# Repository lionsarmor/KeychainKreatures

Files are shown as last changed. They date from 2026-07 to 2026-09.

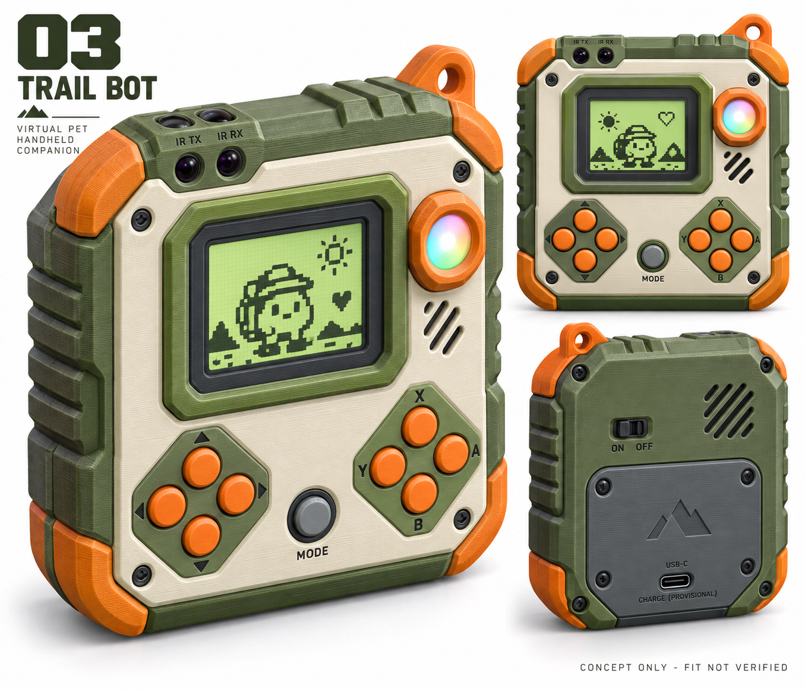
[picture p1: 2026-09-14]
docs/enclosure_concepts/03_trail_bot.png

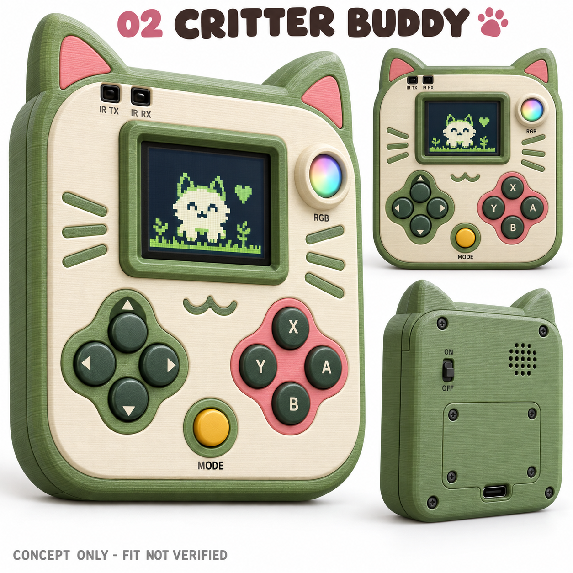
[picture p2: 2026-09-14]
docs/enclosure_concepts/02_critter_buddy.png

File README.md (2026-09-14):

# Keychain Kreatures

An ESP32-S3 virtual-pet and small handheld-game hardware project, designed around a repairable through-hole main-board kit and a separate factory-assembled power board.

**Current hardware: main C.6 + power P.4. Engineering prototypes—not a tested, certified or production-ready toy.** Main is 96 × 105 × 1.6 mm; power is now 50 × 50 × 1.6 mm. The power board needs independent removable case supports; mounting patterns do not match. Physical component fit, battery/case selection, factory DFM approval and powered qualification remain open.

## Current projects and downloads

| Board | Editable KiCad 10 project | Five-prototype review package | Gerbers and drills |
|---|---|---|---|
| Main C.6 · 2 copper layers | [Open main project](KK_main_module/KK_main_module.kicad_pro) | [Full main ZIP](KK_main_module/manufacturing/KK_MAIN_C6_P4_PAIRING_5_PROTOTYPE_REVIEW_2026-09-12.zip) | [Main fabrication ZIP](KK_main_module/manufacturing/KK_MAIN_C6_P4_PAIRING_GERBERS.zip) |
| Power P.4 · 4 copper layers | [Open power project](KK_power_module/KK_power_module.kicad_pro) | [Full power ZIP](KK_power_module/manufacturing/KK_POWER_P4_5_PROTOTYPE_REVIEW_2026-09-12.zip) | [Power fabrication ZIP](KK_power_module/manufacturing/KK_POWER_P4_GERBERS.zip) |

Download the repository or a **full review ZIP** to open a project with its local libraries, models and documentation. Install the KiCad 10 standard footprint and 3D libraries as well. For GitHub ZIP downloads, use the file page's download/raw action. The full review packages include fabrication files, BOMs, placement and test-point maps, schematic/assembly PDFs, source CAD, datasheets and verification evidence. The separate fabrication ZIPs do not replace the assembler's full review package.

[Start here](START_HERE.md) · [Documentation index](docs/README.md) · [Release notes](CHANGELOG.md) · [Release hashes](docs/CURRENT_RELEASE_INDEX.json)

Ordering the five engineering samples? Use the [PCBWay step-by-step submission folder](PCBWay/README.md): separate main/power Gerber uploads, power BOM/centroid, DFM questions, approval checklist and delivery/testing documents. This is a local preparation packet, not an order or manufacturing approval.

## Hardware in this revision

- Socketed **ESP32-S3 SuperMini**. Confirm the delivered seller revision, pinout and actual flash/PSRAM; do not infer N16R8 specifications from the SuperMini name.
- Existing ST7789V2 screen in landscape, **280 × 240 pixels**, and a separate socketed 3.3 V microSD reader. SD storage is not extra executable RAM.
- Nine soft controls: D-pad left, four action buttons right, one center function button, all below the screen. MCP23017 GPIO expansion.
- PWM audio with a TDA2822L amplifier, speaker connector and switched amplifier supply; vibration motor output with suppression.
- TSAL6200 infrared transmitter and TSOP38238 receiver, aimed toward the case opening. No sub-GHz radio.
- Separate socketed common-anode RGB LED and TLC5916 driver.
- Main board: **98 fitted through-hole positions**, all **43 resistors horizontal**, ten horizontal low-profile electrolytics, six flat-mounted TO-92 devices, removable IC/module sockets, JST connectors and **25 bare debug holes**.
- Power board: **108 fitted positions**, 28 rear test pads, USB-C charging input, battery protection, temperature interlock and three regulated output rails. This board is a **factory SMT subassembly**, not a student SMT soldering exercise.

All fitted electrical positions have resolving 3D model links. Some module and connector envelopes remain provisional; model coverage does not prove fit. Sockets, buttons and optical components necessarily retain height. The previous common-hole 20 mm spacer plan is superseded. Power placement, antenna clearance and independent support heights need a physical mock-up.

## Assembly and first power-up

New to electronics, or investigating a board that will not start? Use the [board-by-board troubleshooting guides and recording sheets](docs/troubleshooting/README.md). Begin with safety and unpowered checks; power-module live tests need a qualified instructor.

Read these before buying parts, soldering or powering a board:

1. [Main BOM and assembly/wiring guide](KK_main_module/assembly/ASSEMBLY_GUIDE.md), [reference BOM](KK_main_module/assembly/C6_BOM_BY_REFERENCE.csv), and [complete paired-kit extras](KK_main_module/assembly/C6_COMPLETE_KIT_EXTRAS.csv). Extras cover sockets, modules, mating plugs, wiring and provisional hardware; count them once per main+power pair.
2. [Print the stack review at actual size](docs/C6_P4_MECHANICAL_REVIEW.pdf), [front fit sheet](KK_main_module/assembly/C6_front_FIT_100_PERCENT.pdf) and [rear fit sheet](KK_main_module/assembly/C6_back_FIT_100_PERCENT.pdf). Measure the calibration line and dry-fit actual parts and plugged harnesses.
3. [Power fabrication/assembly requirements](KK_power_module/FABRICATION_REQUIREMENTS.md). Obtain manufacturer approval of the 0.4 mm WCSP, fine-pitch packages and **filled/capped/planarized via-in-pad** process. Ordinary via tenting is not equivalent.
4. [Power electrical review and current-limited first-power-up procedure](KK_power_module/assembly/P4_REVIEW_AND_TEST.md). Qualify power independently before attaching the populated main board. Real-cell testing requires a selected, documented cell and bonded thermistor.

Power **J3 → main J1**, keyed pin-for-pin:

| Pin | Rail |
|---|---|
| 1 | MCU_5V |
| 2 | GND |
| 3 | LOGIC_3V3 |
| 4 | ACT_3V2 |

**Never connect raw battery voltage to main J1. Power TP3/BAT_NEG is not TP4/GND; do not bypass battery protection with test-equipment grounds. Neither speaker output is ground.**

Charger USB carries **no data** to the ESP32. Do not combine ESP32 USB power and external main rails until exact-module reverse-feed behavior is qualified. Program the removable MCU separately for recovery. USB-A/default charging is deliberately slow and may not cover a running toy's load.

## Verification and remaining work

The issued C.6/P.4 sources passed fresh native ERC/DRC, connectivity and schematic-parity checks with **zero reported violations or opens**. [Static audit](docs/CURRENT_STATIC_AUDIT.json), [individual outline/hole audit](docs/CURRENT_STATIC_AUDIT.json) and package manifests identify exactly what was checked. Existing ignored-check settings are included in the native reports; clean reports are not a claim that every possible check was performed.

Run this lightweight saved-release consistency check from the repository root:

```sh
node tools/check_project.mjs
```

It verifies current source/package hashes, local assets, saved netlists and the inter-board interface. It does **not** rerun KiCad checks or simulate the circuit. See [tool instructions](tools/README.md) before running anything else. Do not rerun historical placement/route generators on finished CAD.

Remaining qualification includes physical socket/plug/case fit, battery/NTC selection, speaker power rating, simultaneous-load capacity, capacitor transient/ripple behavior, regulator/charger temperatures, USB behavior, rail sequencing, GPIO back-powering, RF performance and applicable product safety/EMC review. In particular, the older main 3.3 V reservation was 0.5 A while power screening used 0.4 A; reconcile measured peak demand and margin before approving the complete toy. Screening targets are not measured ratings.

## Firmware status

The planned virtual pet, games/apps, browser/Wi-Fi uploads, trading, save recovery and OTA workflow are **not implemented or validated by this hardware release**. Follow the current schematic and assembly guide for bring-up firmware. The historical ESP32-C3/MAX98357A/PCF8574 test sketch from earlier Git history is not compatible with this S3/MCP23017/TDA2822L board and must not be used as its factory test.

## History, contributions and licensing

The files directly inside **KK_main_module are now C.6**, and those directly inside **KK_power_module are P.4**. Older C.5/P.2 projects, intermediate routes, obsolete documents and one-off generators have been moved into [the cleanup archive](revisions/2026-09-12_current_only/). Use [revisions](revisions/README.md) for recovery; archived reports retain their original findings and are not current instructions. See [contribution guidance](CONTRIBUTING.md).

The project is intended for open development, but a project-wide license has **not yet been selected**. The OSHW silkscreen logo is not a certification or a substitute for license terms. Third-party KiCad assets and manufacturer documents retain their respective terms; do not assume this repository relicenses them. Thanks to the KiCad, Espressif and component-library communities.

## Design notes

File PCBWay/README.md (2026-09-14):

# PCBWay — C.6 main + P.4 power prototype submission

Start with [00_Order_Setup/START_HERE.md](00_Order_Setup/START_HERE.md). This folder prepares **two separate PCBWay jobs**: five bare main boards and five assembled power boards. It does not place an order or authorize fabrication.

| Step | Folder | What to do |
| --- | --- | --- |
| 0 | [Order setup](00_Order_Setup/START_HERE.md) | Read specifications and copy the quote-request message. |
| 1 | [Main Gerbers](01_Main_C6/01_Gerber_Upload/README.md) | Upload the main Gerber ZIP to its own PCB job. |
| 2 | [Power Gerbers](02_Power_P4/01_Gerber_Upload/README.md) | Upload the power Gerber ZIP to a separate four-layer PCB + assembly job. |
| 3 | [Power BOM](02_Power_P4/02_BOM_Upload/README.md) | Upload the fitted-parts BOM; ask for sourcing/attrition quote. |
| 4 | [Power placement](02_Power_P4/03_Pick_and_Place_Upload/README.md) | Upload SMT centroid and attach mixed-operations file. |
| 5 | [Assembly drawings](02_Power_P4/04_Assembly_Drawings/README.md) | Attach polarity, schematic and assembly references. |
| 6 | [Manufacturing review](03_Factory_DFM_and_Questions/README.md) | Resolve process, sourcing and inspection questions. |
| 7 | [Approval and payment](04_Approval_and_Payment/README.md) | Review final quote and CAM/BOM approvals before payment/release. |
| 8 | [Delivery and testing](05_Delivery_and_Testing/README.md) | Retain inspection results and test samples safely on arrival. |

Use the files listed in [UPLOAD_MAP.csv](00_Order_Setup/UPLOAD_MAP.csv). The complete package ZIPs under each board's `05_Full_Review_Package` folder are supplemental engineering references, **not** the Gerber-upload ZIPs. Folder numbering follows this project's workflow, not a promise of PCBWay's exact current screen order.

**Do not upload the entire project or this whole folder to a Gerber field.** Do not mix the two board designs in one upload or order five of each archive separately. Main assembly is not requested; its extra BOMs are reference only. No shell, battery, firmware programming or finished toy is ordered here.

Current source-of-truth remains the root KiCad projects and issued manufacturing packages. The PCBWay copies are a submission snapshot. `SOURCE_COPY_MANIFEST.json` records byte-identical source copies; `PACKAGE_MANIFEST.json` inventories the prepared files. Recheck these if the design changes. Keep supplier responses and receipts in the provided folders; never overwrite issued Gerbers with returned CAM changes without review.

Status: **ready for quote/DFM submission, not manufacturer-approved, not powered-tested**. Copies of saved verification reports are evidence of static checks, not functional certification.

Prepared against [PCBWay's assembly file requirements](https://www.pcbway.com/assembly-file-requirements.html) and [via-in-pad guidance](https://www.pcbway.com/helpcenter/ordering_parameter_instruction/Via_in_Pad.html). Technical approval is still required for this particular design.

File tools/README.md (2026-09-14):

# Current-project tools

- `package_pcbway.py`: prepares the root `PCBWay` submission folder from the unchanged issued release. Copies Gerber/review ZIPs and supporting files byte-for-byte; filters the native power positions into 104 SMT and four mixed/THT connector rows without coordinate changes. Refuses differing existing outputs. Run with `nice -n 15 taskset -c 0 python3 tools/package_pcbway.py`; use `--verify` for read-only copy/hash/link/centroid checks. Do not edit sealed upload files or regenerate over supplier records; a hardware revision requires a newly reviewed packet. No factory upload, purchase or approval is performed.

- `troubleshooting_guides.py`: generates the student/instructor HTML/PDF guides and blank CSV worksheets from their Markdown sources; checks pin/net references and released test-pad maps, and verifies CAD/issued ZIPs remain unchanged. Uses existing MarkdownIt and an isolated LibreOffice profile. Run sequentially with `nice -n 15 taskset -c 0`. It does not supply diagnostic firmware or perform physical tests.
- `print_guide_pdf.py`: private-profile LibreOffice PDF helper; adds page numbers and prevents table rows splitting across pages.
- `package_troubleshooting.py`: generates the printable factory fault form and a separate, hash-inventoried troubleshooting packet. Run after guide generation. It never replaces the issued fabrication packages.

Current native CAD is directly in KK_main_module and KK_power_module. These folders are C.6/P.4; all older designs and one-off generators are in [the cleanup archive](../revisions/2026-09-12_current_only/).

- `node tools/check_project.mjs`: read-only source/package hashes, saved netlist/interface checks, local assets, protected cleanup files and archive recovery integrity. Not a new powered or native CAD test.
- `node tools/github_preflight.mjs`: staged-publication checks for release/archive paths, documentation links, large files and common accidental credential/editor-state inclusions. Run after staging the intended changes, not during an unstaged move.
- `flat_stack_audit.py`: native static outline/mounting, flat-part/model, pad/net and independent track-width checks. Refreshes the current audit and power placement table, never routed CAD.
- `flat_stack_fit.py`: actual-size main front/back fitting PDFs generated from a temporary board copy.
- `flat_stack_report.py`: printable four-page review with separate actual-size mounting templates.
- `stack_release_native.py main|power`: native BOM/pad/net/model checks and assembly/connector/debug maps; it rewrites generated review tables/plots, not CAD.
- `current_only_cleanup.mjs`: completed one-time move script, retained as recovery evidence. It refuses to run again once its archive exists.

Run heavy tools sequentially with `nice -n 15 taskset -c 0`. Native Python tools use `flatpak run --command=python3 org.kicad.KiCad /absolute/path/to/tool.py`. Fit/report documents are generated artifacts; do not confuse updating a print sheet with issuing new manufacturing files.

The recovery manifest includes local-only editor history, KiCad preferences/locks and Python caches. These remain archived locally but are deliberately excluded from Git. The checker verifies them when present; `node tools/check_project.mjs --published` checks the publishable subset. All CAD, manufacturing packages and material recovery files are required in either mode.

Historical placement, route-import, power generation and release scripts have been packed away. They retain their original source assumptions and are not supported commands from their relocated paths. Restore a complete historical scratch workspace using the move map if needed; never run them over current CAD.

New C6/P4 review/Gerber ZIPs are hash-bound snapshots. Main C.6 CAD and fabrication geometry are unchanged; power P.4 is compact. docs/CURRENT_RELEASE_INDEX.json lists the new packages; old snapshots are archived intact. Any future circuit edit needs a new checked release, not merely updated hashes. No tool here orders boards.

- `promote_compact_power.py`: completed guarded one-time promotion; refuses to overwrite its archive.
- `compact_release_docs.py`: generates current guides from preserved pre-promotion text; run only before sealing a release.
- `current_release.py`: fresh sequential native checks and immutable C6/P4 packages; refuses existing outputs.
- `power_compact_candidate.py`: historical one-shot candidate builder, not a current routing command. Its source assumptions refer to the pre-promotion P.3 root.

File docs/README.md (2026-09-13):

# Documentation index — main C.6 / power P.4

Start with the [repository overview](../README.md) and [project/file map](../START_HERE.md). This index distinguishes current build instructions from preserved historical work.

## Current build and release documents

For first-time students and incoming factory failures, use the [separate main/power troubleshooting guides and worksheets](troubleshooting/README.md). They separate supervised student checks from technician-only tests and include all 53 test pads.

| Topic | Current document |
|---|---|
| Main assembly, orientation and wiring | [C.6 assembly guide](../KK_main_module/assembly/ASSEMBLY_GUIDE.md) |
| Main electrical parts | [C.6 BOM by reference](../KK_main_module/assembly/C6_BOM_BY_REFERENCE.csv) |
| Sockets, modules, mating plugs and hardware | [Complete main+power kit extras](../KK_main_module/assembly/C6_COMPLETE_KIT_EXTRAS.csv) |
| Power BOM, positions and maps | [P.4 release checks](../KK_power_module/release_checks/) |
| Power assembly and bench procedure | [P.4 review and first-power-up](../KK_power_module/assembly/P4_REVIEW_AND_TEST.md) |
| Factory process requirements | [Main C.6](../KK_main_module/FABRICATION_REQUIREMENTS.md) · [Power P.4](../KK_power_module/FABRICATION_REQUIREMENTS.md) |
| Printable mechanical review | [Stack review PDF](C6_P4_MECHANICAL_REVIEW.pdf) |
| Actual-size main fitting | [Front PDF](../KK_main_module/assembly/C6_front_FIT_100_PERCENT.pdf) · [Back PDF](../KK_main_module/assembly/C6_back_FIT_100_PERCENT.pdf) |
| Design changes and unresolved limits | [Flat-stack review](FLAT_STACK_REWORK.md) |
| Source and release integrity | [Release index/hashes](CURRENT_RELEASE_INDEX.json) · [Static audit](CURRENT_STATIC_AUDIT.json) |
| Current troubleshooting records | [C.6 checklist](../KK_main_module/assembly/TROUBLESHOOTING_C6_CHECKLIST.csv) · [P.4 checklist](../KK_power_module/assembly/TROUBLESHOOTING_P4_CHECKLIST.csv) · [Measurement sheets and factory report](troubleshooting/README.md) |
| Safe project tooling | [Tools](../tools/README.md) · [Contributing](../CONTRIBUTING.md) |

Current releases and ZIPs are immutable snapshots. Later documentation updates at the repository root do not change the hash-verified snapshot contents or imply another electrical review. After any CAD edit, repeat native checks and issue a new source-bound manufacturing revision.

## Historical documents

The P.2 reviews, earlier cleanup report and original source notes now live in [the cleanup archive's docs folder](../revisions/2026-09-12_current_only/docs/). They are historical evidence, not current P.4 instructions or overrides of later decisions. Older component investigations/BOMs, failed routes and generation scripts are archived with their original relative paths in the same cleanup archive.

Use [revisions/README.md](../revisions/README.md) and its move manifests for recovery. Do not rewrite an old signed report to make it appear to have checked a new design. Use only current C.6 main and P.4 power packages. P.4 is 50 × 50 mm, but old P.2 files of the same size are not the current release. Main remains 96 × 105 mm; use separate mounting supports.

Native CAD checks passed, but factory DFM/supply approval, physical fit, battery/case selection and powered testing remain open. These are engineering samples, not finished student toys.

The previous oversized P.3 board, C6/P3 packages and shared-hole reports are preserved in [the compact-revision archive](../revisions/2026-09-12_power_compact/P3_previous/). Main C.6 CAD and fabrication geometry are unchanged; its new review package replaces obsolete shared-stack documentation.

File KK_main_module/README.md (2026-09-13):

# Main board — C.6, all resistors flat

[Student troubleshooting PDF](assembly/TROUBLESHOOTING_MAIN_C6.pdf) · [Guide and worksheets](../docs/troubleshooting/README.md)

Open [KK_main_module.kicad_pro](KK_main_module.kicad_pro) or [KK_main_module.kicad_pcb](KK_main_module.kicad_pcb) directly from this folder. **This is now the current C.6 board, not the old C.5 root.**

96 × 105 × 1.6 mm, two copper layers, R4 rounded corners and its own mounting pattern. Compact power P.4 is 50 × 50 mm and needs separate supports. All 43 resistors are horizontal; ten electrolytics and six TO-92 bodies lie flat. There are 98 fitted through-hole electrical positions and 25 bare debug holes. Sockets, optical parts and buttons retain their functional height.

- [Assembly/wiring](assembly/ASSEMBLY_GUIDE.md) · [Reference BOM](assembly/C6_BOM_BY_REFERENCE.csv) · [Complete paired-kit extras](assembly/C6_COMPLETE_KIT_EXTRAS.csv)
- [Front actual-size fit](assembly/C6_front_FIT_100_PERCENT.pdf) · [Rear actual-size fit](assembly/C6_back_FIT_100_PERCENT.pdf)
- [Manufacturing packages](manufacturing/README.md) · [Verification and maps](release_checks/)
- [Both current projects](../START_HERE.md) · [Archived old designs](../revisions/2026-09-12_current_only/)

Local libraries, models and datasheets sit alongside the project. Install KiCad 10 standard libraries too. Use the current schematic and pin labels for orientation. The prior C5_relayout and old assembly/component-review files are archived, not mixed into this directory.

Prototype only: physical part/plug fit, battery/case selection, peak-load/thermal behavior, firmware and powered safety qualification remain pending. Do not connect raw battery to main J1 or combine ESP32 USB and external rails until backfeed is qualified.

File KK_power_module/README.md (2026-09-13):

# Power board — current P.4 compact module

[Troubleshooting PDF](assembly/TROUBLESHOOTING_POWER_P4.pdf) · [Guide and worksheets](../docs/troubleshooting/README.md). Live power tests require a qualified instructor/technician.

Open [KK_power_module.kicad_pro](KK_power_module.kicad_pro) or [KK_power_module.kicad_pcb](KK_power_module.kicad_pcb) directly from this folder. P2_compact and old work directories are archived.

50 × 50 × 1.6 mm, four copper layers, R3 corners, four 2.2 mm holes at (3,3), (47,3), (3,47), (47,47) mm. It needs independent case supports; main C.6 remains 96 × 105 mm. The routed electrical core is preserved. There are 108 fitted parts, 14 ICs and 28 rear bare test pads. Power remains a factory SMT subassembly, not a student SMT soldering kit.

- [Assembly/electrical review and first-power-up](assembly/P4_REVIEW_AND_TEST.md)
- [Factory fabrication requirements](FABRICATION_REQUIREMENTS.md)
- [BOM, coordinates, connector/test-pad maps and reports](release_checks/)
- [Manufacturing packages](manufacturing/README.md) · [Both projects](../START_HERE.md)

J3 → main J1: pin1 MCU_5V, pin2 GND, pin3 LOGIC_3V3, pin4 ACT_3V2. Battery return BAT_NEG is not GND. Charger USB carries no data. USB-A/default charging is deliberately slow; do not combine ESP32 USB power and external main rails until qualified.

Before ordering, obtain factory approval of the fine-pitch WCSP/QFN packages and filled/capped/planarized via-in-pad process. Actual plug/stack clearance, selected battery/NTC, load margin, charging/thermal behavior, rail sequencing and backfeed need physical and powered tests. Screening targets are not validated ratings.

The project uses KiCad 10 standard libraries plus the local libraries/models. All fitted model paths resolve, but models are not certified mating assemblies.

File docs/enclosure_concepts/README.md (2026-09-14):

# Keychain Kreatures enclosure concepts

Concept artwork, not dimensionally verified CAD, printable STLs, or a manufacturing release. No PCB, circuit, or Gerber changes were made for these concepts.

The user selected Pixel Pod. **Current direction:** [round 3: simplified front/back shell with rear battery hatch](pixel_pod_round3/README.md). [Round 2: separate skins and click-in carriers](pixel_pod_round2/README.md) is preserved as an earlier construction exploration, not the latest choice. The original artwork below remains the initial style reference.

## Three starting points

| Concept | Artwork | Direction and tradeoff |
| --- | --- | --- |
| 01 Pixel Pod | [Concept sheet](01_pixel_pod.png) | Clean retro capsule; the simplest starting point for a serviceable enclosure with few decorative pieces. |
| 02 Critter Buddy | [Concept sheet](02_critter_buddy.png) | Broad creature ears and shallow cheek details; strongest pet identity, with a larger silhouette. |
| 03 Trail Bot | [Concept sheet](03_trail_bot.png) | Faceted bumper and grip ribs; a playful field-companion appearance, with more accent parts. No impact rating is implied. |

Recommendation: start with Pixel Pod's basic construction, or use that construction beneath Critter Buddy's face and ear silhouette. Colors are suggestions for separately printed parts, not a requirement for a multicolor printer. Printed button caps do not by themselves make switches softer.

## Hardware the CAD must accommodate

- Main board C.6: 96 × 105 mm, 1.6 mm thick, rounded corners. The shell must be larger than this; these are chunky handheld concepts, not tiny keyfobs.
- Power board P.4: 50 × 50 mm, 1.6 mm thick, on its own supports behind the main board. Its mounting pattern is different from the main board's.
- Existing 280 × 240 landscape display at upper center; do not substitute a larger screen because of artistic proportions in the images.
- Nine controls below the screen: four direction switches left, four action switches right, one mode/function switch centered and slightly lower.
- One RGB LED near the upper right. The existing front RGB assembly envelope is about 22.1 mm from the PCB; verify the socket and physical part before sizing its protective pod.
- Rear ESP32/socket envelope is about 15.3 mm from the PCB. Final depth also needs solder-tail clearance, insulation, supports and wiring; a thin phone-like enclosure is not a valid assumption.
- One IR transmitter (D1, TSAL6200) and one receiver (U2, TSOP38238), looking out through top-edge openings. Preserve their actual locations and orientation, and do not assume ordinary printed filament transmits infrared adequately.
- Keep metal, battery and wiring out of the top-center ESP32 antenna clearance region. Do not place a decorative metal eyelet or screw there.
- One externally accessible charging USB-C port on the power module; it does not carry application data. Preserve internal service access to the ESP32 module.
- Keep JST connectors, SD-card access, speaker/motor wiring and debug pads serviceable. Confirm cable bends and connector unplugging space before closing the case design.
- Battery part, retention, exact position and enclosure depth are not finalized. The rear service-panel artwork is not a validated battery compartment.

## FDM construction brief

Use a flat-printable face assembly and a separate deep rear tray, with screw-removable access and captured button caps. Separate accent parts allow different filament colors without requiring automatic material changes. Prefer broad ears, ribs and attachment features over fragile protrusions.

Choose print orientation and part splits in CAD, not from the renders. Chamfer bed-facing transitions where a rounded underside would create difficult overhangs. Prototype button guides, fastener bosses and mating edges as small fit coupons before printing a complete enclosure. Printer calibration, material and orientation determine clearances; there is no universal press-fit allowance. These choices follow [Prusa's modeling-for-3D-printing guidance](https://help.prusa3d.com/article/modeling-with-3d-printing-in-mind_164135).

Support-free printing, screw strength, button travel, heat behavior and drop resistance have not been demonstrated. A printed shell is not battery safety certification. Keep students' access to replaceable parts in the final design rather than gluing the enclosure shut.

## Visual review and known artwork deviations

All three sheets communicate the nine-button arrangement, upper-right RGB feature, separate rear enclosure and distinct styling directions. They are intentionally not dimensioned drawings.

- The rendered screen/bezel proportions are approximate, and the pixel graphics do not imply changing the actual color display to monochrome.
- Some views place IR optics on the front face rather than the actual top-edge direction. Trail Bot's large perspective view also invents an extra pair of optics; ignore those duplicates. The hardware remains exactly one transmitter and one receiver.
- Rear USB, switch, speaker grille, service panel and screw locations are placeholders, not approved cutouts. The artwork does not establish acoustic alignment, SD access or mounting-hole alignment.
- Shown curved surfaces, labels and seams may require different part splits or embossed details in printable CAD.

## Next step after choosing a direction

1. Import both current board assemblies into mechanical CAD; measure actual sockets, display and LED against their models.
2. Select and measure the battery, speaker, wiring and fastening hardware; establish the power-board orientation and safe clearances.
3. Build an interference-checked internal layout, including antenna clearance, accessible connectors and button travel/stops.
4. Design the shell around those envelopes and test small mating/fastener/button coupons.
5. Print a fit prototype, assemble without forcing parts, and check service access before publishing STLs.

## Generation record

Generated using the built-in `image_gen` tool, one call per concept. The final prompt set is preserved in [prompts.json](prompts.json); each call used `common_prompt` followed by its variant's `prompt`, with [the current main-board front render](../../KK_main_module/reports/main_front.png) as a layout reference. The image-generation workflow kept aesthetic exploration separate from verified mechanical design.

All three delivered PNGs are saved alongside this README. Original generated files were preserved. These enclosure files are local concept assets; the troubleshooting documentation was pushed separately to GitHub's `development` branch at commit `d54a51a03c62d845d911ff6748cdaaaa08349c86`.

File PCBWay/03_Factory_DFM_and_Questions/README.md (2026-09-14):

# Manufacturing review — approval required

Give PCBWay the fabrication requirements and via-in-pad list here. Use DFM_RESPONSE_CHECKLIST.csv to track written answers; every item starts PENDING. Save their returned PDFs, CAM images and emails under Supplier_Responses.

Required subjects include layer count/stackup, copper and drills, filled/capped/planarized component-pad vias, U13 WCSP and fine-pitch packages, finish/stencil, actual BOM manufacturers and substitutions, centroid convention, connector operations, electrical test, hidden-joint inspection and cost.

Ordinary tenting is not equivalent to filled/capped via-in-pad processing. [PCBWay describes the resin-fill/electroplated-cap approach](https://www.pcbway.com/helpcenter/ordering_parameter_instruction/Via_in_Pad.html). Capability in general does not constitute approval of these boards.

Engineering acceptance of manufacturability does not certify circuit function, battery safety or the finished toy. Do not treat the saved zero-violation CAD reports as measured functional tests.

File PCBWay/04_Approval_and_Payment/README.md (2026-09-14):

# Before payment / production release

Nothing has been ordered or paid for. This folder records your eventual decisions, not a preapproved purchase.

- [ ] Confirm main is five bare C.6 PCBs and power is five assembled P.4 boards, with attrition separate.
- [ ] Read all DFM answers and approve the actual stackup, finish, via-in-pad process and assembly capability.
- [ ] Approve exact manufacturers/MPNs and every substitution individually.
- [ ] Confirm both upload previews match the current outlines, holes and layer counts.
- [ ] Confirm inspection and electrical-test scope; distinguish bare-board tests from any separately agreed functional tests.
- [ ] Review total price including parts, attrition, tooling/stencil, inspection, shipping and taxes.
- [ ] Confirm your shipping/contact details directly with PCBWay.
- [ ] Approve the final files and quote in writing only after unresolved questions are closed.

Save approved quote and receipt in Receipts_and_Approvals. Don't store passwords, card details or identity documents in this Git project. Supplier responses/receipts are excluded from Git by the local .gitignore rules; do not force-add sensitive documents.

Case fit and powered behavior remain prototype qualification work. If the power process is too expensive, stop and consider a separately reviewed revision; do not silently cheapen the via process or swap U13.

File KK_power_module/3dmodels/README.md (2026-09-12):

# P.3 populated models — matching-stack power board

All 108 fitted electrical positions now have resolving model links. Fourteen formerly missing attachments were repaired, including connectors, switch, inductors and IC packages.

[P3_MODEL_REPAIR_MANIFEST.json](P3_MODEL_REPAIR_MANIFEST.json) identifies manufacturer-maximum, nominal and conservative envelopes, references and hashes. MANIFEST.json records inherited stock-model provenance; its earlier missing-model list is historical, superseded by the P.3 repair manifest and current PCB attachments.

These simplified models are not vendor-certified mating assemblies. JST plug bodies, wire bends, battery and final enclosure are not modeled or qualified. USB/case opening and switch actuator travel require physical checks. Power component side faces the rear cover; power front-view X is mirrored relative to the main front in the actual stack. Keep the upper antenna region free of metal.

KiCad stock models require the KiCad 10 standard 3D libraries and retain their upstream license with library exception: https://www.kicad.org/libraries/license/ . Project-owned VRML models have STEP twins. A resolving model link and clean DRC are not physical or electrical qualification.

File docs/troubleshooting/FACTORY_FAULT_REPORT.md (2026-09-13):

# Keychain Kreatures — one-board fault report

Complete one copy per board. Photograph before repair. Do not attach a real battery just to fill in this form. Mark unavailable tests BLOCKED or NOT RUN.

## Identification

- Board: MAIN C.6 / POWER P.4 (circle one).
- Serial, supplier, order and batch/lot: ____________________
- Date received / tester / instructor: ____________________
- Bare PCB, partly assembled or fully assembled: ____________________
- Exact release ZIP name and SHA-256: ____________________
- Factory-approved BOM substitutions: ____________________
- Main: ESP32, display and SD-reader markings: ____________________
- Main: diagnostic firmware version/hash and known-good evidence: ____________________

## First failure

- What was expected; what actually happened? ____________________
- First failed guide step and preceding passing step: ____________________
- Repeatable or intermittent? ____________________
- Did another unit pass the identical setup? Its serial: ____________________
- Smoke, smell, abnormal heat or current-limit event? ____________________
- Was a real cell connected? Approved part and condition: ____________________
- Any rework, reflash/erasure, jumper, substitution or forced connector? ____________________

## Setup — attach a labeled photograph/diagram

- Source model, voltage, current limit and isolation: ____________________
- Attached cables, loads, modules and instruments: ____________________
- Where does every instrument ground/earth connect? ____________________
- Power: how is BAT_NEG kept free of an external bypass to GND? ____________________
- Ambient temperature and temperature-measurement method: ____________________
- Meter/scope model, ranges, probe attenuation and test state: ____________________

Write both probe points. A number without its operating state or reference is not enough.

| Test / signal | Red / reference points | Source, switch, load, firmware state | Expected context | Reading / units |
|---|---|---|---|---|
| | | | | |
| | | | | |
| | | | | |
| | | | | |
| | | | | |
| | | | | |

Attach the completed checklist and measurement CSV. Scope captures must show channel scales, timebase, trigger, probe setup and board identity. Do not include Wi-Fi passwords or unrelated personal data.

## Requested factory response

- Compare the first failing stage with the exact schematic, BOM and Gerbers.
- Supply bare-board electrical-test results, assembly/hidden-joint inspection images and all substitutions for the lot.
- Power: confirm the approved via-in-pad process and WCSP/QFN assembly details.
- Identify the cause before proposing a part swap or undocumented jumper.
- Advise whether to preserve the unit untouched for return; obtain approval before rework.
- Provide corrective action, affected lot scope and post-repair test results.

## Repair and retest

| Date / person | Confirmed cause | Approved repair / part and lot | Retested steps | Outcome |
|---|---|---|---|---|
| | | | | |
| | | | | |
| | | | | |

Final status: PASS AT RECORDED CONDITIONS / FAIL / BLOCKED / NOT RUN.

Instructor signature/date: ____________________

Passing is not production, battery-safety, USB, EMC or toy certification. Coordinate damaged-battery handling/return with the responsible lab and supplier; do not put it in an ordinary PCB return parcel.

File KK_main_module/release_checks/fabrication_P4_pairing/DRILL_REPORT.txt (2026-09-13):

Drill report for KK_main_module.kicad_pcb
Created on 2026-09-12T22:34:28

Copper Layer Stackup:
    =============================================================
    L1 :  F.Cu                      front
    L2 :  B.Cu                      back

Drill file 'KK_main_module-PTH.drl' contains
    plated through holes:
    =============================================================
    T1  0.300mm  0.0118"  (26 holes))
    T2  0.400mm  0.0157"  (8 holes))
    T3  0.500mm  0.0197"  (1 hole)
    T4  0.750mm  0.0295"  (4 holes))
    T5  0.800mm  0.0315"  (201 holes))
    T6  0.900mm  0.0354"  (36 holes))
    T7  0.950mm  0.0374"  (4 holes))
    T8  1.000mm  0.0394"  (54 holes))
    T9  1.050mm  0.0413"  (18 holes))
    T10  1.100mm  0.0433"  (5 holes))

    Total plated holes count 357

Drill file 'KK_main_module-NPTH.drl' contains
    unplated through holes:
    =============================================================
    T1  2.200mm  0.0866"  (4 holes))

    Total unplated holes count 4

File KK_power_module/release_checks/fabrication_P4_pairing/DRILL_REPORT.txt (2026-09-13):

Drill report for KK_power_module.kicad_pcb
Created on 2026-09-12T22:34:55

Copper Layer Stackup:
    =============================================================
    L1 :  F.Cu                      front
    L2 :  In1.Cu                    in1
    L3 :  In2.Cu                    in2
    L4 :  B.Cu                      back

Drill file 'KK_power_module-PTH.drl' contains
    plated through holes:
    =============================================================
    T1  0.200mm  0.0079"  (216 holes))
    T2  0.300mm  0.0118"  (44 holes))
    T3  0.600mm  0.0236"  (4 holes)  (with 4 slots)
    T4  0.750mm  0.0295"  (2 holes))
    T5  0.950mm  0.0374"  (4 holes))
    T6  1.700mm  0.0669"  (2 holes))

    Total plated holes count 272

Drill file 'KK_power_module-NPTH.drl' contains
    unplated through holes:
    =============================================================
    T1  0.650mm  0.0256"  (2 holes))
    T2  0.900mm  0.0354"  (2 holes))
    T3  2.200mm  0.0866"  (4 holes))

    Total unplated holes count 8

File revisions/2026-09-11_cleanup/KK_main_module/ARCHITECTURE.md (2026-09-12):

# Compact architecture — current candidate

2026-09-10. Current requirements are in [DESIGN_BRIEF.md](DESIGN_BRIEF.md); parts, GPIO numbers, schematic and mechanical outline are not released. Latest [component decisions](COMPONENT_DECISIONS.md) approve a THT-pin regulator module, relax the fixed screen and recommend 16 MB flash/8 MB PSRAM plus wired speaker/ERM candidates. These supersede earlier candidate assumptions below, not qualification gates.

## Hardware partition

RODDY power PCB → reviewed main-board 3.3 V regulation → compact ESP32-S3/PSRAM core. Separate TFT, battery, speaker and motor have defined connectors/retention rather than being assumed part of the MCU module. Charger/protection stays on RODDY. No separate sub-GHz radio or expansion connector is reserved.

Mandatory assembly strategy: **through-hole-only main PCB for student assembly**, including a preassembled ESP32-S3/PSRAM module attached by legs/pin headers or THT sockets. The former proposal to factory-place a fine-pitch MCU/regulator section directly on the main PCB is withdrawn. No required signals may rely on student soldering to hidden underside/SMD pads. Audio, GPIO, IR and haptics use THT circuitry, not assumed extra breakouts. Regulation remains a qualification gate; no bare SMT regulator on the main PCB and no unapproved power-board redesign. See [student-kit requirements](STUDENT_KIT_REQUIREMENTS.md). Start with two-layer routing and sensible ground continuity; layer count cannot excuse an assembly-method violation.

- Display: separate affordable SPI color module; diagonal and resolution are now open. SPI clock/data/CS/DC, reset and controlled backlight remain the interface starting point. Exact backlight circuit, supply requirements and connector remain open.
- Buttons: four directions, A/B/X/Y and Function. First compare direct GPIO for all nine against PCF8574N DIP-16 for eight plus direct Function/wake. Avoid adding the DIP expander if the selected core has sufficient GPIO and direct routing fits better.
- Candidate PCF8574 map: P0 UP, P1 DOWN, P2 LEFT, P3 RIGHT, P4 A, P5 B, P6 X, P7 Y. Write all ones before input use (quasi-bidirectional port), run at ≤100 kHz, apply external pulls as needed, poll every ~2 ms during play and debounce per measured switches. Do not spend any of these eight bits on IR or status. Verify all simultaneous-button combinations. Source: [TI PCF8574](https://www.ti.com/lit/ds/symlink/pcf8574.pdf). The DOCX's MCP23008-E/P PDIP-18 remains a separate candidate; its register/reset/interrupt behavior is different. Compare before selecting an expander; do not treat these devices as drop-in equivalents.
- Function connects directly to a verified wake-capable, non-strapping pin with a defined idle bias. Only Function wake is initially promised. Expander INT is optional notification, not timestamped capture. [S3 sleep/wake documentation](https://docs.espressif.com/projects/esp-idf/en/stable/esp32s3/api-reference/system/sleep_modes.html).
- For the MCP23008 alternative, define RESET/address pins and pull-ups explicitly. Its interrupt-capture register holds a port snapshot until cleared; it is not a timestamped pulse queue either. Verify any-button wake sequencing independently. [Microchip datasheet](https://ww1.microchip.com/downloads/aemDocuments/documents/APID/ProductDocuments/DataSheets/MCP23008-and-MCP23S08-Data-Sheet-DS20001919.pdf).
- IR receiver: direct MCU RMT capture, filtered supply, correct carrier/protocol. IR LED: RMT-controlled current-limited transistor driver. Both shut down safely at idle; emitter off through reset.
- Audio: qualify a DIP-8 low-voltage amp with filtered PWM input. NJM2073D is an obsolete-stock experiment; HT82V739 DIP is a sourcing/bench candidate, not an approved drop-in. Keep room for THT filter/bias/bulk components. Any alternate conversion/amplifier path must meet the THT requirement; do not adopt bare SMT I2S audio as a fallback.
- Haptics: driver chosen for actual ERM or LRA actuator. ERM needs flyback handling and stall-current limit; do not apply the same circuit blindly to an LRA.
- Battery/status: protected sensing and level conditioning; never direct J5-to-MCU wiring. RODDY hard switch remains distinct from Function sleep/wake. Details: [POWER_INTERFACE.md](POWER_INTERFACE.md).
- Programming: prefer the preassembled processor module's USB port or a THT service header with EN/BOOT/recovery access. Do not add an SMT USB receptacle to the main PCB. No second charger or uncontrolled USB power connection; review the module's regulator input/output and powered-off paths rather than blindly driving a rail backward.

The [functional I/O budget](io_requirements.csv) totals 20 direct functional signals with a single-PWM audio path and button expander, before optional expander INT. Native USB adds two fixed pins; UART recovery adds two if retained. Three-wire I2S adds two signals versus single PWM. Direct nine-button wiring adds six net signals compared with I2C + Function, while removing the expander. This count intentionally keeps status, shutdown and resets independent; some could be consolidated after a circuit-level review, not guessed away to fit a tiny development board.

Select final GPIOs only against the exact module's flash/PSRAM occupancy, boot straps, USB mapping and exposed pads. The archived WROOM map is not compatible evidence for a new core. Preserve antenna keepouts in all three dimensions including display metal, battery, adjacent board and keyring.

## Software and memory

Firmware owns the launcher, pet state, input, display, audio, time, power and trading. Original games use a small stable C host API. Do not make Game Boy ROM emulation part of the acceptance criteria.

Store app packages/assets in a filesystem separately from protected/versioned pet saves and settings. Install to staging, validate ID/API version/checksum/size, then atomically activate using a recoverable manifest. Apply quotas and preserve old package or recovery metadata through interrupted updates. Add authenticity/signature policy before accepting untrusted network packages.

Prototype separately installable C-compiled WebAssembly apps using a narrow host API; benchmark one scrolling game with sampled audio before choosing the runtime and flash capacity. [ESP-WASMachine](https://github.com/espressif/esp-wasmachine) is an experimental starting point, not proof of a finished safe app platform. Arbitrary native C binaries cannot simply be copied into a filesystem and executed. Restrict host imports, filesystem access, memory and execution time; pet ownership stays firmware-owned.

One RGB565 full framebuffer is 240 × 280 × 2 = 134400 bytes; two are 268800 bytes. At 30 full frames/s the raw pixel payload is 32.256 Mbit/s, excluding command/transfer overhead. Use partial updates, bounded frame rates and sprites to save power. Keep DMA buffers in memory supported by the chosen driver; PSRAM presence does not make every buffer DMA-compatible.

Aim for 8–16 MB flash and ≥2 MB PSRAM where compact implementation permits. The MINI-N4R2 actually has only 4 MB flash. Do not issue a partition table until firmware/runtime builds establish space for update/recovery, pet data and several realistic games. Extra SPI storage is not free in area, power or GPIO; microSD is not assumed.

## Trading and power behavior

Use paired encrypted ESP-NOW for nearby trading with on-screen consent and a compatible Wi-Fi channel. Built-in radio remains despite rejecting sub-GHz. The radio's send callback is not proof that the other application saved a transfer. Source: [Espressif ESP-NOW](https://docs.espressif.com/projects/esp-idf/en/stable/esp32s3/api-reference/network/esp_now.html).

Persist transaction/peer/pet IDs and state digests; lock offered pets before commit. Durably record received commits before application acknowledgement. Make retries idempotent and resume reconciliation after power loss. Do not unlock an in-doubt pet merely on timeout when the peer may have committed. Test interruption at every step. This addresses ordinary failures, not cheating by modified firmware or restored flash snapshots.

Keep simulation event-driven; checkpoint meaningful changes instead of every frame. Disable backlight, audio, haptics and IR at idle, bound wireless windows, and prevent back-powering switched-off peripherals through GPIO. Deep sleep while powered can preserve timekeeping; elapsed real time through a hard disconnect needs an independent RTC or later time sync. No always-on RTC is currently included.

## Implementation gate

Latest workflow: actual component envelopes and exact part/circuit qualification → trial board placement, control ergonomics and stack clearances → final board outline/placement and schematic review → routing → ERC/DRC and assembly review → mechanical handoff for the user's shell modeling → physical integration tests. See [board-first plan](BOARD_FIRST_PLAN.md). Full enclosure CAD is no longer a prerequisite for board work. Unresolved power-path capacity and battery-life targets remain gates. No step is represented as completed simply because a preceding document exists.

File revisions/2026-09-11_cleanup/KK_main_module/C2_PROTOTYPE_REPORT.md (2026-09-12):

# Main-board C.2 engineering pass

Completed 2026-09-10. **The main PCB is routed, electrically connected and exported for a small engineering-prototype batch. It is not a factory-ready or qualified student product.** No power-module changes, manufacturing order, physical assembly or powered test were performed.

## Deliverables

| Requested work | Result |
|---|---|
| Improve placement | Audio bypass, feedback and stability parts clustered around U3; motor suppression and reservoir moved near J4; receiver, screen, SD and input-rail bypass placement improved. UI positions and outline retained. |
| Review amplifier switching | Q5 changed to TN0702N3-G, Q6 to LP0701N3-G; R36/R38 changed to 1 kohm. Active-high enable and default-off behavior retained. |
| Set routing rules | Explicit 0.25–0.80 mm track classes, 0.20 mm clearance and minimum-width rules. Critical audio paths measured after routing. |
| FreeRouting export | Prepared DSN, routed locally with FreeRouting 2.3.0, imported SES, and exported the finished board back to DSN. No cloud upload. |
| Returned-board checks | Both pours refilled; all connections complete; redundant vias and isolated thermal contacts corrected; independent pad/net and schematic-parity checks passed. |
| BOM and assembly guide | 91 reference positions, 36 grouped PCB purchasing rows, plus 22 kit-material rows covering sockets, modules, mating plugs, wires, optional headers and supports. Frozen for this prototype population, with product-qualification holds identified. |
| Prototype manufacturing files | Seven Gerber layers, separate plated/non-plated drills and maps, drill report, manifest and ZIP generated after fresh clean checks. |

## Open / print / manufacture

- [Main KiCad project](KK_main_module.kicad_pro) · [routed PCB](KK_main_module.kicad_pcb) · [one-sheet schematic PDF](KK_main_module.pdf)
- [Printable complete BOM](assembly/C2_BOM_PRINT.html) · [by-reference BOM](assembly/C2_BOM_BY_REFERENCE.csv) · [additional kit parts](assembly/C2_KIT_EXTRAS.csv)
- [Assembly and bring-up guide](assembly/ASSEMBLY_GUIDE.md) · [datasheet index](assembly/C2_DATASHEETS.md) · [24-document packet plus SD photos](assembly/C2_DATASHEETS.zip)
- [Prototype fabrication ZIP](manufacturing/KK_MAIN_C2_PROTOTYPE_FAB.zip) · [fabrication instructions](manufacturing/README.md) · [source/file checksums](manufacturing/MANIFEST.json)
- [Front fit/assembly PDF](pcb/front-fit-check.pdf) · [mirrored back PDF](pcb/back-fit-check.pdf) · [FreeRouting handoff](routing/README.md)

If an editor tab was open before these external changes, reload the root-level project from disk before saving. The earlier design is preserved in [pre-C.2 backups](pcb/backups/pre_c2_pass/). Earlier shopping lists and the five-sheet project are historical, not current population instructions.

## Verified final state

| Check | Result |
|---|---:|
| Schematic ERC violations | 0 |
| PCB DRC errors/warnings under stored project rules | 0 |
| Unconnected items | 0 |
| Schematic-parity issues | 0 |
| Independent pad/net mismatches | 0 / 267 checked |
| Electrical footprints | 91, all main-board component pads through-hole |
| Routed track segments / vias | 840 / 24 |
| Ground zones | 2, filled; front and back |
| Antenna rule areas | 2, on both copper layers |
| Drill counts | 291 plated holes, including 24 vias; 4 non-plated mounting holes |

Evidence: [fresh ERC](manufacturing/ERC.json), [fresh DRC/parity](manufacturing/DRC.json), [independent checks](pcb/C2_FINAL_VERIFICATION.json), [route measurements](pcb/C2_ROUTE_AUDIT.json), [drill report](manufacturing/DRILL_REPORT.txt). The stored project's pre-existing ignored DRC categories are listed in the manifest; no new violation exclusions were added to hide routing defects. Coordinate roundtrip changes were at most one nanometre per axis, recorded in the independent check, not meaningful component relocation.

Geometry remains 80 x 100 x 1.6 mm, two layers and four 4 mm corner radii. The supplied SuperMini footprint is retained, including its named GPIO/power pads and original 0.04 mm GPIO13 offset. Physical part fit is provisionally accepted from the user's check, not independently certified here. Rear placement and final stack height still warrant a dry fit.

## Placement and actual routing

“Before” is straight pad-to-pad distance on the old board, not an old routed length. “Now” is the measured current copper path; vertical via barrel length and plane shortcuts are excluded. Thus these columns distinguish placement from actual routing rather than implying identical measurements.

| Connection | Before: direct distance | Now: routed length |
|---|---:|---:|
| C25 reservoir to U3 supply | 28.90 mm | 8.66 mm |
| C26 ceramic to U3 supply | 6.19 mm | 4.43 mm |
| C26 ground to U3 ground | 6.69 mm | 4.33 mm |
| C21 negative to U3 feedback pin 5 | 33.32 mm | 5.85 mm |
| C22 to U3 feedback pin 5 | 37.78 mm | 5.12 mm |
| C23 to U3 output 1 | 29.25 mm | 3.05 mm |
| C24 to U3 output 3 | 35.69 mm | 6.41 mm |
| R34 to C23 | 23.36 mm | 2.65 mm |
| R35 to C24 | 16.22 mm | 3.63 mm |
| Motor suppression C16 to J4 supply | 42.11 mm | 5.05 mm |
| Motor reservoir C17 to J4 supply | 45.11 mm | 15.29 mm |
| Receiver reservoir C15 to U2 supply | 57.75 mm | 6.63 mm |

The speaker pair is approximately 10.73/13.26 mm from U3 to J5. The motor return J4-to-Q4 path is 15.58 mm at 0.80 mm width. The amplifier's low-level input and feedback stay in its local cluster; these layout checks do not prove immunity to motor, SPI or PWM coupling. Test those combinations on hardware.

One shared-rail nuance: C9 remains extra bulk capacitance on the wider logic rail, with a long copper path around the DIP. It is **not** counted as U1's effective local reservoir. Instead, the nearby C11 10-uF reservoir is connected directly to U1's VDD by a measured 6.02 mm branch and also serves the adjacent SD connector. C8 provides U1's local ceramic bypass, with about 10.96 mm of supply trace. This is recorded explicitly rather than calling every capacitor local merely because it shares a net name.

The original antenna band at the board edge did not clear copper underneath the antenna end of the module. A second, conservative window at x=59.5–72.5 mm, y=7–15.5 mm now forbids tracks, vias and pours on both layers; affected signals were rerouted. Keep batteries, screens' metalwork and harnesses away from the antenna region when developing the shell. Exact module revision and RF range still need testing.

## Amplifier switch decision

| Reference | Previous | C.2 |
|---|---|---|
| Q5 | KSP2222ABU NPN | TN0702N3-G N-MOSFET |
| Q6 | BC32725BU PNP | LP0701N3-G P-MOSFET |
| R36 | 4.7 kohm | 1 kohm |
| R38 | 100 ohm | 1 kohm |

Q5/Q6 now have source/gate/drain at pins 1/2/3. In particular, Q6 pin 1 is ACT_3V2 and pin 3 is the switched amplifier supply; the schematic and PCB were changed together. Do not install the former BC327 in that position.

The former illustrative switch-drive current was about 23 mA plus 0.55 mA into Q5's base. The revised enabled-state control current is approximately `3.3/101k + 3.2/101k = 64.4 microamps`. This is a calculated control-current reduction, not measured whole-toy battery life; U3 still consumes its own enabled quiescent/output current.

R37 pulls Q5's gate low at reset and R39 holds Q6 off. With AMP_EN high, Q5 pulls Q6's gate down through R38. The [TN0702 data](https://www.microchip.com/content/dam/mchp/documents/APID/ProductDocuments/DataSheets/TN0702-N-Channel-Enhancement-Mode-Vertical-DMOS-FET-Data-Sheet-20005941A.pdf) include low-voltage gate-drive conditions; here Q5 only sinks approximately 32 microamps. Even a conservative 2.5 V logic-high estimate leaves about 2.48 V at Q5's gate through the resistor divider.

The [LP0701 data](https://ww1.microchip.com/downloads/en/DeviceDoc/LP0701-P-Channel-Enhancement-Mode-Lateral-MOSFET-Data-Sheet-20005447A.pdf) specify a 2-ohm maximum at VGS=-3 V, ID=-150 mA and 25°C. At that test point the drop/loss are 0.30 V / 45 mW. The nominal gate divider provides approximately -3.17 V; source tolerance and trace drop retain a little margin above 3 V in magnitude under the stated prototype load assumptions. These are conditional checks, not hot/cold or inrush guarantees. C25's charging transient, turn-on/off pops, U3 supply headroom and temperature require measurements. There is no dedicated inrush controller in this revision.

The [UTC TDA2822 bridge application](https://www.unisonic.com.tw/uploadfiles/836/part_no_pdf/TDA2822.pdf) remains the topology basis: U3 outputs 1 and 3 drive the speaker differentially; C21/C22 are feedback components and C23/R34 plus C24/R35 are output stability branches. Neither speaker terminal goes to ground. Start with reduced firmware amplitude and test carrier rejection, clipping, noise, differential DC and speaker heating before releasing a volume limit.

## Routing and power review

| Class | Track width | Purpose |
|---|---:|---|
| Default | 0.25 mm | Digital/control and SPI |
| Audio | 0.30 mm | Filter/input/feedback/stability branches |
| AuxLoad | 0.50 mm | IR LED and switched backlight paths |
| Speaker | 0.50 mm | Both bridged speaker outputs |
| Ground | 0.60 mm | Explicit ground tracks, supplemented by both pours |
| Power / Motor | 0.80 mm | Incoming rails, amplifier supply and motor return |

Minimum copper clearance is 0.20 mm. Net-specific minimum track widths are enforced by project custom rules and independently checked on the final copper. Actual drill sizes, including 0.30/0.40/0.50 mm vias, are listed in the drill report. Nominal copper is 35 micrometres on each side.

As a trace-only sanity check using copper resistivity about 1.72e-8 ohm-metres at room temperature: the 35.92 mm / 0.80 mm MCU supply path is about 0.022 ohm, or 13 mV at 0.6 A; the longest measured 132.46 mm logic supply path is about 0.081 ohm, or 41 mV if the entire reserved 0.5 A flowed through it. These estimates omit connector/contact, return-path and source drops and are not temperature-rise qualification. The motor's supply and switched return copper together contribute only a few millivolts at a 120 mA starting-current example; Q4 and the source dominate its voltage margin. Measure at the actual loads during simultaneous activity.

Most ground pads retain thermal connections for hand soldering. SW1 pad D and U3 pin 4 use their explicit ground tracks instead of useless isolated thermal contacts; their full electrical connectivity was checked after refill. No DRC severity was relaxed for this. Two unnecessary one-layer-only vias were removed, then connectivity and clearances rechecked. Copper/placement views were visually inspected after final routing; plated/non-plated drill counts and the rounded outline were checked against the fabrication outputs.

## Remaining qualification — before a student/product release

1. **Power source:** develop and qualify the separate module against J1's 5 V / GND / 3.3 V / 3.2 V interface, current capacity, coordinated sequencing, protection and USB backfeed behavior. The old power output and a raw battery are not compatible substitutes. Do not attach USB and SYS_IN together.
2. **Speaker and audio:** obtain the exact FS1511P08-H3.0 continuous-power rating or select a documented substitute. Verify MOSFET inrush, audio headroom, noise, pops, differential DC, clipping and hot/cold behavior with the actual speaker.
3. **Actual modules and firmware:** verify delivered SuperMini memory/pinout, display BLK circuitry, SD SPI operation and card write/power-loss recovery. The selected card is Transcend TS32GUSD300S, 32 GB; game loading, uploads and recovery firmware are not implemented by this PCB pass.
4. **Motor and IR:** test startup/current, suppression and interference during Wi-Fi/SD/audio activity; validate the IR carrier/protocol and range.
5. **Mechanical/product checks:** dry-fit the revised rear placement and stack; support the screen, retain the modules and actuators, label the interchangeable motor/speaker plugs, and validate shell/battery placement, RF performance, drop/handling and applicable product compliance.

The immediate next step is an adult-supervised engineering prototype and the documented bring-up checklist—not distribution of untested kits. The manufacturing ZIP is a bare-board prototype deliverable, not certification that the assembled toy will work when plugged into an arbitrary supply.

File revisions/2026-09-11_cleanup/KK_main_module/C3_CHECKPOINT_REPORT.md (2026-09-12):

> Historical checkpoint, superseded by the approved 80 × 115 mm [C.3 RGB prototype report](C3_PROTOTYPE_REPORT.md). The pending size decision below is resolved; do not use this report as current build status.

# C.3 — debug pads, assembly markings and connector access

Status: checked engineering-prototype checkpoint, **not a fabrication release**. RGB layout is awaiting the user's board-size choice. No power-board changes or fabrication orders were made.

## Applied to the root project

- 25 bare plated test points, 2.0 mm copper / 0.8 mm drill. Three are GND points. They cover power, controls, display/SD buses, audio filter/PWM, motor return and IR. See the [map and measurement precautions](assembly/C3_DEBUG_GUIDE.md).
- 25 short tap tracks, longest 3.44 mm; all 840 existing track segments and 24 vias retained. The board now has 865 segments, 24 vias, 316 plated holes including vias, and four mounting holes.
- Added silkscreen TP identifiers, pin-1 marks at ICs/connectors/transistors, cathode marks, IR TX/RX identification, USB-end identification and connector pinout legends. Existing capacitor +/hatched-negative marks, diode bands, transistor flats, IC notches and component reference labels remain. The supplied MCU footprint is unchanged.
- J1 is the four-pin regulated-power input: 1=5 V, 2=GND, 3=3.3 V, 4=3.2 V. It was already top-entry, not a side-entry battery connector.
- J4 is the motor and J5 the bridge speaker. Both now use **B2B-PH-K-S(LF)(SN)** top-entry through-hole connectors, replacing inward-facing S2B parts. Existing PHR-2 plugs and crimp terminals still apply. J5 moved 0.25 mm left to clear C24; all other original components retain their positions.

## Checks and remaining physical limits

Fresh KiCad ERC: 0 violations. DRC: 0 unresolved violations, 0 unconnected items. Schematic parity: 0 issues. Native verification confirms the original copper was retained and the added pads are on their specified nets. Reports are in `pcb/c3_final_*.json` and `pcb/C3_FINAL_VERIFICATION.json`.

The [updated rear 3D view](pcb/c3-back-3d.png) was inspected for the connector direction and visible assembly labels. It shows connector bodies, not the complete mating plugs, wire harness or final shell.

A scoped courtyard rule permits **unpopulated TP holes only** under an opposite-face component body. This does not disable electrical, hole, mask or board-edge checks. Do not fit test posts/wire loops through those holes. The map specifies the accessible probe face; modules may need to be removed for front-side access. Debug pads do not isolate a bad net automatically: trace cuts may still be required for a repair.

The top-entry PH connector's nominal mated height is about 8 mm above its mounting face, per the [JST drawing](https://www.jst-mfg.com/product/pdf/eng/ePH.pdf). Allow additional rear clearance for wires, gentle bends, fingers/tools and strain relief. J1 also needs rear insertion access. Board courtyards pass, but no final shell or mating harness has been physically tested. Do not claim a verified enclosure fit from the connector-only 3D model.

J4/J5 plugs are physically interchangeable: label their harnesses MOTOR and SPEAKER. Speaker minus is **not ground**. Existing power sequencing/backfeed, speaker rating, motor startup, display backlight, thermal, RF and firmware qualification requirements still apply.

## RGB proposal — approved feature, pending layout decision

D1 is the TSAL6200 940 nm infrared transmitter and remains unchanged. A separate diffused RGB lamp is proposed:

| Ref | Proposed part | Function |
|---|---|---|
| D3 | Kingbright WP154A4SEJ3VBDZGW/CA | 5 mm diffused RGB, common anode; 1=red cathode, 2=common anode, 3=blue cathode, 4=green cathode |
| U4 | TI TLC5916IN, PDIP-16 | Socketed constant-current driver; 3.3 V logic, LED anode on 5 V |
| R40 | MFR-25FBF52-1K8, 1.8 kΩ | About 10.4 mA/channel default current; low-current mode can reduce brightness |
| R41 | MFR-25FBF52-10K, 10 kΩ | Output-disable pull-up |
| C27 | C315C104K5R5TA, 100 nF | Local driver bypass |
| Additional | 16-pin narrow DIP socket, exact purchase selection pending | Student-friendly replacement/service |

The proposed schematic passes ERC. The new components are **not** installed in the root PCB or included in its checkpoint BOM. The attempted 80 × 100 mm RGB placement was rejected and remains explicitly unrouted/unqualified in `routing/`.

Pending question: permit a **15 mm bottom extension (80 × 115 mm)** for an uncluttered through-hole RGB assembly area, or retain 80 × 100 mm and defer RGB? The extension has not been applied. Exact placement/routing and the socket purchasing selection follow that decision.

The RGB driver uses spare MCP23017 GPA4=DATA, GPA5=CLK, GPA6=LATCH, GPA7=OE_N; it does not consume an ESP32 strapping pin. Firmware must blank outputs, initialize the shift register/latch and select brightness before enabling. Basic RGB combinations and global brightness control are supported; smooth independent-channel fades are not automatically provided by this hardware. The proposed RGB footprint requires supervised lead forming from the LED's 1.27 mm pitch to the 2.54 mm assembly jig pitch; sample fit remains to be tested.

Primary documentation: [RGB LED drawing](https://www.kingbrightusa.com/images/catalog/SPEC/WP154A4SEJ3VBDZGW-CA.pdf), [TI driver datasheet](https://www.ti.com/lit/ds/symlink/tlc5916.pdf). Both were downloaded to `component_review/datasheets/`.

## Handoff

Use the root project for the checked debug/connector board and the C.3 checkpoint BOM for its component selections. Manufacturing is held until the RGB size decision, final layout and repeat checks. The old C.2 fabrication package is archived, not current. Reload KiCad from disk before editing to avoid overwriting changes from a stale IDE tab.

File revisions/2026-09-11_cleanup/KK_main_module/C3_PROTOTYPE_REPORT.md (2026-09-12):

# C.3 RGB main-board completion report

Date: 2026-09-11. Status: **CAD-complete engineering prototype; not powered or factory-qualified.** No PCB order was placed. The separate power-module files were not changed by this main-board pass.

## Completed

- Approved outline applied: 80 × 115 × 1.6 mm, two layers, 4 mm corner radii. Bottom mounting holes moved 15 mm down; existing controls and electrical component locations retained.
- Separate front RGB LED D3 added. D1 remains the IR transmitter. TLC5916IN socketed through-hole driver uses four spare MCP23017 outputs; no additional ESP32 pin or strapping-pin use. Exact ED16DT socket and Kingbright WP154A4SEJ3VBDZGW/CA selected with datasheets. Four resistors and bypass capacitor complete the seven-component addition.
- RGB OE pull-up keeps outputs blanked at reset; SDI/CLK pull-downs define startup inputs. R_EXT=1.8 kΩ gives approximately 10.4 mA nominal default channel current. RGB lead order and required lead forming are marked/documented. Driver supply capacitor connection is approximately 4.15 mm.
- 25 bare plated debug holes, orientation/connector markings, top-entry J1/J4/J5, prior amplifier switching improvements and motor suppression placement retained. J4/J5 use B2B-PH-K-S(LF)(SN); mating PHR-2 housings unchanged.
- Original routed copper retained exactly; 15 local RGB branches added with 0.8 mm power and 0.25 mm control/LED traces. Both GND pours refilled, both antenna keepouts retained. Final board has 1,356 track segments and 40 vias, 362 plated drill hits including vias and 4 NPTH mounting holes.
- Single grouped schematic, actual-size front/back fit sheets, 3D previews, 98-reference BOM, sockets/harness extras, 26-document datasheet packet, debug instructions, RGB initialization and bench-test record updated.
- Fresh FreeRouting DSN and locally generated prototype Gerber/drill ZIP prepared. No external autorouting upload was used.

## Verification evidence

| Check | Result |
|---|---|
| Schematic ERC | 0 violations |
| PCB DRC | 0 violations |
| Unconnected items | 0 |
| Schematic/PCB parity | 0 issues |
| Independent population, values, MPNs, footprint IDs and pad/net comparison | Pass: all 98 electrical positions |
| Student-soldered PCB pads | All electrical component pads through-hole |
| Prior copper and electrical placement preservation | Pass; only bottom mounting holes moved |
| Ground pours / antenna rule areas | 2 filled pours / 2 retained keepouts |

The [independent verification JSON](pcb/C3_FINAL_VERIFICATION.json) and [manufacturing manifest](manufacturing/MANIFEST.json) identify the exact board hash. Export reruns ERC/DRC/parity and refuses mismatched audit hashes. A documented, scoped courtyard exception treats **bare TP holes** as having no fitted component body. It does not waive copper, drill or edge clearances; all other relevant placement checks remain active.

The zero-violation result is under the recorded project settings, not a claim that every optional KiCad check is enabled. Five inherited categories remain ignored: missing courtyard, track endpoint not centered on via, tuning-profile geometry, symbol footprint-filter mismatch and footprint-type mismatch. They are listed in the DRC JSON/manifest. This pass did not newly disable those categories; the independent audit separately verifies the electrical pad type and exact assigned footprint IDs. Physical fit is still a bench requirement.

## Physical and electrical limits — still pending

CAD courtyard checks and visual review do not establish real assembly fit. The actual SuperMini, display and SD modules, formed RGB leads, rear socket/electrolytic heights, JST plugs and wire bends need dry-fit. D3's native 1.27 mm leads must be formed to 2.54 mm without stressing its body. There is no qualified D3 formed-lead 3D model. The prior user fit check is provisional, not a new measured assembly test. Top-entry PH plugs need about 8 mm mated height plus wire bending/insertion room; 15 mm bench standoffs are not a final enclosure guarantee.

The board needs coordinated **5 V, 3.3 V and 3.2 V** regulated inputs at J1. It is not safe to connect raw battery or assume the existing power module matches. Do not apply module USB and SYS_IN simultaneously. Reserve additional RGB current in the future power-module budget and verify rail sequencing, transients, backfeed and fault protection. No upstream charger/regulator change was made.

Speaker FS1511P08-H3.0 continuous-power rating remains undocumented. Audio switch/inrush, speaker clipping/DC/pops, backlight current, motor startup, simultaneous Wi-Fi/SD/RGB loading, thermal behavior and RF performance must be measured. Clean DRC is not circuit simulation or proof of operation. Exact module revisions and delivered memory also require verification.

No full application, browser upload, trading, game loader or bench firmware was implemented by this hardware pass. RGB safe-state and control requirements are in the assembly guide. Firmware and physical prototype tests remain separate work; every entry in the [bench record](assembly/C3_BENCH_TEST_RECORD.csv) is honestly marked pending.

## Handoff

Use the root KiCad project, [C.3 BOM](assembly/C3_BOM_PRINT.html), [assembly guide](assembly/ASSEMBLY_GUIDE.md) and [C.3 fabrication ZIP](manufacturing/KK_MAIN_C3_PROTOTYPE_FAB.zip). Reload stale KiCad tabs before saving. Old checkpoint reports and routing candidates are history. Next: dry-fit the exact new parts, assemble a supervised engineering prototype, test with the specified bench supply interface, then develop/qualify the separate power module and firmware before any student-product release.

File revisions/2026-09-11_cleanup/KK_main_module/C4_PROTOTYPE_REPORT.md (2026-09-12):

# C.4 — relocated, socketed RGB and populated 3D viewer

**Historical revision, superseded by [C.5](C5_relayout/REPORT.md).** C.4 native sources are preserved under `pcb/backups/pre_c5_relayout/` and its fabrication outputs under `archive/C4_manufacturing_superseded/manufacturing/`. Root project and manufacturing paths now refer to C.5.

The RGB LED D3 is on the right, just below the ESP32, as approved. Center: **69, 37.75 mm** from the board's top-left coordinate origin; its four-pin row is vertical, pin 1 at the lower end. Board size remains 80 × 115 mm. The ESP32 antenna keep-outs, all other component locations, mounting holes and top-entry JST connectors are unchanged. D1 remains infrared.

## Changes

- D3 gets a PPTC041LFBN-RC removable four-pin socket, 1.05 mm PCB drills and clear pin-order markings. The 2.54 mm formed LED pitch remains. Actual LED-to-socket contact fit and retention must be tested; this is not a qualified production interface yet.
- All 98 electrical positions now have visible 3D models. New models include the RGB/socket, soft buttons, ceramic capacitors, IR receiver, plug-in modules and their socket/header stacks. DIP chips now appear seated in their sockets. Electrolytic models use the selected 11 mm body height.
- Four LED branches rerouted. Five interfering segments on the motor supply/return and backlight-control nets were replaced by three local detours. Unrelated routed copper is retained. Three incomplete ground thermals at SW7:C, SW9:D and C4:2 were replaced by explicit 0.6 mm ground connections; their direct pour connection is disabled locally, not their electrical ground connection.
- Two GND pours refilled. Circuit pin/net mapping is unchanged. Main-board assembly remains through-hole; replaceable MCU, display, SD reader, DIP chips and RGB are socketed. Passives/small transistors stay soldered; speaker/motor unplug at JST connectors.
- Schematic footprint assignment, C.4 BOM with the added socket, assembly guide, fit sheets, 3D previews and STEP assembly updated. Older C.3 fabrication ZIP is archived; use only the C.4 prototype package for this board.

## Checks and limits

Fresh ERC, DRC, unconnected-item and schematic-parity reports are in `pcb/c4_final_*.json` and the fabrication package. [Independent verification](pcb/C4_FINAL_VERIFICATION.json) checks unchanged pin/net mapping, retained unrelated routes/placements, footprint IDs, through-hole pads and visible/resolvable models for every electrical position. The [manufacturing manifest](manufacturing/MANIFEST.json) records the source snapshot and export hashes.

The existing bare-TP courtyard rule and five inherited ignored DRC categories are unchanged and disclosed in the manifest. D3 introduces no new clearance-rule waiver: its courtyard is the board-level socket housing; the elevated LED envelope is reviewed separately in 3D.

The 3D assemblies are dimensioned nominal models, not proof of physical fit. [Model provenance and limitations](3dmodels/README.md) distinguishes manufacturer package dimensions from provisional seller-module envelopes. RGB height is approximately 22.1 mm above the PCB in the proposed stack. Actual LED socket retention, all module/header heights, wire bends, lens orientation and mechanical support need a physical sample check before shell design or a kit-production batch. Speaker/motor/cable/battery locations are not invented in the model.

Power-module development, firmware, speaker rating and all powered/thermal/RF testing remain pending. No power-board file was changed and no order was placed. This remains an engineering prototype, not a factory-qualified student product. J1 still requires coordinated regulated 5 V, 3.3 V and 3.2 V rails; never connect raw battery or USB and SYS_IN together.

Open the root KiCad project after closing/reloading stale editor tabs. [Front 3D](pcb/c4-front-3d.png) · [Rear 3D](pcb/c4-back-3d.png) · [Angled view](pcb/c4-iso-3d.png) · [STEP assembly](pcb/KK_main_module_C4_assembly.step) · [Printable BOM](assembly/C4_BOM_PRINT.html).

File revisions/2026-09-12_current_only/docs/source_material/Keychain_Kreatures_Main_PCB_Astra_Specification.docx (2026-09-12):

KEYCHAIN KREATURES

Main PCB Engineering & Astra Reconstruction Specification

This document explains the purpose, components, interfaces, candidate wiring and engineering requirements for every major element of the Keychain Kreatures main PCB.

Astra must verify datasheets, calculate missing values, detect mistakes and improve preliminary choices before freezing the schematic or PCB.

# 1. System Architecture

The Keychain Kreatures main PCB is one of four separate physical assemblies. The ST7789 display, RODDY Power Module, and 1S LiPo battery remain separate. The main board must not duplicate USB-C charging, MCP73871 power-path management, DW01A/FS8205 protection, the battery connector, or the display panel itself.

# 2. Product Goal

Build a compact modern virtual-pet/keychain handheld with color graphics, six physical controls, IR communication, real speaker audio, vibration, BLE/Wi-Fi capability and approximately one week of realistic battery life. It should feel premium while remaining understandable, repairable and suitable for a bags-of-parts DIY kit.

# 3. Through-Hole Philosophy

Use THT wherever a technically sensible part exists: PDIP ICs, TO-92 transistors, axial resistors, radial capacitors, THT switches/LEDs/IR parts/headers, and wire-lead speaker/motor. Do not use breakout modules for audio, GPIO, IR or haptics. SMD is acceptable only where modern performance makes it unavoidable, principally ESP32-C3/RF and potentially the efficient regulator. Astra should consider factory-populating only unavoidable fine-pitch SMD parts.

# 4. Physical Interfaces

Assembly/interface | Required connection | Explanation
RODDY Power | SYS_OUT, GND | Managed but unregulated input power; main PCB creates regulated rails
RODDY status | PG, STAT1/LBO, STAT2, GND, VBAT | Optional charging/power/battery monitoring
ST7789 display | 3V3, GND, SCLK, MOSI, CS, DC, RESET, BACKLIGHT candidate | Separate 240×280 TFT; verify exact module pinout
Speaker | 2-wire connector/pads | Separate 8 Ω miniature dynamic speaker
Vibration motor | 2-wire connector/pads | Separate 3 V miniature motor

# 5. Functional Blocks

Block | Candidate hardware | Purpose
Controller | ESP32-C3, ≥4 MB flash | Firmware, wireless, timing, peripheral control
Power regulation | Low-IQ efficient regulator | RODDY SYS_OUT to stable 3.3 V
GPIO expansion | MCP23008-E/P PDIP-18 | Extra low-speed GPIO and interrupt wake
Controls | 6 × 6 mm THT tact switches ×6 | UP/DOWN/LEFT/RIGHT/A/B candidate
Display interface | Header + backlight driver | Connect/control separate ST7789
IR transmit | TSAL6200 + KSP2222ABU candidate | 38 kHz modulated IR
IR receive | TSOP38238 + filtering | 38 kHz demodulated IR
Audio | NJM2073D candidate + 8 Ω speaker | Real speaker audio
Haptics | 3 V motor + transistor + 1N5819 | Vibration
Service | 1×6 header + test points | Programming/recovery/repair

# 6. Power Regulation

SYS_OUT from RODDY is not fixed 3.3 V. Astra must derive its real range from the MCP73871 power-path design and choose the correct regulator topology, evaluating buck-boost operation.

- Very low quiescent current and strong light-load efficiency.
- Enough transient current for ESP32 RF bursts and active peripherals.
- Correct regulator capacitors/layout from its datasheet.
- Consider separate switched/raw rails for motor/audio if beneficial.
- Do not force a THT regulator if it compromises runtime or correctness.

RODDY SYS_OUT → efficient regulator → 3V3

# 7. Power Budget

A 1000 mAh battery over 168 hours permits only about 5.95 mA average. The architecture must be sleep-first.

1000 mAh / 168 h ≈ 5.95 mA average

- TFT and backlight fully off in sleep.
- Audio inactive or power-gated.
- Motor and IR TX off.
- IR RX disabled when unnecessary.
- ESP32 uses appropriate sleep.
- GPIO expander configured for low-power interrupt wake.

Astra must estimate active, idle and sleep currents and identify anything that prevents the one-week target.

# 8. ESP32-C3 Controller

Target ESP32-C3 family, minimum 4 MB flash. The earlier Super Mini was a prototype convenience; final design should preferably integrate the controller.

- Select exact variant and verify flash/clock requirements.
- Design EN/reset, boot straps, decoupling and programming/recovery.
- Implement antenna and RF keepout correctly.
- Respect boot-strapping/programming restrictions.
- Produce a complete GPIO assignment.
- If direct DIY assembly is unrealistic, factory-populate only the unavoidable SMD/RF section instead of using a whole dev module.

# 9. MCP23008 GPIO Expander

MCP23008-E/P, PDIP-18
VDD → 3V3
VSS → GND
SDA → ESP32 SDA
SCL → ESP32 SCL
SDA → ~4.7 kΩ → 3V3
SCL → ~4.7 kΩ → 3V3
100 nF local decoupling

Verify pull-ups, explicitly strap address pins, and preferably connect INT to a wake-capable ESP32 pin.

# 10. GPIO Allocation

Astra must document every ESP32-C3 and MCP23008 GPIO. Account for TFT SPI/CS/DC/reset/backlight, I²C, expander interrupt, six buttons, IR TX/RX, audio, vibration, RODDY status, battery ADC and programming/boot. Avoid boot-strap and wake conflicts.

# 11. Controls

Use six 6×6 mm momentary THT tact switches. Candidate layout: UP, DOWN, LEFT, RIGHT, A, B. Prefer MCP23008 for these low-speed inputs. Use suitable pull-ups; never leave inputs floating. Optimize for interrupt-driven wake and low sleep current.

# 12. ST7789 Display Interface

Separate ST7789 240×280 TFT
Candidate signals:
3V3, GND, SCLK, MOSI, CS, DC, RESET, BACKLIGHT

Verify the exact display assembly pinout. Provide local 100 nF and approximately 10 µF bulk decoupling if supported by its datasheet. Backlight must be transistor/MOSFET controlled, completely off during sleep, and optionally PWM dimmable.

# 13. IR Transmitter

TSAL6200 940 nm THT emitter
KSP2222ABU TO-92 candidate
MCU IR_TX → calculated base resistor → transistor → emitter/current-limit network

Do not drive the emitter directly from GPIO. Calculate resistor values from 3.3 V, LED forward voltage, desired pulse current, transistor saturation and duty cycle. Support a 38 kHz carrier. Old 47 Ω/100 Ω/1 kΩ/10 kΩ inventory values are candidates only.

# 14. IR Receiver

TSOP38238 THT
VCC → filtered supply
GND → GND
OUT → MCU/GPIO

Preliminary filter: 100 Ω series supply resistor plus 4.7 µF and 100 nF locally. Verify/correct from Vishay datasheet. Place at IR window and away from regulator, motor and audio noise.

# 15. Haptics

3 V vibration motor
KSP2222ABU candidate
1N5819 flyback diode
motor supply → motor → transistor collector
transistor emitter → GND
GPIO → ~1 kΩ candidate → base
optional ~10 kΩ base-emitter pull-down

Verify motor startup/stall current, transistor capability and regulator loading. Choose a better THT transistor/MOSFET if needed and add local bulk capacitance.

# 16. Audio

Goal: decent real speaker sound, not merely a piezo. Candidate amplifier is NJM2073D DIP-8 driving a separate 8 Ω miniature dynamic speaker.

Astra must design the amplifier from its exact datasheet at the final rail: input filtering/coupling, bias, gain, output coupling if needed, local decoupling and bulk capacitance. If NJM2073D is poor at the final voltage, select a better readily available THT low-voltage amplifier and explain why. Sleep current must be negligible through low idle current or power gating.

# 17. Battery Measurement and RODDY Status

VBAT is approximately 3.0–4.2 V. Design a safe high-value or switched divider for the ESP32 ADC; never feed raw 4.2 V directly. Minimize divider standby current and calculate measurement error.

PG, STAT1/LBO and STAT2 may support charging/plugged-in UI. Verify MCP73871 electrical characteristics and add suitable pull-ups/interface; do not assume push-pull 3.3 V logic.

# 18. Programming, Recovery and Test

Candidate 1×6 2.54 mm THT service header:
3V3
GND
TX
RX
EN
BOOT

Final pinout must match the chosen ESP32 implementation and be labeled on silkscreen. Provide test access for SYS_IN, 3V3 and GND, plus SDA/SCL/IR/AUDIO/VBAT_SENSE where space permits.

# 19. Decoupling

Every IC receives local 100 nF ceramic decoupling physically adjacent to its supply pins. Add bulk capacitance around regulator, ESP32, display, audio and motor based on transient needs. Available THT families include 100 nF radial ceramic and 4.7/10/100/220 µF radial electrolytics.

# 20. Candidate Component Baseline

Part | Package/form | Purpose
MCP23008-E/P | PDIP-18 THT | GPIO expansion
KSP2222ABU | TO-92 THT | IR/motor/backlight driver candidate
2N2907A | TO-92 THT | Available PNP candidate
TSAL6200 | 5 mm THT | IR emitter
TSOP38238 | 3-lead THT | IR receiver
NJM2073D | DIP-8 THT | Audio amp candidate
1N5819 | DO-41 THT | Flyback diode
6×6 mm tact switch | THT ×6 | Controls
8 Ω speaker | Wire leads | Audio
3 V vibration motor | Wire leads | Haptics
3 mm LED | THT | Optional status
Resistor inventory | 47 Ω, 100 Ω, 1 kΩ, 4.7 kΩ, 5.1 kΩ, 10 kΩ | Candidate inventory; add correct standard values as needed
Capacitor inventory | 100 nF, 4.7 µF, 10 µF, 100 µF, 220 µF | Candidate inventory; use where justified

# 21. PCB Layout Requirements

- Exact outline must follow final enclosure, display window, button geometry, speaker, IR window and cable/battery packaging.
- Keep buttons mechanically aligned.
- Place TSAL6200/TSOP38238 at IR window.
- Keep regulator switch node away from IR/audio/RF.
- Respect ESP32 antenna keepout.
- Use clear functional silkscreen, polarity and connector labels.
- Keep THT pads accessible for hand soldering and repair.
- Prefer a 2-layer design with a mostly solid ground plane if practical.
- Use wider power/motor/speaker traces than logic traces.
- Keep high-current loops short and decoupling at device pins.

# 22. Astra Engineering Authority

Astra is required to correct mistakes rather than blindly reproduce this brief.

- Verify every exact part against manufacturer datasheets.
- Calculate all missing resistor/capacitor values.
- Check transistor current and dissipation.
- Check ESP32 strap/wake/programming compatibility.
- Check regulator transient/thermal performance.
- Check audio operation at actual supply.
- Check IR current/filtering.
- Check ADC limits and divider current.
- Check sleep-current budget.
- Run ERC and DRC with no unexplained violations.
- Explain any tradeoff where requirements conflict.

# 23. Required Astra Deliverables

Deliverable | Required output
Architecture review | Confirm/correct functional architecture
Exact BOM | Manufacturer, MPN, value, package, quantity, sourcing notes
Schematic | Complete verified main-board schematic
GPIO table | Every ESP32/MCP23008 pin and function
Power budget | Active, idle, sleep and projected runtime
Interface tables | RODDY and ST7789 pinouts
PCB | Placed/routed board after mechanical constraints are known
ERC/DRC | No unexplained errors
Change log | Every preliminary choice Astra changed and why
Manufacturing notes | Identify factory-populated unavoidable SMD versus user-soldered THT

# 24. Final Instruction to Astra

Treat the product goal as authoritative and the preliminary circuitry as a starting point. Do not invent missing electrical details, do not silently preserve errors, and do not replace the DIY/THT philosophy with breakout modules. Before PCB layout, present the corrected schematic architecture, exact parts, calculated values, GPIO map, interfaces and power budget for review.

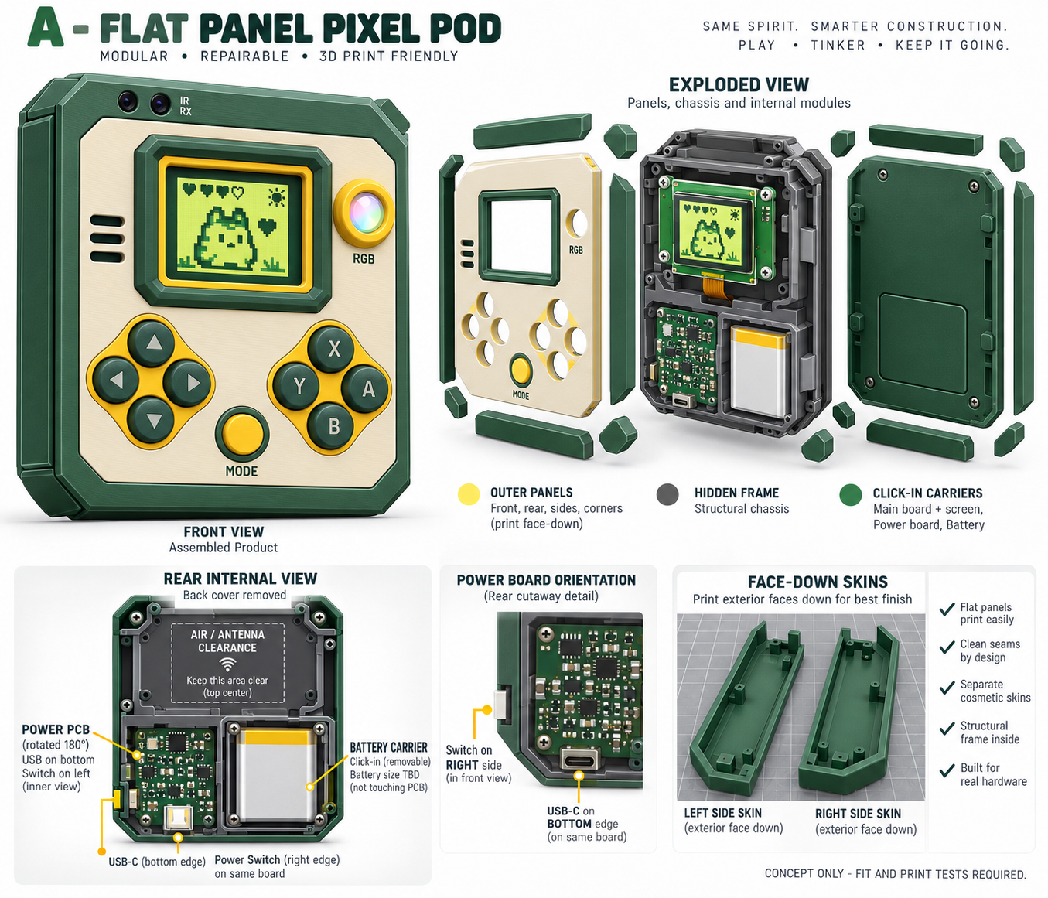
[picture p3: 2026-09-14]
docs/enclosure_concepts/pixel_pod_round2/04_pixel_pod_flat_panels.png

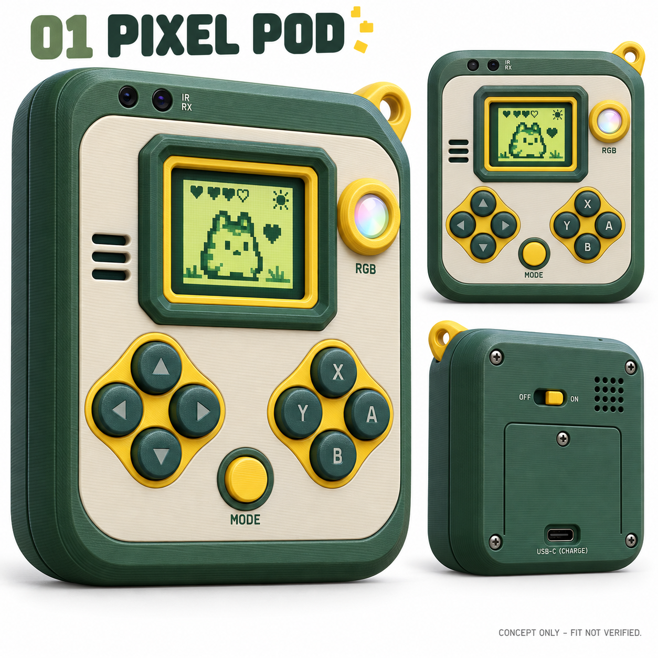
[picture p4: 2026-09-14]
docs/enclosure_concepts/01_pixel_pod.png

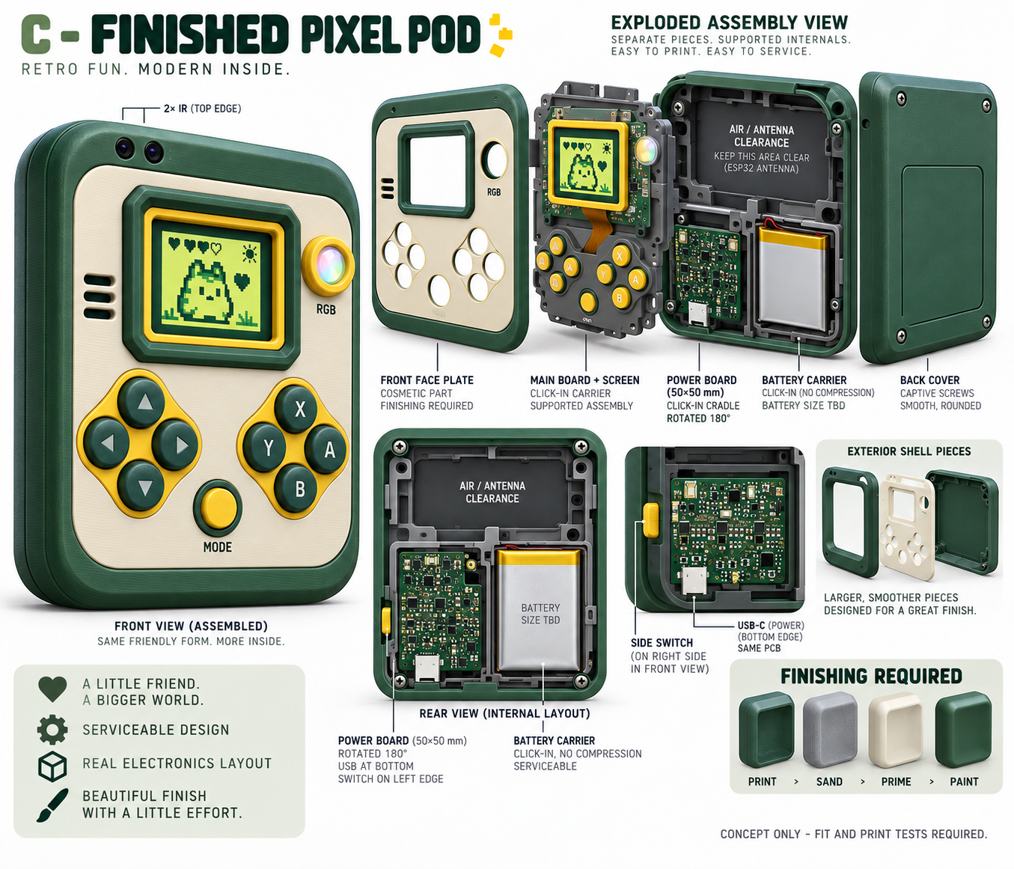
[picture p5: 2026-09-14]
docs/enclosure_concepts/pixel_pod_round2/06_pixel_pod_finished_shell.png

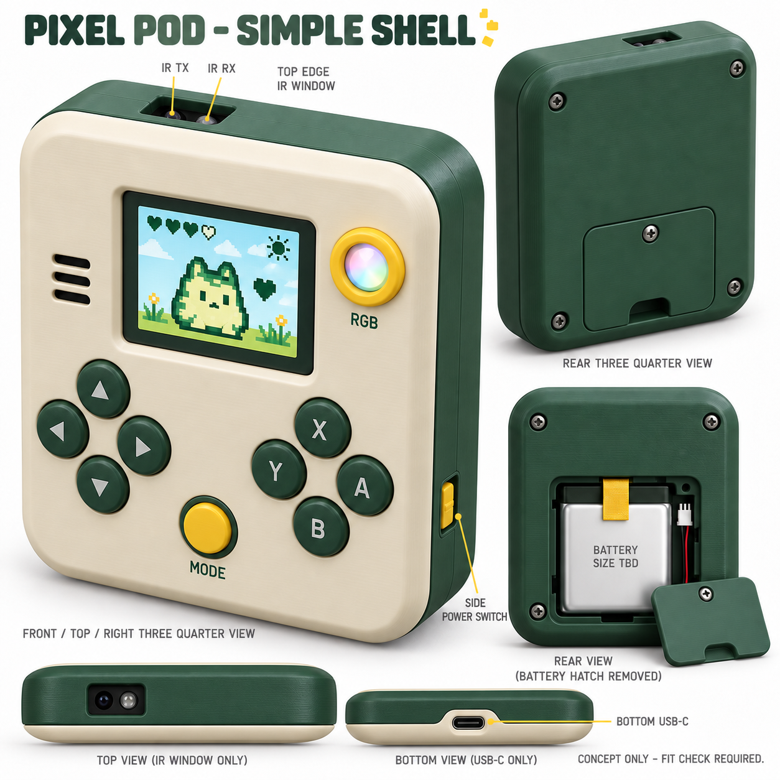
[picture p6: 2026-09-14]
docs/enclosure_concepts/pixel_pod_round3/07_pixel_pod_simple_exterior.png

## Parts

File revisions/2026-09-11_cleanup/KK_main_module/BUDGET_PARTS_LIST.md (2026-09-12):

# Budget parts list — 2026-09-10

Latest user direction: retain the Amazon screens, remove the Mouser-only sourcing preference, replace the expensive speaker with a smaller cheaper compromise, and prioritize premium assembled feel at low cost. This list supersedes earlier supplier/part preferences. It is a purchasing brief and engineering budget, not a released exact BOM.

## Assembly and sourcing

All student PCB soldering remains through-hole. ESP32 and regulator are preassembled pin-header modules; display, speaker and motor arrive ready to connect. Require factory-attached speaker/motor wires, not student soldering to miniature pads. Purchase semiconductors from traceable sources where possible; generic mechanical parts must come from a consistent sampled supplier. No purchases or supplier contacts made.

## Per-device component budget

USD targets for approximately 10–25 kits using multipacks/direct sourcing, **not verified quotes** unless explicitly identified. Shipping, tax, tariffs, minimum-order surplus, spares, assembly, packaging, tooling, battery, separate power module and shell are excluded. Lower bounds are procurement goals, not confirmed availability.

| Qty | Block / purchase specification | Budget per device |
|---|---|---:|
| 1 | Existing XIITIA Amazon B0DFWL25RB display, 1.69-inch ST7789V2 240 × 280, pin-header breakout | $7.50, user's two-for-$15 price |
| 1 | Compact ESP32-S3 module with THT pins; preferred 16 MB flash / 8 MB PSRAM, exact module still open | $7–10 |
| 1 | Fixed 3.3 V buck-boost regulator module with THT pins, suitable input range and low idle current | $5–10 |
| 1 | Wired 1511-format speaker, approximately 15 × 11 mm, 8 ohm, 0.5 W nominal | $0.50–1.00 |
| 1 set | UTC TDA2822L-D08-T DIP-8 audio candidate, socket, filtering/bias/coupling and switched-power support | $0.60–1.20 |
| 1 | Wired 3 V coin ERM motor, approximately 8–10 mm diameter; no breakout | $0.40–0.80 |
| 9 | Consistent low-force 6 × 6 mm THT tactile switches; D-pad + A/B/X/Y + Function | $0.90–1.80 total |
| 1 | PDIP GPIO expander and socket; MCP23008-E/P candidate, omit only if exact GPIO plan permits | $0.50–1.50 |
| 1 each | TSAL6200 IR emitter and TSOP38238 38 kHz receiver, genuine THT parts preferred | $0.80–1.60 total |
| 1 set | Remaining THT drivers, flyback/supply diodes, resistors, capacitors, battery/status conditioning and USB isolation allowance | $1–2 |
| 1 set | MCU sockets, keyed THT peripheral connectors, mating leads and service header | $1.20–2.50 |
| 1 | Small two-layer main PCB, allocated across batch; final board/vendor quote pending | $1–2 |
| 1 set | Speaker gasket, motor retention, spacers and screws; shell/caps excluded | $0.50–1.00 |
| | **Main assembly, screen and peripherals subtotal** | **$26.90–42.90** |
| | **Same subtotal excluding screen** | **$19.40–35.40** |

Rounded working budget: $27–43 before the exclusions above. Target the low end through consistent batch sourcing, not removal of necessary power/interface circuitry. Support-part allowances may rise after circuit design. No second radio, extra charging board, microSD hardware or decorative LED array is added. The retained Amazon display does not provide the DFRobot candidate's microSD slot.

## Smaller speaker recommendation

Sample a **wired 1511, 8-ohm, 0.5 W micro-speaker**. One supplier example is YUENENG YN-1511, listed as 15 × 11 × 3.2 mm with lead wires. Its [wholesale listing](https://germany.alibaba.com/product-detail/15MM-8-ohm-0-5w-95DB_1600587479460.html) showed EUR 0.2291 at 10–4,999 pieces; this is seller-advertised pricing, not a delivered USD quote or quality certification. Budget above allows more than that advertised unit price, but shipping and rejects remain separate. Require confirmation that the ordered variant actually includes wires and obtain its drawing/datasheet. "1511" is a size family, not an interchangeable qualified part number.

Use a clamped/gasketed mounting with the acoustic chamber/baffle appropriate to that speaker. Expect less bass/headroom than a larger speaker; assess creature sounds, melodies and speech-like samples at the intended volume. Check buzz/rattle, clipping and consistency across samples. Do not infer crispness from wattage or the listing's SPL number. Avoid spring-contact and unwired SMD variants for the student kit. The prior $2.81 Same Sky speaker is no longer the purchasing preference.

## Evidence and unresolved choices

- [Amazon screen](https://www.amazon.com/dp/B0DFWL25RB): retained by explicit user choice; price supplied by user. Verify delivered pinout and mechanical revision before layout.
- [UTC TDA2822L-D08-T at LCSC](https://www.lcsc.com/product-detail/C73295.html): DIP-8 amplifier candidate, listings approximately $0.14–0.23 per IC across quantities/retrievals. The row above includes support parts, not just the IC. [UTC datasheet](https://datasheet.lcsc.com/datasheet/pdf/8599ab4088134d37b4be13f0dc390034.pdf?productCode=C73295) specifies 1.8–12 V operation; qualify clean output at the actual supply and power-gate its idle current. No obsolete HT82V739 substitution or bare SMD amplifier on the main PCB.
- [Pololu S7V8F3](https://www.pololu.com/product/2122) is the documented regulator reference, not a proven final solution. Lower-cost module remains a sourcing target; reject buck-only/boost-only substitutes that cannot handle battery voltage crossing 3.3 V. Advertised module current is not established low-battery output capacity.
- [Waveshare S3 Zero family](https://www.waveshare.com/esp32-s3-zero.htm?sku=33879) provides a price/memory reference: an 8 MB-flash/8 MB-PSRAM version is advertised at $6.99 without headers. This is not the preferred 16 MB capacity, nor an approved kit core. Count only GPIO available through the actual THT headers; underside pads cannot be used to justify compatibility. Do not silently enlarge the toy or reduce storage to fit a cheap board.
- Existing power-module switch/current capacity, module USB backfeed, actual motor startup/stall, exact amplifier output and complete schematic/BOM remain qualification gates. No hardware or power-board files changed.

## What should feel premium

Spend effort on consistent switch force, a pivoted D-pad that avoids accidental opposite directions, closely guided caps without rattle, a flush supported screen window, a properly mounted speaker, short intentional vibration patterns, clean silkscreen and replaceable socketed modules. These are design objectives to validate in a physical kit; they are not achieved by a shopping list alone.

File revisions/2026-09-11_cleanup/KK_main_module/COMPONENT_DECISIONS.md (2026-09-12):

# Component decisions — 2026-09-10

**Latest decision — revision B:** return to ESP32-S3 SuperMini, nine-way sockets, separate revised power PCB, and SYS_IN on the THT main board. Routine software delivery by browser over Wi-Fi and wireless pet trading. See [current scope and limitations](component_review/REVISION_B.md); all contrary processor/power decisions below are history.

Planning record, not a released purchasing BOM or verified circuit. Later user messages override earlier specifications.

**Latest module permission:** the user now accepts a full-size development module and proposes Amazon B08D5ZD528. This supersedes the mini-only restriction. The linked ESP-WROOM-32 board is not an S3/PSRAM replacement; the listing photo shows micro-USB and no matching board-level power schematic has been qualified. Treat it as a user-proposed candidate, not a frozen BOM selection. See the [updated replacement review](component_review/MINI_MODULE_REPLACEMENT.md). No SMD rework is authorized.

**Latest sourcing review:** [single-board component register](component_review/README.md) and [datasheet archive](component_review/DATASHEETS.md). Battery brand/size is deferred by the user; define its electrical envelope now. The previous Teyleten selection is reopened because its header-only battery integration is not qualified. This review also corrects motor crimp selection and records a switch-height drawing conflict.

**Latest architecture amendment:** [integrated THT power](INTEGRATED_THT_POWER_REVISION.md) replaces the separate-power and regulator-breakout permissions below. Main-board charging/protection/regulation must use through-hole parts; screen, ESP32 module and battery remain separate. One external USB-C port must handle charging and data. Size is relaxed, not fixed. No exact integrated power circuit is selected yet.

Latest user amendment: **no XIAO; inexpensive off-brand parts preferred.** Exact processor listing supplied by user: Teyleten Robot ESP32S3SuperMini, Amazon B0D47HBFDY. The photographed ESP32-S3FH4R2 implies 4 MB flash / 2 MB PSRAM; incoming verification and memory-budget qualification remain required. See [entire-kit report](ENTIRE_KIT_PARTS.md), which supersedes the 16/8 recommendation and historical speaker/motor shortlists below. MCP23017-E/SP is the proposed THT expander; Adafruit 3101 is the soft-switch selection. Converter selection reopened with the processor change.

Latest purchasing direction: [budget parts list](BUDGET_PARTS_LIST.md). Retain the Amazon screen; suppliers are no longer restricted to Mouser. Replace the Same Sky speaker preference below with a sampled wired 1511 micro-speaker and seek a generic wired coin motor. Earlier supplier shortlists below are historical references, not active purchase selections.

## Confirmed by the user

- A preassembled regulator module with through-hole pins is permitted on the main board. Students must still assemble a through-hole kit; no main-board SMD soldering or hidden-pad connections. This exception does not authorize unrelated breakout substitutions.
- Charging/protection remains on the separate reusable power module. Its unregulated SYS_OUT feeds regulation on the main board; do not redesign the power module for convenience.
- The user chose to retain the Amazon XIITIA B0DFWL25RB 1.69-inch 240 × 280 display at their approximately $7.50-per-display benchmark. DFRobot and Adafruit alternatives are no longer preferred. Mouser-only sourcing is withdrawn; direct suppliers and wholesalers are permitted.
- No existing speaker or vibration assembly must be retained. Select affordable compact replacements and their necessary driver circuitry.

## Engineering recommendations, not user-approved exact parts

### Memory

Preferred target: **16 MB flash and 8 MB PSRAM on the preassembled compact ESP32-S3 module**. Flash holds firmware, update/recovery space, games/assets and saves; advertised capacity is not all downloadable storage. PSRAM is working memory, not persistent storage. Do not promise a game count before representative packages and firmware are built.

Use 8 MB flash as a cost/size fallback only after showing the tradeoff; do not silently substitute the earlier 4 MB-flash S3 MINI. A 2 MB-PSRAM implementation may be adequate for simple games, but must be benchmarked against the proposed app runtime. Prefer optional microSD expansion when the selected screen already provides a socket; the pet and bundled games should work without a card.

These capacities exist in small S3 boards, but do not establish a compatible kit module. For example, the [Seeed S3 Plus](https://wiki.seeedstudio.com/xiao_esp32s3_getting_started/) has 16 MB flash/8 MB PSRAM, but its additional GPIO access needs checking against the no-SMD/underside-pad requirement. Do not select it on dimensions and memory alone. Exact Mouser-sourced core, accessible GPIO count, supply isolation, sleep draw and footprint remain open.

### Speaker shortlist

**Same Sky CLS0201MA-L152**, Mouser **490-CLS0201MA-L152**: 8 ohm, 0.5 W nominal, 20 mm diameter × 3.8 mm deep, attached wires. [Manufacturer datasheet](https://www.sameskydevices.com/product/resource/cls0201ma-l152.pdf).

The [Mouser US page](https://www.mouser.com/ProductDetail/Same-Sky/CLS0201MA-L152?qs=WyjlAZoYn52yoRnHQzEFHQ%3D%3D) retrieved during this review lists $2.81 at quantity one, but cached prices vary; confirm at checkout. Shipping, tax and any listed surcharge are additional. No comparison with the unknown salvaged speaker has been measured.

Connect the wired speaker through a THT connector and provide mechanical retention/strain relief. Qualify the THT amplifier, filtering, clipping limit, quiet shutdown and enclosure baffle/gasket before claiming crisp audio. Speaker power rating is not a promise of amplifier output. Never drive it directly from GPIO. Earlier NJM2073D/HT82V739 proposals are not released parts; lifecycle and sourcing must be checked before adoption.

### Haptic shortlist

**SparkFun ROB-08449**, Mouser **474-ROB-08449**, wired coin ERM motor. [Mouser](https://www.mouser.com/en/ProductDetail/SparkFun/ROB-08449?qs=WyAARYrbSnZj6jJCAHtRrQ%3D%3D) lists $2.95 base price; shipping, tax and possible surcharge extra.

Its linked [manufacturer specification](https://cdn.sparkfun.com/datasheets/Robotics/B1034.FL45-00-015.pdf) identifies B1034.FL45-00-015, 10 mm diameter × 3.4 mm housing, 3.0 V nominal, 2.3–3.6 V operating range and 60 mA maximum rated running current. Running current is not startup/stall current; confirm delivered revision and actual peaks before driver release.

Prefer this simple motor plus THT transistor, flyback diode, bias/drive resistors, suppression and connector on the main board, rather than an extra haptic breakout. Use short rumble patterns; do not promise LRA-style sharp clicks. Feed from a reviewed regulated rail, not raw SYS_OUT or GPIO; default off during reset/sleep. Verify mounting, noise coupling, startup and total supply load.

## Remaining release gates

Exact core and regulator, amplifier, driver values, connector/cable parts, final display and total current budget remain unresolved. The existing power-path switch rating is still a gate: regulator-module permission does not increase upstream capacity. No schematic, PCB, power-board change, physical audio/haptic test or purchase was performed by this update.

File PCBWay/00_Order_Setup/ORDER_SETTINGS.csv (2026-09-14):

Field | Main C6 | Power P4 | Notes
Job scope | 5 bare PCBs | 5 assembled boards | Confirm fabrication attrition separately for power
Revision | C.6 | P.4 | Do not mix older revisions
Dimensions mm | 96 x 105 | 50 x 50 | Preserve actual Gerber outline; do not scale
Copper layers | 2 | 4 | Power F.Cu/In1.Cu/In2.Cu/B.Cu
Thickness mm | 1.6 nominal | 1.6 nominal | Confirm final stackup
Material | FR-4 | FR-4 | Confirm manufacturer grade and process
Copper | 35 um CAD nominal | 35 um CAD nominal layers | Confirm finished copper/plating; not a fabricated stackup approval
Mask/silkscreen | Green / white proposed | Green / white proposed | Cosmetic proposal; both supplied silk sides retained
Finish | Lead-free HASL proposed | ENIG proposed | Power flatness must suit 0.4 mm WCSP; assembler approval required
Via process | Review normal vias against files | Filled capped planarized component-pad vias REQUIRED | Tenting is not a substitute on power
Assembly | NO | YES: 108 positions per board | Power 104 SMT + 4 mixed/THT connectors
Stencil | Not requested | Assembler to quote/approve | Do not guess stencil thickness
Electrical test | Request bare-board net test | Request bare-board net test and assembly inspection | Functional testing is separate agreed scope
Battery / firmware / case | Not included | Not included | Do not attach an unspecified cell
Release status | Hold pending DFM/customer approval | Hold pending DFM/customer approval | No purchase or factory submission performed

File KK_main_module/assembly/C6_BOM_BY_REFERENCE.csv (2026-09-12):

Reference | Quantity | Value | MPN | Footprint | Side | Datasheet | Notes
C1 | 1 | 100u | ECEA1CKA101 | KK_Main:KA_100u_Flat | back | https://industrial.panasonic.com/cdbs/www-data/pdf/RDF0000/ABA0000C1050.pdf | 16V Panasonic KA-A, body horizontal on 0.5mm insulating support. Form leads with support at seal. Square pad 1 = positive. Maximum can envelope D6.8 x L8mm (100u) or D4.5 x L8mm (10u).
C2 | 1 | 100n | C315C104K5R5TA | KK_Main:KEMET_C315_P2p54 | back | https://yageogroup.com/download/specsheet/C315C104K5R5TA
C3 | 1 | 100u | ECEA1CKA101 | KK_Main:KA_100u_Flat | back | https://industrial.panasonic.com/cdbs/www-data/pdf/RDF0000/ABA0000C1050.pdf | 16V Panasonic KA-A, body horizontal on 0.5mm insulating support. Form leads with support at seal. Square pad 1 = positive. Maximum can envelope D6.8 x L8mm (100u) or D4.5 x L8mm (10u).
C4 | 1 | 100n | C315C104K5R5TA | KK_Main:KEMET_C315_P2p54 | back | https://yageogroup.com/download/specsheet/C315C104K5R5TA
C5 | 1 | 100u | ECEA1CKA101 | KK_Main:KA_100u_Flat | back | https://industrial.panasonic.com/cdbs/www-data/pdf/RDF0000/ABA0000C1050.pdf | 16V Panasonic KA-A, body horizontal on 0.5mm insulating support. Form leads with support at seal. Square pad 1 = positive. Maximum can envelope D6.8 x L8mm (100u) or D4.5 x L8mm (10u).
C6 | 1 | 100n | C315C104K5R5TA | KK_Main:KEMET_C315_P2p54 | back | https://yageogroup.com/download/specsheet/C315C104K5R5TA
C7 | 1 | 100n | C315C104K5R5TA | KK_Main:KEMET_C315_P2p54 | back | https://yageogroup.com/download/specsheet/C315C104K5R5TA
C8 | 1 | 100n | C315C104K5R5TA | KK_Main:KEMET_C315_P2p54 | back | https://yageogroup.com/download/specsheet/C315C104K5R5TA
C9 | 1 | 10u | ECEA1CKA100 | KK_Main:KA_10u_Flat | back | https://industrial.panasonic.com/cdbs/www-data/pdf/RDF0000/ABA0000C1050.pdf | 16V Panasonic KA-A, body horizontal on 0.5mm insulating support. Form leads with support at seal. Square pad 1 = positive. Maximum can envelope D6.8 x L8mm (100u) or D4.5 x L8mm (10u).
C10 | 1 | 100n | C315C104K5R5TA | KK_Main:KEMET_C315_P2p54 | back | https://yageogroup.com/download/specsheet/C315C104K5R5TA
C11 | 1 | 10u | ECEA1CKA100 | KK_Main:KA_10u_Flat | back | https://industrial.panasonic.com/cdbs/www-data/pdf/RDF0000/ABA0000C1050.pdf | 16V Panasonic KA-A, body horizontal on 0.5mm insulating support. Form leads with support at seal. Square pad 1 = positive. Maximum can envelope D6.8 x L8mm (100u) or D4.5 x L8mm (10u).
C12 | 1 | 100n | C315C104K5R5TA | KK_Main:KEMET_C315_P2p54 | back | https://yageogroup.com/download/specsheet/C315C104K5R5TA
C13 | 1 | 100u | ECEA1CKA101 | KK_Main:KA_100u_Flat | back | https://industrial.panasonic.com/cdbs/www-data/pdf/RDF0000/ABA0000C1050.pdf | 16V Panasonic KA-A, body horizontal on 0.5mm insulating support. Form leads with support at seal. Square pad 1 = positive. Maximum can envelope D6.8 x L8mm (100u) or D4.5 x L8mm (10u).
C14 | 1 | 100n | C315C104K5R5TA | KK_Main:KEMET_C315_P2p54 | back | https://yageogroup.com/download/specsheet/C315C104K5R5TA
C15 | 1 | 10u | ECEA1CKA100 | KK_Main:KA_10u_Flat | back | https://industrial.panasonic.com/cdbs/www-data/pdf/RDF0000/ABA0000C1050.pdf | 16V Panasonic KA-A, body horizontal on 0.5mm insulating support. Form leads with support at seal. Square pad 1 = positive. Maximum can envelope D6.8 x L8mm (100u) or D4.5 x L8mm (10u).
C16 | 1 | 100n | C315C104K5R5TA | KK_Main:KEMET_C315_P2p54 | back | https://yageogroup.com/download/specsheet/C315C104K5R5TA | Suppression physically close to motor leads
C17 | 1 | 100u | ECEA1CKA101 | KK_Main:KA_100u_Flat | back | https://industrial.panasonic.com/cdbs/www-data/pdf/RDF0000/ABA0000C1050.pdf | 16V Panasonic KA-A, body horizontal on 0.5mm insulating support. Form leads with support at seal. Square pad 1 = positive. Maximum can envelope D6.8 x L8mm (100u) or D4.5 x L8mm (10u).
C18 | 1 | 10n | C315C103J1G5TA | KK_Main:KEMET_C315_P2p54 | back | https://yageogroup.com/download/specsheet/C315C103J1G5TA
C19 | 1 | 10n | C315C103J1G5TA | KK_Main:KEMET_C315_P2p54 | back | https://yageogroup.com/download/specsheet/C315C103J1G5TA
C20 | 1 | 1u | C315C105K5R5TA | KK_Main:KEMET_C315_P2p54 | back | https://yageogroup.com/download/specsheet/C315C105K5R5TA
C21 | 1 | 10u | ECEA1CKA100 | KK_Main:KA_10u_Flat | back | https://industrial.panasonic.com/cdbs/www-data/pdf/RDF0000/ABA0000C1050.pdf | 16V Panasonic KA-A, body horizontal on 0.5mm insulating support. Form leads with support at seal. Square pad 1 = positive. Maximum can envelope D6.8 x L8mm (100u) or D4.5 x L8mm (10u).
C22 | 1 | 10n | C315C103J1G5TA | KK_Main:KEMET_C315_P2p54 | back | https://yageogroup.com/download/specsheet/C315C103J1G5TA
C23 | 1 | 100n | C315C104K5R5TA | KK_Main:KEMET_C315_P2p54 | back | https://yageogroup.com/download/specsheet/C315C104K5R5TA
C24 | 1 | 100n | C315C104K5R5TA | KK_Main:KEMET_C315_P2p54 | back | https://yageogroup.com/download/specsheet/C315C104K5R5TA
C25 | 1 | 100u | ECEA1CKA101 | KK_Main:KA_100u_Flat | back | https://industrial.panasonic.com/cdbs/www-data/pdf/RDF0000/ABA0000C1050.pdf | 16V Panasonic KA-A, body horizontal on 0.5mm insulating support. Form leads with support at seal. Square pad 1 = positive. Maximum can envelope D6.8 x L8mm (100u) or D4.5 x L8mm (10u).
C26 | 1 | 100n | C315C104K5R5TA | KK_Main:KEMET_C315_P2p54 | back | https://yageogroup.com/download/specsheet/C315C104K5R5TA
C27 | 1 | 100n | C315C104K5R5TA | KK_Main:KEMET_C315_P2p54 | back | https://yageogroup.com/download/specsheet/C315C104K5R5TA | C.5 local U4 bypass.
D1 | 1 | TSAL6200 | TSAL6200 | KK_Main:TSAL6200_C5_EdgeFormed | back | https://www.vishay.com/docs/81010/tsal6200.pdf | C.5 rear top-facing formed leads: nominal lens axis 5mm off rear PCB. Verify optical direction and lead form.
D2 | 1 | 1N5819 | 1N5819-E3/54 | KK_Main:1N5819_DO41 | back | https://www.vishay.com/docs/88525/1n5817.pdf
D3 | 1 | RGB mood / common anode | WP154A4SEJ3VBDZGW/CA | KK_Main:RGB_CA_5mm_Socketed | front | https://www.kingbrightusa.com/images/catalog/SPEC/WP154A4SEJ3VBDZGW-CA.pdf | C.6: Sullins PPTC041LFBN-RC socket, formed LED leads at 2.54mm. Actual lead retention qualification required. 1=R, 2=A+, 3=B, 4=G.
J1 | 1 | SYS_IN / JST-XH | B4B-XH-A(LF)(SN) | KK_Main:JST_XH_B4B_4 | back | https://www.jst-mfg.com/product/pdf/eng/eXH.pdf | 4-rail-interface pins include ground; future supply must sequence rails together
J2 | 1 | XIITIA TFT header | PPTC081LFBN-RC | KK_Main:Sullins_PPTC081_LFB | front | https://mm.digikey.com/Volume0/opasdata/d220001/medias/docus/937/Female_Headers.100_DS.pdf | Display module B0DFWL25RB is a separate assembly item
J3 | 1 | GODIYMODULES SD | PPTC061LFBN-RC | KK_Main:Sullins_PPTC061_LFB | back | https://mm.digikey.com/Volume0/opasdata/d220001/medias/docus/937/Female_Headers.100_DS.pdf | SD module B0F82XWT4F is a separate assembly item
J4 | 1 | LCM0827A3038F motor | B2B-PH-K-S(LF)(SN) | KK_Main:JST_PH_B2B_2 | back | https://www.jst-mfg.com/product/pdf/eng/ePH.pdf | C.5 top-entry connector: mating plug inserts perpendicular to rear PCB.
J5 | 1 | 8 ohm speaker | B2B-PH-K-S(LF)(SN) | KK_Main:JST_PH_B2B_2 | back | https://www.jst-mfg.com/product/pdf/eng/ePH.pdf | C.5 top-entry connector: mating plug inserts perpendicular to rear PCB.
MOD1 | 1 | ESP32-S3 SuperMini | Teyleten B0D47HBFDY | KK_Main:ESP32-S3-SuperMini | back | https://www.espressif.com/sites/default/files/documentation/esp32-s3_datasheet_en.pdf | Carrier pad numbering/voltage path requires delivered-module qualification
Q1 | 1 | KSP2222ABU | KSP2222ABU | KK_Main:TO92_Flat_P2p54 | back | https://www.onsemi.com/pdf/datasheet/ksp2222a-d.pdf | Horizontal TO-92, flat marked face up; formed 2.54mm lead spacing. Check actual device pinout; no pin swaps.
Q2 | 1 | KSP2222ABU | KSP2222ABU | KK_Main:TO92_Flat_P2p54 | back | https://www.onsemi.com/pdf/datasheet/ksp2222a-d.pdf | Horizontal TO-92, flat marked face up; formed 2.54mm lead spacing. Check actual device pinout; no pin swaps.
Q3 | 1 | BC32725BU | BC32725BU | KK_Main:TO92_Flat_P2p54 | back | https://www.onsemi.com/pub/Collateral/BC327-D.PDF | Horizontal TO-92, flat marked face up; formed 2.54mm lead spacing. Check actual device pinout; no pin swaps.
Q4 | 1 | TN0702N3-G | TN0702N3-G | KK_Main:TO92_Flat_P2p54 | back | https://ww1.microchip.com/downloads/en/DeviceDoc/TN0702-N-Channel-Enhancement-Mode-Vertical-DMOS-FET-Data-Sheet-20005941A.pdf | Horizontal TO-92, flat marked face up; formed 2.54mm lead spacing. Check actual device pinout; no pin swaps.
Q5 | 1 | TN0702N3-G | TN0702N3-G | KK_Main:TO92_Flat_P2p54 | back | https://ww1.microchip.com/downloads/en/DeviceDoc/TN0702-N-Channel-Enhancement-Mode-Vertical-DMOS-FET-Data-Sheet-20005941A.pdf | Horizontal TO-92, flat marked face up; formed 2.54mm lead spacing. Check actual device pinout; no pin swaps.
Q6 | 1 | LP0701N3-G | LP0701N3-G | KK_Main:TO92_Flat_P2p54 | back | https://ww1.microchip.com/downloads/en/DeviceDoc/LP0701-P-Channel-Enhancement-Mode-Lateral-MOSFET-Data-Sheet-20005447A.pdf | Horizontal TO-92, flat marked face up; formed 2.54mm lead spacing. Check actual device pinout; no pin swaps.
R1 | 1 | 4.7k | MFR-25FBF52-4K7 | KK_Main:MFR25_10p16 | back | https://yageogroup.com/content/Resource%20Library/Datasheet/YAGEO-MFR_DATASHEET.pdf | Horizontal axial body; 10.16mm pitch. No upright resistors.
R2 | 1 | 4.7k | MFR-25FBF52-4K7 | KK_Main:MFR25_10p16 | back | https://yageogroup.com/content/Resource%20Library/Datasheet/YAGEO-MFR_DATASHEET.pdf | Horizontal axial body; 10.16mm pitch. No upright resistors.
R3 | 1 | 10k | MFR-25FBF52-10K | KK_Main:MFR25_10p16 | back | https://yageogroup.com/content/Resource%20Library/Datasheet/YAGEO-MFR_DATASHEET.pdf | Horizontal axial body; 10.16mm pitch. No upright resistors.
R4 | 1 | 10k | MFR-25FBF52-10K | KK_Main:MFR25_10p16 | back | https://yageogroup.com/content/Resource%20Library/Datasheet/YAGEO-MFR_DATASHEET.pdf | Horizontal axial body; 10.16mm pitch. No upright resistors.
R5 | 1 | 10k | MFR-25FBF52-10K | KK_Main:MFR25_10p16 | back | https://yageogroup.com/content/Resource%20Library/Datasheet/YAGEO-MFR_DATASHEET.pdf | Horizontal axial body; 10.16mm pitch. No upright resistors.
R6 | 1 | 10k | MFR-25FBF52-10K | KK_Main:MFR25_10p16 | back | https://yageogroup.com/content/Resource%20Library/Datasheet/YAGEO-MFR_DATASHEET.pdf | Horizontal axial body; 10.16mm pitch. No upright resistors.
R7 | 1 | 10k | MFR-25FBF52-10K | KK_Main:MFR25_10p16 | back | https://yageogroup.com/content/Resource%20Library/Datasheet/YAGEO-MFR_DATASHEET.pdf | Horizontal axial body; 10.16mm pitch. No upright resistors.
R8 | 1 | 10k | MFR-25FBF52-10K | KK_Main:MFR25_10p16 | back | https://yageogroup.com/content/Resource%20Library/Datasheet/YAGEO-MFR_DATASHEET.pdf | Horizontal axial body; 10.16mm pitch. No upright resistors.
R9 | 1 | 10k | MFR-25FBF52-10K | KK_Main:MFR25_10p16 | back | https://yageogroup.com/content/Resource%20Library/Datasheet/YAGEO-MFR_DATASHEET.pdf | Horizontal axial body; 10.16mm pitch. No upright resistors.
R10 | 1 | 10k | MFR-25FBF52-10K | KK_Main:MFR25_10p16 | back | https://yageogroup.com/content/Resource%20Library/Datasheet/YAGEO-MFR_DATASHEET.pdf | Horizontal axial body; 10.16mm pitch. No upright resistors.
R11 | 1 | 10k | MFR-25FBF52-10K | KK_Main:MFR25_10p16 | back | https://yageogroup.com/content/Resource%20Library/Datasheet/YAGEO-MFR_DATASHEET.pdf | Horizontal axial body; 10.16mm pitch. No upright resistors.
R12 | 1 | 10k | MFR-25FBF52-10K | KK_Main:MFR25_10p16 | back | https://yageogroup.com/content/Resource%20Library/Datasheet/YAGEO-MFR_DATASHEET.pdf | Horizontal axial body; 10.16mm pitch. No upright resistors.
R13 | 1 | 10k | MFR-25FBF52-10K | KK_Main:MFR25_10p16 | back | https://yageogroup.com/content/Resource%20Library/Datasheet/YAGEO-MFR_DATASHEET.pdf | Horizontal axial body; 10.16mm pitch. No upright resistors.
R14 | 1 | 10k | MFR-25FBF52-10K | KK_Main:MFR25_10p16 | back | https://yageogroup.com/content/Resource%20Library/Datasheet/YAGEO-MFR_DATASHEET.pdf | Horizontal axial body; 10.16mm pitch. No upright resistors.
R15 | 1 | 10k | MFR-25FBF52-10K | KK_Main:MFR25_10p16 | back | https://yageogroup.com/content/Resource%20Library/Datasheet/YAGEO-MFR_DATASHEET.pdf | Horizontal axial body; 10.16mm pitch. No upright resistors.
R16 | 1 | 10k | MFR-25FBF52-10K | KK_Main:MFR25_10p16 | back | https://yageogroup.com/content/Resource%20Library/Datasheet/YAGEO-MFR_DATASHEET.pdf | Horizontal axial body; 10.16mm pitch. No upright resistors.
R17 | 1 | 10k | MFR-25FBF52-10K | KK_Main:MFR25_10p16 | back | https://yageogroup.com/content/Resource%20Library/Datasheet/YAGEO-MFR_DATASHEET.pdf | Horizontal axial body; 10.16mm pitch. No upright resistors.
R18 | 1 | 10k | MFR-25FBF52-10K | KK_Main:MFR25_10p16 | back | https://yageogroup.com/content/Resource%20Library/Datasheet/YAGEO-MFR_DATASHEET.pdf | Horizontal axial body; 10.16mm pitch. No upright resistors.
R19 | 1 | 4.7k | MFR-25FBF52-4K7 | KK_Main:MFR25_10p16 | back | https://yageogroup.com/content/Resource%20Library/Datasheet/YAGEO-MFR_DATASHEET.pdf | Horizontal axial body; 10.16mm pitch. No upright resistors.
R20 | 1 | 100k | MFR-25FBF52-100K | KK_Main:MFR25_10p16 | back | https://yageogroup.com/content/Resource%20Library/Datasheet/YAGEO-MFR_DATASHEET.pdf | Horizontal axial body; 10.16mm pitch. No upright resistors.
R21 | 1 | 220 | MFR-25FBF52-220R | KK_Main:MFR25_10p16 | back | https://yageogroup.com/content/Resource%20Library/Datasheet/YAGEO-MFR_DATASHEET.pdf | Horizontal axial body; 10.16mm pitch. No upright resistors.
R22 | 1 | 100k | MFR-25FBF52-100K | KK_Main:MFR25_10p16 | back | https://yageogroup.com/content/Resource%20Library/Datasheet/YAGEO-MFR_DATASHEET.pdf | Horizontal axial body; 10.16mm pitch. No upright resistors.
R23 | 1 | 100 | MFR-25FBF52-100R | KK_Main:MFR25_10p16 | back | https://yageogroup.com/content/Resource%20Library/Datasheet/YAGEO-MFR_DATASHEET.pdf | Horizontal axial body; 10.16mm pitch. No upright resistors.
R24 | 1 | 100 | MFR-25FBF52-100R | KK_Main:MFR25_10p16 | back | https://yageogroup.com/content/Resource%20Library/Datasheet/YAGEO-MFR_DATASHEET.pdf | Horizontal axial body; 10.16mm pitch. No upright resistors.
R25 | 1 | 1k | MFR-25FBF52-1K | KK_Main:MFR25_10p16 | back | https://yageogroup.com/content/Resource%20Library/Datasheet/YAGEO-MFR_DATASHEET.pdf | Horizontal axial body; 10.16mm pitch. No upright resistors.
R26 | 1 | 100k | MFR-25FBF52-100K | KK_Main:MFR25_10p16 | back | https://yageogroup.com/content/Resource%20Library/Datasheet/YAGEO-MFR_DATASHEET.pdf | Horizontal axial body; 10.16mm pitch. No upright resistors.
R27 | 1 | 100 | MFR-25FBF52-100R | KK_Main:MFR25_10p16 | back | https://yageogroup.com/content/Resource%20Library/Datasheet/YAGEO-MFR_DATASHEET.pdf | Horizontal axial body; 10.16mm pitch. No upright resistors.
R28 | 1 | 100 | MFR-25FBF52-100R | KK_Main:MFR25_10p16 | back | https://yageogroup.com/content/Resource%20Library/Datasheet/YAGEO-MFR_DATASHEET.pdf | Horizontal axial body; 10.16mm pitch. No upright resistors.
R29 | 1 | 100k | MFR-25FBF52-100K | KK_Main:MFR25_10p16 | back | https://yageogroup.com/content/Resource%20Library/Datasheet/YAGEO-MFR_DATASHEET.pdf | Horizontal axial body; 10.16mm pitch. No upright resistors.
R30 | 1 | 1k | MFR-25FBF52-1K | KK_Main:MFR25_10p16 | back | https://yageogroup.com/content/Resource%20Library/Datasheet/YAGEO-MFR_DATASHEET.pdf | Horizontal axial body; 10.16mm pitch. No upright resistors.
R31 | 1 | 1k | MFR-25FBF52-1K | KK_Main:MFR25_10p16 | back | https://yageogroup.com/content/Resource%20Library/Datasheet/YAGEO-MFR_DATASHEET.pdf | Horizontal axial body; 10.16mm pitch. No upright resistors.
R32 | 1 | 100k | MFR-25FBF52-100K | KK_Main:MFR25_10p16 | back | https://yageogroup.com/content/Resource%20Library/Datasheet/YAGEO-MFR_DATASHEET.pdf | Horizontal axial body; 10.16mm pitch. No upright resistors.
R33 | 1 | 1k | MFR-25FBF52-1K | KK_Main:MFR25_10p16 | back | https://yageogroup.com/content/Resource%20Library/Datasheet/YAGEO-MFR_DATASHEET.pdf | Horizontal axial body; 10.16mm pitch. No upright resistors.
R34 | 1 | 4.7 | MFR-25FBF52-4R7 | KK_Main:MFR25_10p16 | back | https://yageogroup.com/content/Resource%20Library/Datasheet/YAGEO-MFR_DATASHEET.pdf | Horizontal axial body; 10.16mm pitch. No upright resistors.
R35 | 1 | 4.7 | MFR-25FBF52-4R7 | KK_Main:MFR25_10p16 | back | https://yageogroup.com/content/Resource%20Library/Datasheet/YAGEO-MFR_DATASHEET.pdf | Horizontal axial body; 10.16mm pitch. No upright resistors.
R36 | 1 | 1k | MFR-25FBF52-1K | KK_Main:MFR25_10p16 | back | https://yageogroup.com/content/Resource%20Library/Datasheet/YAGEO-MFR_DATASHEET.pdf | Horizontal axial body; 10.16mm pitch. No upright resistors.
R37 | 1 | 100k | MFR-25FBF52-100K | KK_Main:MFR25_10p16 | back | https://yageogroup.com/content/Resource%20Library/Datasheet/YAGEO-MFR_DATASHEET.pdf | Horizontal axial body; 10.16mm pitch. No upright resistors.
R38 | 1 | 1k | MFR-25FBF52-1K | KK_Main:MFR25_10p16 | back | https://yageogroup.com/content/Resource%20Library/Datasheet/YAGEO-MFR_DATASHEET.pdf | Horizontal axial body; 10.16mm pitch. No upright resistors.
R39 | 1 | 100k | MFR-25FBF52-100K | KK_Main:MFR25_10p16 | back | https://yageogroup.com/content/Resource%20Library/Datasheet/YAGEO-MFR_DATASHEET.pdf | Horizontal axial body; 10.16mm pitch. No upright resistors.
R40 | 1 | 1.8k | MFR-25FBF52-1K8 | KK_Main:MFR25_10p16 | back | https://yageogroup.com/content/Resource%20Library/Datasheet/YAGEO-MFR_DATASHEET.pdf | Horizontal axial body; 10.16mm pitch. No upright resistors.
R41 | 1 | 10k | MFR-25FBF52-10K | KK_Main:MFR25_10p16 | back | https://yageogroup.com/content/Resource%20Library/Datasheet/YAGEO-MFR_DATASHEET.pdf | Horizontal axial body; 10.16mm pitch. No upright resistors.
R42 | 1 | 100k | MFR-25FBF52-100K | KK_Main:MFR25_10p16 | back | https://yageogroup.com/content/Resource%20Library/Datasheet/YAGEO-MFR_DATASHEET.pdf | Horizontal axial body; 10.16mm pitch. No upright resistors.
R43 | 1 | 100k | MFR-25FBF52-100K | KK_Main:MFR25_10p16 | back | https://yageogroup.com/content/Resource%20Library/Datasheet/YAGEO-MFR_DATASHEET.pdf | Horizontal axial body; 10.16mm pitch. No upright resistors.
SW1 | 1 | UP | Adafruit 3101 | KK_Main:Adafruit3101_ABCD | front | https://cdn-shop.adafruit.com/product-files/3101/C4817-001+datasheet.png | 200 ohm maximum closed contact resistance; custom footprint included; verify delivered switch fit and A/B versus C/D continuity
SW2 | 1 | DOWN | Adafruit 3101 | KK_Main:Adafruit3101_ABCD | front | https://cdn-shop.adafruit.com/product-files/3101/C4817-001+datasheet.png | 200 ohm maximum closed contact resistance; custom footprint included; verify delivered switch fit and A/B versus C/D continuity
SW3 | 1 | LEFT | Adafruit 3101 | KK_Main:Adafruit3101_ABCD | front | https://cdn-shop.adafruit.com/product-files/3101/C4817-001+datasheet.png | 200 ohm maximum closed contact resistance; custom footprint included; verify delivered switch fit and A/B versus C/D continuity
SW4 | 1 | RIGHT | Adafruit 3101 | KK_Main:Adafruit3101_ABCD | front | https://cdn-shop.adafruit.com/product-files/3101/C4817-001+datasheet.png | 200 ohm maximum closed contact resistance; custom footprint included; verify delivered switch fit and A/B versus C/D continuity
SW5 | 1 | A | Adafruit 3101 | KK_Main:Adafruit3101_ABCD | front | https://cdn-shop.adafruit.com/product-files/3101/C4817-001+datasheet.png | 200 ohm maximum closed contact resistance; custom footprint included; verify delivered switch fit and A/B versus C/D continuity
SW6 | 1 | B | Adafruit 3101 | KK_Main:Adafruit3101_ABCD | front | https://cdn-shop.adafruit.com/product-files/3101/C4817-001+datasheet.png | 200 ohm maximum closed contact resistance; custom footprint included; verify delivered switch fit and A/B versus C/D continuity
SW7 | 1 | X | Adafruit 3101 | KK_Main:Adafruit3101_ABCD | front | https://cdn-shop.adafruit.com/product-files/3101/C4817-001+datasheet.png | 200 ohm maximum closed contact resistance; custom footprint included; verify delivered switch fit and A/B versus C/D continuity
SW8 | 1 | Y | Adafruit 3101 | KK_Main:Adafruit3101_ABCD | front | https://cdn-shop.adafruit.com/product-files/3101/C4817-001+datasheet.png | 200 ohm maximum closed contact resistance; custom footprint included; verify delivered switch fit and A/B versus C/D continuity
SW9 | 1 | FN | Adafruit 3101 | KK_Main:Adafruit3101_ABCD | front | https://cdn-shop.adafruit.com/product-files/3101/C4817-001+datasheet.png | 200 ohm maximum closed contact resistance; custom footprint included; verify delivered switch fit and A/B versus C/D continuity
U1 | 1 | MCP23017-E/SP | MCP23017-E/SP | KK_Main:ED281DT_DIP28_Socket | back | https://ww1.microchip.com/downloads/aemDocuments/documents/APID/ProductDocuments/DataSheets/MCP23017-Data-Sheet-DS20001952.pdf
U2 | 1 | TSOP38238 | TSOP38238 | KK_Main:TSOP38238_Vertical | back | https://www.vishay.com/docs/82491/tsop382.pdf
U3 | 1 | TDA2822L-D08-T | TDA2822L-D08-T | KK_Main:ED08DT_DIP8_Socket | back | https://datasheet.lcsc.com/datasheet/pdf/8599ab4088134d37b4be13f0dc390034.pdf
U4 | 1 | TLC5916IN | TLC5916IN | KK_Main:ED16DT_DIP16_Socket | back | https://www.ti.com/lit/ds/symlink/tlc5916.pdf | C.6: 3.3 V logic, 5 V common-anode LED. OE high until zero data is latched.

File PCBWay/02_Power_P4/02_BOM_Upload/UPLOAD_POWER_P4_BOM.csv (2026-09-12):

References | Value | MPN | Footprint | Assembly | Datasheet | Quantity per board | Quantity for 5 (no attrition)
C1, C71, C72 | 1u | GRM188R71C105KA12D | KK_Power:C_0603_1608Metric | SMT |  | 3 | 15
C2, C25, C35, C45, C51, C6, C60, C70, C9 | 100n | GRM188R71C104KA01D | KK_Power:C_0603_1608Metric | SMT |  | 9 | 45
C20, C21, C30, C31, C4, C40, C41 | 10u | GRM21BR61C106KE15L | KK_Power:C_0805_2012Metric | SMT |  | 7 | 35
C22, C23, C24, C32, C33, C34, C42, C43, C44, C5, C8 | 22u | GRM21BR61C226ME44L | KK_Power:C_0805_2012Metric | SMT |  | 11 | 55
C28, C38, C48 | 10p | GRM1885C1H100JA01D | KK_Power:C_0603_1608Metric | SMT |  | 3 | 15
C3 | 4.7u | GRM21BR71C475KA73L | KK_Power:C_0805_2012Metric | SMT |  | 1 | 5
C52, C53, C54, C7 | 10n | GRM188R71H103KA01D | KK_Power:C_0603_1608Metric | SMT |  | 4 | 20
D1 | SMAJ5.0A | SMAJ5.0A | KK_Power:D_SMA | SMT |  | 1 | 5
F1 | 4A FAST | 0451004.MRL | KK_Power:Fuse_1206_3216Metric | SMT |  | 1 | 5
J1 | USB-C CHARGE ONLY | HC-TYPE-C-16P-01A | KK_Power:USB_C_HCTL | THT/mixed | https://datasheet.lcsc.com/lcsc/2211161000_HCTL-HC-TYPE-C-16P-01A_C2894897.pdf | 1 | 5
J2 | 1S CELL / VH | B2P-VH(LF)(SN) | KK_Power:JST_VH_B2P-VH_1x02_P3.96mm_Vertical | THT/mixed |  | 1 | 5
J3 | C.5 SYS_IN / XH | B4B-XH-A(LF)(SN) | KK_Power:JST_XH_B4B-XH-A_1x04_P2.50mm_Vertical | THT/mixed |  | 1 | 5
J4 | BATTERY NTC | B2B-PH-K-S(LF)(SN) | KK_Power:JST_PH_B2B-PH-K_1x02_P2.00mm_Vertical | THT/mixed |  | 1 | 5
L1, L2, L3 | 1uH | XFL4020-102MEC | KK_Power:L_Coilcraft_XxL4020 | SMT | https://www.coilcraft.com/getmedia/50632d43-da1b-4cdb-8ab4-3029cab51df3/xfl4020.pdf | 3 | 15
LED1 | POWER GOOD | APT3216LZGCK | KK_Power:LED_1206_3216Metric | SMT |  | 1 | 5
LED2 | CHARGING | APT3216SURCK | KK_Power:LED_1206_3216Metric | SMT |  | 1 | 5
Q1, Q2, Q3 | FS8205 | FS8205 | KK_Power:FS8205 | SMT | https://www.ic-fortune.com/upload/Download/FS8205-DS-19_EN.pdf | 3 | 15
Q4, Q5 | AO3400A | AO3400A | KK_Power:SOT-23 | SMT | https://www.aosmd.com/sites/default/files/res/datasheets/AO3400A.pdf | 2 | 10
R1 | 887k | RC0603FR07887KL | KK_Power:R_0603_1608Metric | SMT |  | 1 | 5
R10 | 182k | RT0603BRD07182KL | KK_Power:R_0603_1608Metric | SMT |  | 1 | 5
R11, R31, R41, R62, R64, R66 | 100k | RT0603BRD07100KL | KK_Power:R_0603_1608Metric | SMT |  | 6 | 30
R12 | 620 | RC0603FR07620RL | KK_Power:R_0603_1608Metric | SMT |  | 1 | 5
R13, R51, R72, R73 | 100k | RC0603FR07100KL | KK_Power:R_0603_1608Metric | SMT |  | 4 | 20
R14, R3, R60 | 10k | RC0603FR0710KL | KK_Power:R_0603_1608Metric | SMT |  | 3 | 15
R2, R6, R7 | 4.7k | RC0603FR074K7L | KK_Power:R_0603_1608Metric | SMT |  | 3 | 15
R20 | 909k | RT0603BRD07909KL | KK_Power:R_0603_1608Metric | SMT |  | 1 | 5
R21 | 101k | RT0603BRD07101KL | KK_Power:R_0603_1608Metric | SMT |  | 1 | 5
R30 | 560k | RT0603BRD07560KL | KK_Power:R_0603_1608Metric | SMT |  | 1 | 5
R4 | 2.94k | RT0603BRD072K94L | KK_Power:R_0603_1608Metric | SMT |  | 1 | 5
R40, R43 | 270k | RT0603BRD07270KL | KK_Power:R_0603_1608Metric | SMT |  | 2 | 10
R5 | 1.3k | RC0603FR071K3L | KK_Power:R_0603_1608Metric | SMT |  | 1 | 5
R50 | 470k | RC0603FR07470KL | KK_Power:R_0603_1608Metric | SMT |  | 1 | 5
R52, R53, R54 | 100 | RC0603FR07100RL | KK_Power:R_0603_1608Metric | SMT |  | 3 | 15
R61 | 1060k | RT0603BRD071M06L | KK_Power:R_0603_1608Metric | SMT |  | 1 | 5
R63 | 665k | RT0603BRD07665KL | KK_Power:R_0603_1608Metric | SMT |  | 1 | 5
R65 | 649k | RT0603BRD07649KL | KK_Power:R_0603_1608Metric | SMT |  | 1 | 5
R70 | 19.2k | RT0603BRD0719K2L | KK_Power:R_0603_1608Metric | SMT |  | 1 | 5
R71 | 634 | RT0603BRD07634RL | KK_Power:R_0603_1608Metric | SMT |  | 1 | 5
R74 | 31.6k | RT0603BRD0731K6L | KK_Power:R_0603_1608Metric | SMT |  | 1 | 5
R75 | 20k | RT0603BRD0720KL | KK_Power:R_0603_1608Metric | SMT |  | 1 | 5
R8 | 470 | RC0603FR07470RL | KK_Power:R_0603_1608Metric | SMT |  | 1 | 5
R9 | 1k | RC0603FR071KL | KK_Power:R_0603_1608Metric | SMT |  | 1 | 5
SW1 | OFF / ON | JS102011SAQN | KK_Power:SW_SPDT_CK_JS102011SAQN | SMT | https://www.ckswitches.com/media/1422/js.pdf | 1 | 5
U1 | BQ24075TRGTR | BQ24075TRGTR | KK_Power:VQFN-16-1EP_3x3mm_P0.5mm_EP1.6x1.6mm | SMT | https://www.ti.com/lit/ds/symlink/bq24075t.pdf | 1 | 5
U10, U8, U9 | TPS22918DBVR | TPS22918DBVR | KK_Power:SOT-23-6 | SMT | https://www.ti.com/lit/ds/symlink/tps22918.pdf | 3 | 15
U11 | SN74AUP1G17DBVR | SN74AUP1G17DBVR | KK_Power:SOT-23-5 | SMT | https://www.ti.com/lit/ds/symlink/sn74aup1g17.pdf | 1 | 5
U12 | TPS386000RGPR | TPS386000RGPR | KK_Power:Texas_RGP0020D_VQFN-20-1EP_4x4mm_P0.5mm_EP2.7x2.7mm | SMT | https://www.ti.com/lit/ds/symlink/tps386000.pdf | 1 | 5
U13 | TPS22950YBHR | TPS22950YBHR | KK_Power:TPS22950_YBH | SMT | https://www.ti.com/lit/ds/symlink/tps22950.pdf | 1 | 5
U14 | TLV75533PDBVR | TLV75533PDBVR | KK_Power:SOT-23-5 | SMT | https://www.ti.com/lit/ds/symlink/tlv755p.pdf | 1 | 5
U2 | DW01A / H&M | DW01A | KK_Power:SOT-23-6 | SMT | https://hmsemi.com/downfile/DW01A.PDF | 1 | 5
U3 | TUSB320LAIRWBR | TUSB320LAIRWBR | KK_Power:Texas_X2QFN-12_1.6x1.6mm_P0.4mm | SMT | https://www.ti.com/lit/ds/symlink/tusb320lai.pdf | 1 | 5
U4 | TPS259530DSGR | TPS259530DSGR | KK_Power:Texas_DSG0008A_WSON-8-1EP_2x2mm_P0.5mm_EP0.9x1.6mm | SMT | https://www.ti.com/lit/ds/symlink/tps2595.pdf | 1 | 5
U5, U6, U7 | TPS63060DSCR | TPS63060DSCR | KK_Power:Texas_S-PWSON-N10 | SMT | https://www.ti.com/lit/ds/symlink/tps63060.pdf | 3 | 15

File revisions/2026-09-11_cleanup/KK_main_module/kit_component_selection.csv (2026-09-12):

section | quantity_or_order_code | item_or_value | selection_or_role | qualification
1. Main electronics and external assemblies | 1 | Processor | Teyleten Robot ESP32S3SuperMini, Amazon B0D47HBFDY, three-pack | User-supplied exact listing; selected for prototype qualification. Listing close-up shows ESP32-S3FH4R2: 4 MB flash / 2 MB PSRAM, NOT the previous 16/8 target. Photos show two nine-pin THT rows and included male headers; onboard antenna. One three-pack supplies three kits. Confirm actual chip identity, PSRAM initialization, header measurements and power schematic on received boards.
1. Main electronics and external assemblies | Included | Wireless antenna | Processor board's onboard antenna | No separate Seeed antenna or antenna purchase. Keep clearance around the actual antenna location.
1. Main electronics and external assemblies | 1 | GPIO expander | Microchip MCP23017-E/SP | 28-pin narrow DIP, student THT. This replaces the smaller eight-bit expander shortlist.
1. Main electronics and external assemblies | 1 | Display | XIITIA Amazon B0DFWL25RB | Retain user's 1.69-inch 240 × 280 SPI screen. An ASIN is a seller identity, not a controlled manufacturer revision: inspect delivered pinout and backlight circuitry.
1. Main electronics and external assemblies | 9 | Soft switches | Adafruit 3101, pack of ten | Actual elastomer soft-action THT switches, approximately 7.8 × 7.8 × 4.9 mm. One pack gives nine controls plus one spare. Operating force is not specified; sample before freezing the footprint/cap travel.
1. Main electronics and external assemblies | 1 | Main-board converter | Selection reopened after processor change | The $9.95 Pololu S7V8F5 / 2123 is only a documented comparison, not an active kit purchase. Seek lower-cost fixed-output buck-boost module with THT pins, documented input range/current and suitable power-off behavior. Output voltage depends on the exact SuperMini supply circuit.
1. Main electronics and external assemblies | 1 | Audio amplifier | UTC TDA2822L-D08-T, LCSC C73295 | DIP-8 THT. Proposed mono bridge configuration with PWM filtering, attenuation and switched supply. Requires circuit/audio test, not a guaranteed 0.5 W clean output.
1. Main electronics and external assemblies | 1 | Small speaker | FUET / Taizhou Fusheng FS1511P08-H3.0, wired version | 15 × 11 mm micro-speaker, 8 ohm. Request drawing, thickness, nominal power and sample: listing mixes 0.5 W and 1 W. Advertised price is not a delivered quote.
1. Main electronics and external assemblies | 1 | Haptic motor | LEADER LCM0827A3038F, LCSC C2759981 | Sample candidate. Manufacturer specification gives 3 V nominal, 2.7–3.3 V operation, 80 mA maximum rated current and 120 mA starting current under its test conditions. Confirm lead-wire version and mechanical drawing; do not substitute contact-pad termination.
1. Main electronics and external assemblies | 1 | IR emitter | Vishay TSAL6200 | 940 nm, 5 mm leaded LED; transistor driver and current limiting required.
1. Main electronics and external assemblies | 1 | IR receiver | Vishay TSOP38238 | Leaded, demodulating 38 kHz receiver. Supports a defined remote-control/IR-trading protocol; not an arbitrary-frequency IR analyzer.
1. Main electronics and external assemblies | Schematic-set | NPN drivers/buffers | onsemi KSP2222ABU | TO-92. IR, motor, status conditioning and high-side-switch control. Exact count and drive resistors await schematic.
1. Main electronics and external assemblies | Schematic-set | PNP high-side switches | onsemi BC32725BU | TO-92. Proposed audio/peripheral/battery-sense switching. Check voltage drop, base drive, off-state leakage and different pin order from KSP2222A.
1. Main electronics and external assemblies | At least 1 | Motor flyback diode | Vishay 1N5819-E3/54 | Axial DO-41. Additional protection-diode count depends on the final supply circuit.
1. Main electronics and external assemblies | 1 | Main PCB | Custom KK_main_module, revision not assigned | Bare two-layer THT PCB. Trial 50 × 65 mm outline only; final outline, finish, holes and fabrication files do not exist yet.
2. Sockets, headers and harnesses | 2 | Nine-way THT female sockets, exact order code pending | Must match the sampled SuperMini, not the withdrawn seven-way XIAO sockets. Include full mated height in the stack. | See report; not production-released
2. Sockets, headers and harnesses | 2 | Nine-way male headers included with sample reference | Verify low-cost supplier includes them; otherwise add exact matching headers. No underside SMD wiring. | See report; not production-released
2. Sockets, headers and harnesses | 1 | On Shore ED281DT | 28-pin 7.62 mm row spacing DIP socket for MCP23017; not the wider ED28DT. | See report; not production-released
2. Sockets, headers and harnesses | 1 | On Shore ED08DT | Eight-pin DIP socket for amplifier. | See report; not production-released
2. Sockets, headers and harnesses | 1 | Sullins PPTC081LFBN-RC | Eight-way THT display socket, conditional on measured screen header orientation/stack. | See report; not production-released
2. Sockets, headers and harnesses | 1 | Sullins PPTC041LFBN-RC | Four-way THT regulator socket. The converter includes a male header; do not buy a second one unnecessarily. | See report; not production-released
2. Sockets, headers and harnesses | 3 | JST S2B-PH-K-S(LF)(SN) | Main-board SYS input, speaker and motor connectors. Clearly differentiate electrically incompatible two-pin ports with labeling and harness routing. | See report; not production-released
2. Sockets, headers and harnesses | 4 | JST PHR-2 | Two SYS-cable ends, one speaker plug and one motor plug. Battery plug is additional only if not already supplied on the pack. | See report; not production-released
2. Sockets, headers and harnesses | 8 | JST SPH-002T-P0.5S | Contacts for the four housings above. Factory-prepared cables preferred; verify the actual speaker/motor wire gauge fits this contact before crimping. | See report; not production-released
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

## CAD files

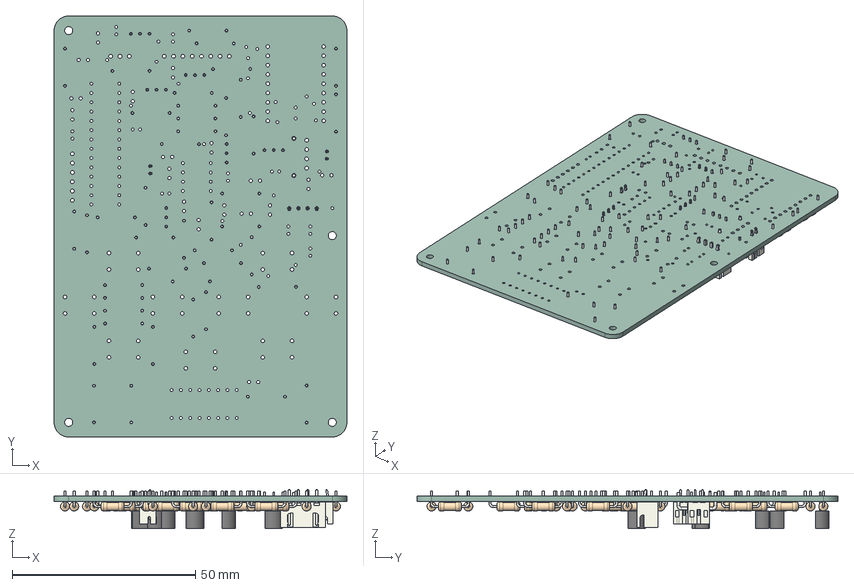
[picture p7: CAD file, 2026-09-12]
revisions/2026-09-11_cleanup/KK_main_module/pcb/KK_main_module_C4_assembly.step
80.0 x 115.0 x 10.7 mm
R_Axial_DIN0207_L63mm_D25mm_P1016mm_Horizontal x 43
TO-92_Inline_Wide x 6
JST_B2B_PH_K x 2
JST_B4B_XH_A
D_DO-41_SOD81_P10.16mm_Horizontal
KK_main_module_PCB

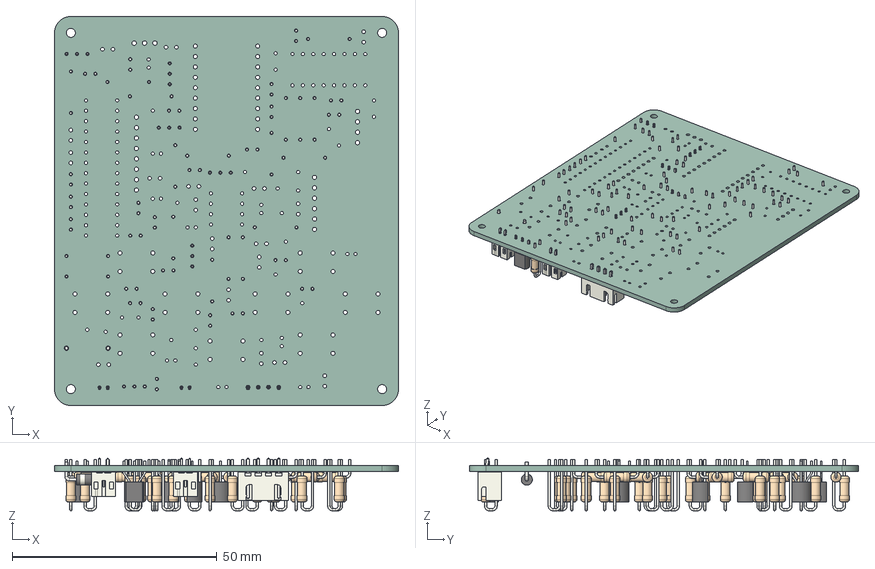
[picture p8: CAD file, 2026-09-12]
revisions/2026-09-12_current_only/KK_main_module/C5_relayout/KK_main_module_C5_assembly.step
84.0 x 95.0 x 12.9 mm
R_Axial_DIN0207_L63mm_D25mm_P254mm_Vertical x 25
R_Axial_DIN0207_L63mm_D25mm_P1016mm_Horizontal x 18
TO-92_Inline_Wide x 6
JST_B2B_PH_K x 2
JST_B4B_XH_A
D_DO-41_SOD81_P10.16mm_Horizontal
KK_main_module_PCB

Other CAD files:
KK_main_module/3dmodels/KA_100u_horizontal_max.step
KK_main_module/manufacturing/KK_MAIN_C6_P4_PAIRING_5_PROTOTYPE_REVIEW_2026-09-12/cad/3dmodels/Kingbright_RGB_socketed.step
KK_power_module/3dmodels/P3_JS102_envelope.step
KK_power_module/manufacturing/KK_POWER_P4_5_PROTOTYPE_REVIEW_2026-09-12/cad/3dmodels/P3_DSG8_max.step
revisions/2026-09-12_current_only/KK_main_module/3dmodels/Socketed_DIP16.step
revisions/2026-09-12_power_compact/P4_candidate/3dmodels/P3_USB_HCTL_envelope.step
revisions/2026-09-12_power_compact/unissued_export_1/KK_main_module/manufacturing/KK_MAIN_C6_P4_PAIRING_5_PROTOTYPE_REVIEW_2026-09-12/cad/3dmodels/KEMET_C315_max.step
KK_main_module/3dmodels/TO92_horizontal_envelope.step
KK_main_module/manufacturing/KK_MAIN_C6_P4_PAIRING_5_PROTOTYPE_REVIEW_2026-09-12/cad/3dmodels/TSAL6200_IR.step
KK_power_module/3dmodels/P3_RWB12_max.step
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

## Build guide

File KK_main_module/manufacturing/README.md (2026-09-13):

# Current C6 / C6-P4 pairing files

[Full five-sample review ZIP](KK_MAIN_C6_P4_PAIRING_5_PROTOTYPE_REVIEW_2026-09-12.zip) · [Gerbers and drills](KK_MAIN_C6_P4_PAIRING_GERBERS.zip)

Read fabrication requirements before ordering. Engineering review only; DFM, physical fit and powered qualification remain open. Old packages are archived under revisions/2026-09-12_power_compact/P3_previous at the repository root.

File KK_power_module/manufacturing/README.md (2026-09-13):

# Current P4 / C6-P4 pairing files

[Full five-sample review ZIP](KK_POWER_P4_5_PROTOTYPE_REVIEW_2026-09-12.zip) · [Gerbers and drills](KK_POWER_P4_GERBERS.zip)

Read fabrication requirements before ordering. Engineering review only; DFM, physical fit and powered qualification remain open. Old packages are archived under revisions/2026-09-12_power_compact/P3_previous at the repository root.

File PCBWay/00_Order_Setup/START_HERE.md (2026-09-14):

# Start here — two jobs, one prototype project

1. Create a **main C.6 bare-PCB** quote, quantity 5: 96 × 105 mm, two copper layers, 1.6 mm.
2. Create a **power P.4 PCB + assembly** quote for **five finished assemblies**: 50 × 50 mm, four copper layers, 1.6 mm. Ask PCBWay to quote any extra bare boards/parts needed for assembly attrition separately.
3. Upload each board's Gerber ZIP from its own `01_Gerber_Upload` folder. Upload power BOM and placement separately when prompted.
4. Attach fabrication requirements, assembly references and the complete review ZIP for the correct board to engineering correspondence.
5. Send [QUOTE_REQUEST.txt](QUOTE_REQUEST.txt). Review the factory's response before authorizing manufacturing.

Use [ORDER_SETTINGS.csv](ORDER_SETTINGS.csv) for the quote form. Fields marked **proposed** or **confirm** are not approved final process specifications. Prefer standard green mask/white silkscreen for this prototype; those colors are a proposed cosmetic selection only. Lead-free HASL is proposed for main THT; ENIG is proposed for the power board's fine-pitch lands. PCBWay must approve finish, copper, stackup and via process.

Do not select ordinary via tenting in place of filled/capped/planarized component-pad vias on power. Do not silently accept a two-layer power-board quote. No impedance-control certification is requested; no approved custom fabrication stackup is supplied.

The main board is a student soldering kit: no main-board assembly or main stencil is requested. The power board is factory assembled. Ask PCBWay to handle stencil, assembly panel tooling and any connector secondary operations in its quote, with no changes to finished outlines or hole locations without approval.

Open items that do not disappear when the factory accepts the files: actual module/connector fit, cell and NTC selection, regulated-rail load/thermal/startup testing, the 3.3 V reservation discrepancy (0.5 A main versus 0.4 A power screening), and firmware. These are engineering samples, not a classroom-ready toy.

No account, shipping address, payment information, factory approval or order number is prefilled. Complete those yourself in the later folders/site.

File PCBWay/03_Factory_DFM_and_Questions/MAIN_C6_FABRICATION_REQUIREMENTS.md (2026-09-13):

# C.6 main — five bare prototype PCBs

96 x 105 x 1.6 mm, two copper layers (F.Cu/B.Cu), R4 corners. Four 2.2 mm M2 NPTH holes at (4,4), (92,4), (4,101), (92,101) mm. Do not scale or panelize without preserving the supplied board outline and hole registration. Standard FR-4; CAD nominal 35um copper. Confirm finished copper/plating and lead-free surface finish with fabricator. No battery or charger circuit is on this PCB.

Use BOTH copper, BOTH mask, BOTH silkscreen, Edge.Cuts and BOTH PTH/NPTH drills. Empty paste files intentionally omitted: main-board kit assembly is through-hole, with preassembled socketed modules. 98 electrical positions, 25 bare debugging holes and four mounting holes. No fitted pins in the debug holes beneath other parts. IPC-D-356 provided for bare-board net testing.

All 43 resistors are horizontal, ten electrolytics and six TO-92 bodies lie flat per assembly drawings. Correct lead forms and polarity remain essential. Sockets, optics and buttons retain functional height. See the assembly kit extras separately; BOM chip/module positions do not replace the additional sockets and mating plugs.

Engineering prototype only. Confirm actual part fit, socket retention, inter-board plug/wire clearance and fabrication DFM before ordering. Main C.6 pairs with power P.4; do not mix older C.5/P.2 Gerbers.

C.6 copper, drill and native CAD are unchanged. This refreshed package updates documentation for the compact P.4 pairing; separate mounting supports are required.

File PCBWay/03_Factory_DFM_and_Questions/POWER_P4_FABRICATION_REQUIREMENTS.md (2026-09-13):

# Required DFM response — 5 × P.4 power modules

**Engineering review/quotation only. Do not fabricate or substitute parts until the customer approves your DFM response.**

| Item | Requested specification / required confirmation |
|---|---|
| Quantity | Five assembled engineering samples; quote assembly attrition separately |
| Board | 50 × 50 mm, 1.6 mm nominal, R3 corners, four 2.2 mm M2 clearance holes |
| Layer order | F.Cu / In1.Cu / In2.Cu / B.Cu; use all four supplied copper files |
| Copper / stackup | CAD nominal 35 µm copper layers; confirm actual finished stackup and plating before build |
| Routing / drills | CAD minimum track 0.15 mm; smallest via drill 0.20 mm, smallest via diameter 0.50 mm; check all fine-pitch land patterns |
| Via-in-pad | **Filled, capped, planarized** component-pad vias; coordinate exact process with assembler. Bare tenting is NOT sufficient |
| Via identification | `VIA_IN_PAD_REVIEW.csv` lists via centers inside front SMD lands; evaluate all land/via overlaps from CAD/Gerbers, including partial overlaps |
| Surface finish | Confirm a finish and flatness suitable for 0.4 mm-pitch WCSP; propose ENIG if supported |
| Soldermask / stencil | Confirm fine-pitch mask registration, paste apertures, thermal-pad windowing and stencil thickness |
| Critical package | U13 **TPS22950YBHR**, base variant, six-ball 0.4 mm-pitch WCSP. Do not substitute C/L variants or another package without circuit review |
| Other packages | QFN/WSON and 0.4/0.5 mm-pitch devices; confirm placement/reflow capability and inspection of hidden joints |
| Assembly | 108 fitted electrical parts per board; front-side assembly with THT/mixed connector/switch operations |
| Do not fit | 28 rear bare test pads, four mounting holes, and two silkscreen logo footprints |
| Placement | `POSITIONS_NATIVE.csv`: native KiCad mm/Y-up export. `BOM_AND_PLACEMENT.csv`: reference CAD mm/Y-down coordinates. Validate rotations, polarity and origin before machine programming |
| Net testing | Use supplied IPC-D-356 netlist and bare-board electrical test; retain test results |
| Substitutions | Written approval required, including capacitors' effective DC-bias capacitance, FET package/pinout, charger T variant, regulators, NTC and connector families |
| Testing scope | Do not attach an unspecified battery. Follow the included current-limited bench procedure after inspection |

The silkscreen OSHW mark is not a certification ID. This request does not claim USB, battery, toy-safety or EMC certification. Report any process or supply limitation before proceeding.

Mounting centers in native top-left-origin coordinates: (3,3), (47,3), (3,47), (47,47) mm. Do not enlarge the outline to match main C.6. P.4 needs separate case supports.

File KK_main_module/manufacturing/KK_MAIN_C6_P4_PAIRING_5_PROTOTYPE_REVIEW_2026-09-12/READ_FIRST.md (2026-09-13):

# C6 — five engineering samples; not production approval

Current editable project: KK_main_module at the repository root. This package is the C6/P4 pairing release. Open cad/KK_main_module.kicad_pro with KiCad 10 and its standard libraries. Custom assets and selected datasheets are included.

Main C.6: 96 x 105 x 1.6 mm, R4, TWO copper layers. Power P.4: 50 x 50 x 1.6 mm, R3, FOUR copper layers. Four 2.2 mm mounting holes on each board, DIFFERENT patterns: use independent case supports. Main CAD/fabrication geometry is unchanged; its documentation is refreshed. Do not use the old common-hole/20 mm shared-spacer instructions. Separate 1:1 templates are included; physical placement, antenna clearance, battery location and spacing are not approved.

fabrication/: Gerbers, separate PTH/NPTH drills, maps/report and IPC-D-356 netlist. Obtain factory DFM approval BEFORE ordering. Power requires filled/capped/planarized via-in-pad and 0.4 mm WCSP assembly approval; ordinary tenting is insufficient. No unreviewed substitutions.

assembly/: BOMs, placement, test-point and connector maps, schematic PDF, assembly/bench guides and paired-kit extras. Extras apply ONCE per pair. References to repository-relative datasheets in kit CSVs refer to the full repository; the selected board's datasheets are under cad/datasheets. Reference positions use CAD X-right/Y-down; POSITIONS_NATIVE.csv uses native KiCad Y-up. Assembler must validate rotations, origins, side, polarity and THT secondary operations before machine programming. Main is a student THT kit; power is factory SMT.

drawings/: assembly/body drawings and model previews; bottom views are mirrored. Model coverage is not delivered-part fit certification. verification/: fresh native checks, static audit and source hashes; ignored-check settings are recorded, not hidden.

Power J3 to main J1: 1 MCU_5V, 2 GND, 3 LOGIC_3V3, 4 ACT_3V2, keyed pin-for-pin. Never connect raw battery to main. Power TP3 BAT_NEG is NOT TP4 GND. Charger USB has no data. Do not combine ESP32 USB power and main external rails until exact-module backfeed is qualified. Firmware and Wi-Fi game uploads are not implemented by this hardware release.

Read P4_REVIEW_AND_TEST.md before powering. Use current-limited equipment; charging tests need a sink-capable battery emulator or a qualified cell/NTC. Actual simultaneous loads, thermal behavior, rail sequencing, USB behavior, protection, speaker rating and physical/RF fit remain untested. The 3.3 V screening target is 0.4 A versus the older main 0.5 A reservation; measure demand and margin. No real cell is selected. No toy-safety or EMC certification is claimed.

RELEASE_VERIFICATION.json binds source CAD, fresh reports and fabrication outputs. SHA256_MANIFEST.json inventories all package files except itself. This package is for review, not an order; no factory submission or purchase has been made.

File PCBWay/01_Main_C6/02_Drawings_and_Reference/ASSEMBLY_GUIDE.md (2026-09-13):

# Main C.6 — prototype assembly and wiring

Use ONLY C.6 CAD/BOM/Gerbers with P.4 power. Main is 96 x 105 x 1.6 mm/R4; power is 50 x 50 x 1.6 mm/R3. Both have four 2.2 mm holes, but their mounting patterns DO NOT match. Main is two-layer through-hole student assembly; power is a separately factory-assembled four-layer SMT board. These five samples are for adult-supervised engineering qualification, not finished toys.

## Flat parts and assembly order

1. Dry-fit the actual socketed ESP32, landscape screen, SD module, RGB, switches and plugged JSTs on the actual-size drawings. Print at 100% and measure the calibration line. Seller module revisions and socket retention remain unqualified.
2. Fit ALL R1-R43 horizontally, 10.16 mm pitch. No upright resistors. Fit flat axial D2, ceramic capacitors and empty DIP sockets; verify values before soldering.
3. Form Q1-Q6 to the flat-body outlines, marked flat face up, preserving numbered leads; support leads near the body. Do not swap Q6 LP0701N3-G for BC327.
4. Mount C1/C3/C5/C13/C17/C25 (ECEA1CKA101, 100uF/16V) and C9/C11/C15/C21 (ECEA1CKA100, 10uF/16V) horizontally on 0.5 mm insulating support. Maximum heights including support are 7.3 and 5.0 mm respectively. Full maximum can length is 8 mm. Pad1 positive, striped negative lead pad2. The 10uF part's native 1.5 mm leads must be formed to 2.54 mm; 100uF uses 2.5 mm. Support at the seal; do not cross, twist or pull leads or block the pressure vent.
5. Fit rear JSTs/module sockets, IR emitter D1 and receiver U2 facing the top case window, then front screen/RGB sockets and nine soft switches. Tack one pin and check alignment before completing. IR optics, buttons, connectors and sockets retain functional height; do not flatten them.
6. Trim solder tails to <=2.5 mm and inspect both sides before inserting modules/chips. Debug holes are bare probe points, not tall headers beneath opposite-side parts. Support the display's free edge mechanically.
7. Mount the smaller power board behind main on independent removable case supports, not shared four-hole standoffs. Keep the power PCB, cell, wires and hardware clear of the main antenna. Main display/buttons face the user; final power orientation and board spacing need a mock-up with plugged connectors and wire bends. Main ESP32 rear envelope is about 15.3 mm; front RGB remains about 22.1 mm. Battery, fastener lengths and case depth are not frozen.

Keep the marked antenna region free of metal, battery, hardware and loose wiring. Unscrew/unplug the power board for access to main-board solder joints and sockets. Use insulating barriers and strain relief; do not press a cell against solder tails.

## Parts whose orientation matters

| Part | Required orientation / pin function |
|---|---|
| Q1, Q2 — KSP2222ABU | Pins 1 E, 2 B, 3 C. Match the TO-92 flat face in the assembly drawing. |
| Q3 — BC32725BU | Pins 1 C, 2 B, 3 E. Not interchangeable with Q1/Q2. |
| Q4, Q5 — TN0702N3-G | Pins 1 S, 2 G, 3 D. ESD-sensitive. |
| Q6 — LP0701N3-G | Pins 1 S, 2 G, 3 D. **Pin 1 is ACT_3V2; pin 3 is switched amplifier supply. Do not fit the former BC327.** |
| U1 — MCP23017-E/SP | Pin 1/notch matches the narrow ED281DT socket drawing. |
| U3 — TDA2822L-D08-T | Pin 1/notch matches the ED08DT socket. Neither speaker output is ground. |
| U4 — TLC5916IN | Back-side ED16DT socket; match notch/pin-1 dot, not an unmirrored front view. Pin 1 GND; pin 16 3.3 V. |
| D3 — WP154A4SEJ3VBDZGW/CA | Front, in PPTC041LFBN-RC socket: 1 red cathode, 2 common anode (+5 V), 3 blue cathode, 4 green cathode. Form native 1.27 mm leads to the footprint's 2.54 mm pitch using a fixture; support leads near the body. Dry-fit a sample without forcing it. |
| Polarized capacitors | Pad 1 positive, pad 2 negative. C21 positive goes to U3 pin 8; its negative goes to pin 5, not ground. |
| D2 — 1N5819 | Banded cathode at pad 1 / ACT_3V2; anode at pad 2 / motor return. |
| D1 — TSAL6200 | Pad 1 cathode; pad 2 anode. Confirm lead/flat markings against the drawing. |
| U2 — TSOP38238 | Pins 1 OUT, 2 GND, 3 VS; lens faces the direction in the assembly drawing. |
| Buttons | A/B are one internally connected pair; C/D are the other. Confirm a sample with a continuity meter. |

## Connectors and harnesses

Read pin numbers on the PCB/assembly drawing, not left/right from a cable photograph. Verify each finished harness with a continuity meter; wire color is only a secondary aid.

| Connector | Pinout | Mating parts |
|---|---|---|
| J1 — SYS_IN | 1 MCU_5V; 2 GND; 3 LOGIC_3V3; 4 ACT_3V2 | XHP-4 housing + 4 SXH-001T-P0.6 contacts |
| J2 — screen | 1 GND; 2 3.3V; 3 SCK; 4 MOSI; 5 RESET; 6 DC; 7 CS; 8 BLK | Already-counted PPTC081LFBN-RC female socket; module's male strip |
| J3 — SD | 1 3.3V; 2 CS; 3 MOSI; 4 SCK; 5 MISO; 6 GND | Already-counted PPTC061LFBN-RC female socket; module's male strip |
| J4 — MOTOR | 1 ACT_3V2; 2 switched motor return | PHR-2 + 2 SPH-002T-P0.5S contacts on added 24-AWG pigtails |
| J5 — SPK | 1 amplifier OUT1; 2 amplifier OUT2 | PHR-2 + 2 SPH-002T-P0.5S contacts on added 24-AWG pigtails |

Use Alpha 3050 stranded 24-AWG cut stock for the added pigtails and J1 lead. Its nominal insulation OD is 1.42 mm, within the selected PH and XH contact ranges. Have a qualified assembler make the crimps and pull-test them. **The motor's fine AWG32 wires must not be crimped into those larger pigtail terminals.** The prototype harness instead uses short, individually insulated splices between the supplied actuator leads and the pigtails. Verify sleeve coverage over each joint and insulation at both ends; provide separate strain relief so no pull reaches motor/speaker terminals. Never tin wire before crimping or use solder as a substitute for a sound crimp.

Label both ends of J4's harness MOTOR and both ends of J5's SPK. Their keyed connectors are physically interchangeable, which is an assembly hazard. Neither the motor return nor either speaker terminal should be assumed to be ground. The 150 mm cut lengths are a bench allowance; both power J3 and main J1 now use XHP-4 housings. Use eight XH contacts for the complete pin-for-pin harness; final lengths depend on the shell.

## Unpowered inspection

- Confirm resistance checks show no persistent short between GND and any of the three supply rails; capacitor charging can cause a brief meter indication. Check no cross-rail short, especially the isolated MCU-module 3V3 output.
- Check J1 pin numbering against the actual plug. Check Q6 source and drain by continuity to ACT_3V2 and U3 pin 2 respectively.
- Verify all module header pins align, no row is offset by one position, and the MCU 3V3 pin is intentionally not tied to the external 3.3 V rail.
- Check J5 only connects to U3 outputs 1 and 3. Do not attach a grounded oscilloscope probe clip to either speaker pin; use differential measurement or two grounded channels with mathematical subtraction.

## First power and integrated testing

Read the accompanying P4_REVIEW_AND_TEST.md before connecting anything. First qualify the power board alone with current-limited equipment and dummy loads; battery selection remains open. Main J1 is NOT a raw battery input. Do not combine ESP32 USB power and external SYS_IN until exact-module backfeed behavior is proven. Program the removable MCU separately for recovery; Wi-Fi app/game loading requires firmware not provided here.

Power J3 -> main J1: 1 MCU_5V, 2 GND, 3 LOGIC_3V3, 4 ACT_3V2, pin-for-pin. The charger USB-C carries no data to main. Do not assume the two physically compatible speaker/motor plugs are interchangeable electrically.

P.4 screening load targets are 5 V/0.6 A, 3.3 V/0.4 A and 3.2 V/0.5 A; none is a measured rating. Older main-board reservations included 0.5 A on 3.3 V and additional RGB allowance. Those reservations were estimates, not measurements: the integrated peak budget remains an explicit bench qualification item. Do not silently treat a 0.4 A screening result as proof of a 0.5 A logic requirement. Test combined Wi-Fi, SD, RGB, IR, audio and motor peaks and adjust the design if capacity is insufficient.

Start with socketed loads and actuators disconnected. Check short circuits, pin polarity, rail nominal values, disabled amplifier/motor and unexpected current. Power OFF before changing connections. Scope rail rise/fall and GPIO back-powering before attaching all logic. Increase current limits only as justified by measured startup; stop for heat, oscillation or incorrect rails. R23 stays 100 ohm until the exact display backlight current is measured. Test motor short pulses without stalling, then audio at low volume; neither speaker output is ground. Record results for each sample.

## Firmware requirements and audio qualification

- MCP23017 address is 0x20. Set output latches to safe states **before** enabling their output directions: GPB4 AMP_EN low, GPB5 MOTOR_EN low, GPB6 display reset as required; GPA7 RGB_OE_N high. Do not configure GPA7/GPB7 as button inputs.
- Audio enable remains active-high. Q5/Q6 now use MOSFET gate drive, reducing calculated steady switch-control current to about 65 microamps. It does not eliminate amplifier quiescent current while enabled.
- Initialize PWM to its midscale silence duty, allow settling, then enable the amplifier and fade in. Fade out before disabling. Test startup/shutdown pops and residual differential DC with the actual speaker. Do not assume a pin at static zero gives pop-free playback through the AC-coupled filter.
- The passive-filter calculation used a 200 kHz PWM carrier, not an arbitrary lower carrier. Confirm achievable PWM resolution, carrier rejection and audible noise on hardware. Start at no more than 50% waveform amplitude; a firmware percentage is not a certified speaker power limit.
- Check U3 supply at audio peaks, Q6 voltage drop/temperature, and C25 charging inrush. LP0701's 2-ohm maximum cited at VGS=-3 V and 150 mA is a 25°C datasheet test point, not a guarantee at every temperature or arbitrary current. The present switch has no dedicated inrush controller.
- The exact FS1511P08-H3.0 continuous-power rating is not documented. Obtain the supplier rating or qualify a documented replacement before setting a production volume limit. Do not infer it from a similar model's datasheet.
- SD: format the selected 32 GB card FAT32; start with conservative SPI clocks and qualify higher speeds while the display is active. Commit saves safely, close files, and test interrupted writes/recovery. SD storage is not executable RAM and does not implement app loading by itself.
- Validate Wi-Fi uploads/trading and RF range with the final shell, display and battery placement. Keep a recovery programming path through the removable MCU.

## Prototype acceptance record

Record serial number, module markings, rail currents/voltages, button results, display/backlight current, SD write/read checksum, Wi-Fi transfer/range, IR transmit/receive, motor startup, audio noise/clipping/DC/pops, and temperatures. Test cold starts and repeated power cycles before unattended operation. Bench qualification, safe power-module integration, enclosure retention/drop testing and applicable toy/EMC compliance are prerequisites for any student/product release; a clean PCB DRC does not perform those tests.

## RGB wiring and safe firmware initialization

U1 GPA4 → U4 SDI (pin 2), GPA5 → CLK (3), GPA6 → LE (4), GPA7 → OE_N (13). U4 OUT0 (5) drives D3 red, OUT1 (6) green, OUT2 (7) blue; OUT3–7 and SDO are unused. The common anode is 5 V; logic is 3.3 V. Do not drive the LED directly from MCP23017 pins.

1. Preserve button states/directions and all unrelated expander bits. Write GPA7 high and GPA4–6 low to the output latch before making GPA4–7 outputs. R41 blanks OE_N at boot; R42/R43 define SDI/CLK, and LE has the driver's internal pull-down.
2. In normal mode, keep LE low, shift eight zero bits into SDI on CLK rising edges, then pulse LE high and return it low with CLK stationary. Keep OE_N high throughout initialization, then lower it to display the latched value. Do not unintentionally clock the special-mode OE/LE entry sequence.
3. For normal eight-bit writes, shift bit 7 first; bit 0 controls OUT0/red, bit 1 OUT1/green, bit 2 OUT2/blue. Latch after each complete byte. Always keep bits 3–7 zero. Verify red/green/blue individually at first startup before displaying mixed colors.
4. R40=1.8 kΩ sets nominal default channel current around 10.4 mA (about 31 mA total for white). Confirm actual current and LED/driver temperature. The TLC5916 supports global current-gain adjustment and a low-current range; this is not independent hardware PWM for each color. Basic seven-color states are available; smooth per-color fades need additional firmware timing design. Color balance is not calibrated.
5. Verify cold start, processor reset and expander reset produce no unintended light; verify commanded OFF and sleep current. Probe U4 pin 16 (3.3 V), D3 pin 2 (5 V), R40 and U4 control pins with insulated fine probes and power off before attaching clips. Never short adjacent DIP pins.

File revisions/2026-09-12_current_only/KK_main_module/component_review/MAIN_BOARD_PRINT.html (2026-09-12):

# Keychain Kreatures — main-board review checklist

2026-09-10 — main-board review checklist, not a final purchasing/bagging list. Charging, battery protection and ALL added voltage regulation, including the motor regulator, belong to the separate power board. MCU, display and SD reader are permitted preassembled modules with THT student connections. Local bypass capacitors and actuator drivers remain on the main PCB. No hardware has been ordered or fabricated.

Use your browser Print command (Ctrl+P); layout is set for landscape A4. This is a review list, not a fabrication release.

Per-toy quantities. Starter counts are subtotals; TBD counts and candidate values are not a final purchase list. Do not double-count bundled headers.

Item | Exact part / candidate | Quantity | Status
CORE | ESP32-S3 SuperMini / original Amazon B0D47HBFDY | 1 | User-selected module family; exact revision check
DISPLAY | B0DFWL25RB | 1 | User-selected; interface HOLD
GPIO | MCP23017-E/SP | 1 | Design baseline
CONTROLS | 3101 | 9 | Design baseline; mechanical check
AUDIO | TDA2822L-D08-T | 1 | Design baseline
SPEAKER | FS1511P08-H3.0 wired | 1 | HOLD drawing and power rating
HAPTIC | LCM0827A3038F | 1 | Design baseline; drive qualification
IR_TX | TSAL6200 | 1 | Design baseline
IR_RX | TSOP38238 | 1 | Design baseline
NPN_DRIVER | KSP2222ABU | TBD total; 1 in starter circuit | Design baseline; quantity/calculation pending
PNP_SWITCH | BC32725BU | TBD | Peripheral candidate only
FLYBACK | 1N5819-E3/54 | 1 minimum | Design baseline; total TBD
MCU_SOCKET | PPTC091LFBN-RC | 2 | Design baseline; SuperMini fit check
MCU_HEADER | 9-pin male strips supplied with selected module | 2 strips if not factory-fitted | Bundle contents / fit verification
GPIO_SOCKET | ED281DT | 1 | Design baseline
AUDIO_SOCKET | ED08DT | 1 | Design baseline
DISPLAY_SOCKET | PPTC081LFBN-RC | 1 | Design baseline; screen-dependent
ACTUATOR_CONNECTOR | S2B-PH-K-S(LF)(SN) | 2 | Design baseline
ACTUATOR_HOUSING | PHR-2 | 2 | Design baseline
MOTOR_CONTACT | SPH-004T-P0.5S | 2 | Candidate; insulation check
RESISTOR | MFR-25FBF52-4R7 | TBD | Value pool; not a bag count
RESISTOR | MFR-25FBF52-39R | TBD | Value pool; not a bag count
RESISTOR | MFR-25FBF52-100R | TBD total; 2 in starter circuit | Value pool; not a bag count
RESISTOR | MFR-25FBF52-220R | TBD total; 1 in starter circuit | Value pool; not a bag count
RESISTOR | MFR-25FBF52-680R | TBD | Value pool; not a bag count
RESISTOR | MFR-25FBF52-1K | TBD | Value pool; not a bag count
RESISTOR | MFR-25FBF52-4K7 | TBD total; 2 in starter circuit | Value pool; not a bag count
RESISTOR | MFR-25FBF52-10K | TBD total; 11 in starter circuit | Value pool; not a bag count
RESISTOR | MFR-25FBF52-100K | TBD total; 1 in starter circuit | Value pool; not a bag count
CAPACITOR | C315C104K5R5TA | TBD total; 3 in starter circuit | Value pool
CAPACITOR | C315C103J1G5TA | TBD | Value pool
CAPACITOR | C315C105K5R5TA | TBD | Value pool
CAPACITOR | UVR1C100MDD | TBD total; 2 in starter circuit | Value pool
CAPACITOR | UVR1C101MDD | TBD | Value pool
SD_MODULE | Amazon B0F82XWT4F | 1 | User-selected; 3V3 and signal labels confirmed in photo; sample test pending
SD_SOCKET | PPTC061LFBN-RC | 1 proposed | Series candidate; delivered pitch / stack-height check
SD_HEADER | Six-pin male strip pictured with B0F82XWT4F | 1 strip included if supplied | Bundle contents / fit verification
BACKLIGHT_DRIVER | Backlight control and default-off network | TBD | HOLD — display sample
AUDIO_NETWORK | PWM filter / attenuation / coupling / bridge stability | TBD | HOLD — calculations
AUDIO_GATE | Amplifier supply gating network | TBD | HOLD — calculations
MOTOR_NETWORK | Motor drive / suppression | TBD | HOLD — startup and stall
SPEAKER_CONTACT | Speaker harness crimp contacts | 2 | HOLD — wire gauge
MAIN_PCB | KK main-board custom PCB | 1 | Design pending
TEST_ACCESS | PCB test pads and optional service header | TBD pads | Design pending
SCREEN_RETENTION | Display retention hardware / spacers | 1 set | Mechanical design pending
PCB_HARDWARE | PCB spacers and fasteners | TBD | Mechanical design pending
ACTUATOR_MOUNT | Speaker gasket and motor retention | 1 set | Mechanical design pending
MICROSD | microSD card; exact brand/capacity pending | 1 | Storage now included; card selection pending
SYS_IN_CONNECTOR | Keyed THT regulated-power input connector | 1 | Interface selection pending
SYS_IN_HARNESS | Power-board to main-board harness and mating contacts | 1 set | Interface selection pending
MAIN_RAIL_INTERFACE | Main-board rail distribution / local bypass capacitors | TBD | Main-board engineering pending
SD_SUPPORT | SD supply bypass / bus pull-ups / optional series resistors | TBD | Circuit inspection pending
SD_RETENTION | Reader support and display clearance / insulation | 1 set if needed | Mechanical design pending

## Remaining work

Before final release: (1) verify SuperMini pinout and fit, display/backlight interface and SD socket stack; (2) select a documented speaker, exact microSD card and remaining harness/mating parts; (3) finish GPIO allocation and audio/motor/SD circuits, then count every resistor/capacitor/driver; (4) agree incoming regulated rails and connector pinout with the power board. Only its interface is needed now, not the completed charger design. Enclosure/battery/packaging are outside this main-board print view and remain in the master kit register. No ERC or prototype qualification has been completed.

Full notes and datasheets: MASTER_BOM.md.

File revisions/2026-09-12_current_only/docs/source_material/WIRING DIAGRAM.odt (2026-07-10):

# Keychain Kreatures — Updated Wiring Diagram

## 🖥️ 1.69" ST7789 Display

ST7789 Pin | ESP32-C3 Super Mini
GND | GND
VCC | 3V3
BLK | 3V3
SCL | GPIO4
SDA | GPIO6
RES | GPIO7
DC | GPIO2
CS | GPIO10

## 🔊 MAX98357A I²S Audio Amplifier

MAX98357A Pin | Connect To
VIN | 3.3V
GND | GND
DIN | GPIO20
BCLK | GPIO21
LRC / WS | GPIO0
SD | GPIO5
GAIN | Not connected

## 🎮 PCF8574 I/O Expander

PCF8574 Pin | ESP32-C3 Super Mini
VCC | 3.3V
GND | GND
SDA | GPIO8
SCL | GPIO9

## 🎮 Button Wiring

Each button should connect between its assigned PCF8574 pin and GND.

Button | PCF8574 Pin
UP | P0
DOWN | P1
LEFT | P2
RIGHT | P3
A | P4
B | P5
Spare / future button | P6
IR Receiver OUT | P7

## 📡 IR Transmitter

IR Transmitter Pin | Connect To
VCC | 3.3V
GND | GND
DATA | GPIO1

## 📡 IR Receiver

IR Receiver Pin | Connect To
VCC | 3.3V
GND | GND
OUT | PCF8574 P7

## 📳 Vibration Module

Vibration Module Pin | Connect To
GND | GND
VCC | 3V3
IN | GPIO3

## 🔋 Battery and Charger Wiring

### Battery to Charger

Battery Wire | Charger Pin
Battery + | B+
Battery - | B-

### Charger Output to Device

Charger Pin | Connect To
OUT+ | Device power input / regulator input
OUT- | GND

The charger output is usually the battery voltage, roughly 3.0V to 4.2V, unless your charger board includes a boost converter.

## 🔘 On/Off Switch

For a 3-pin switch:

Switch Pin | Connect To
Pin 1 | Charger OUT+
Pin 2 — Common | Device power input
Pin 3 | Leave unconnected

### Correct power path

Battery + → Charger B+

Battery - → Charger B-

Charger OUT+ → Switch Pin 1

Switch Pin 2 → Device power input

Charger OUT- → Device GND

Switch Pin 3 → Not connected

## 📋 Complete ESP32-C3 GPIO Map

GPIO | Function
GPIO0 | MAX98357A LRC / WS
GPIO1 | IR Transmitter DATA
GPIO2 | ST7789 DC
GPIO3 | Vibration Module IN
GPIO4 | ST7789 SCL
GPIO5 | MAX98357A SD
GPIO6 | ST7789 SDA
GPIO7 | ST7789 RESET
GPIO8 | PCF8574 SDA
GPIO9 | PCF8574 SCL
GPIO10 | ST7789 CS
GPIO20 | MAX98357A DIN
GPIO21 | MAX98357A BCLK

## 📋 Complete PCF8574 Map

PCF8574 Pin | Function
P0 | UP
P1 | DOWN
P2 | LEFT
P3 | RIGHT
P4 | A
P5 | B
P6 | Spare
P7 | IR Receiver OUT

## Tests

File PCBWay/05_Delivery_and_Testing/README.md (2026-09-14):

# Delivery, inspection and first tests

Before shipment, request the agreed bare-board electrical-test results and power assembly inspection/hidden-joint reports. Save them under Inspection_Reports. Shipping dates and tracking are not yet known.

On arrival: photograph and label all five samples of each board; inspect without power; compare outlines, mounting holes and connectors to the current drawings. Use the included main/power troubleshooting PDFs and blank records. PCBWay assembly does not mean the circuit has already passed our functional tests.

Test power independently before connecting the populated main board. Follow P4_REVIEW_AND_TEST.md and the instructor-level power guide. Do not connect an unspecified battery. BAT_NEG is not system GND; do not bypass protection with grounded equipment. Charging tests need suitable sink-capable equipment or a qualified cell/NTC, not an ordinary bench supply used as a battery.

No diagnostic/production firmware is supplied or claimed implemented. If PCBWay asks for firmware or a functional fixture, agree that separate scope first; do not upload historical incompatible code.

KIT_EXTRAS_FOR_LOCAL_BUILD.csv is reference for assembling complete pairs locally, NOT an additional power-board sourcing BOM. Count extras once per main+power pair; unresolved battery/mechanical selections remain open. Use FACTORY_FAULT_REPORT.pdf for issues.

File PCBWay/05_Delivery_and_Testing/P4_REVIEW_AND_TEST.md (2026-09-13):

# P.4 power — five-sample engineering review and first-power-up

Current board: **50 x 50 x 1.6 mm**, R3 corners, four layers. Four 2.2 mm M2 holes at (3,3), (47,3), (3,47), (47,47) mm. Main C.6 remains 96 x 105 mm: the holes DO NOT match. Use separate removable case supports. This package is for prototype DFM review; factory process/parts approval and physical/bench qualification remain required. Not a finished student product.

P.4 restores the original compact routed geometry from P.2 while retaining the repaired P.3 3D assets. Relative to P.3, every electrical pad/net/track/via is rigidly transformed by x=51-old_x, y=104-old_y (180 degrees, same layers). Outline and mounting holes are restored to 50 x 50 mm/R3; the oversized-board antenna keepout is removed. The complete compact board must instead be positioned clear of the main antenna. The wide 1.5 mm SYS_SW bridge on In1 and 0.6 mm C8 feed remain. In1 is NOT an uninterrupted ground plane. There are 3,515 track segments, 260 vias, 108 fitted parts and 28 rear bare test pads.

All current coordinates come from the P.4 native PCB. In its native front view USB is at the top edge, the switch at the right edge and the harness connectors toward the bottom. Final case placement and orientation behind the main board are not frozen. Use independent supports; the old shared 20 mm four-standoff stack is superseded. Keep the entire power PCB, battery, harness and hardware clear of the main antenna region. Verify actual plugged JSTs, cable overmolds, wire bends and access to test pads. Clip solder tails to <=2.5 mm, inspect the joints and use insulating barriers. Cell position and board spacing still require a physical mock-up.

TP4 is system GND. TP3 is BAT_NEG, NOT GND. Never bypass battery protection by shorting those returns with grounded test equipment. Use the current P.4 TEST_POINTS.csv rather than old revision coordinates.

The included electrical screening was inherited unchanged from P.2 because the circuit did not change. Its calculations are not new measurements or qualified output ratings. Main's older 3.3 V reservation was 0.5 A while this screening target is 0.4 A: reconcile the actual integrated load with bench measurements before approving product use.

## Electrical review and limits

| Function | Reviewed design | Qualification still needed |
|---|---|---|
| Battery charging | BQ24075**T**RGTR; about 0.303 A nominal charge current, screened 0.271–0.332 A | Selected cell's charge limit, thermal rise, charge termination, source/load interaction |
| Temperature interlock | Semitec 103AT-2, 10 kΩ, with R74/R75 bias network; nominal thresholds about 4.8°C and 40.0°C; open/short inhibits charging | Bonded thermistor thermal lag and actual pack limits; screened corners extend roughly 2.9–42.2°C |
| USB-C input | TUSB320LAI GPIO sink detects advertised current; dedicated 3.3 V CC supply; high-current mode only for adequate advertisement | Attach/unplug transients, weak chargers, cable behavior, total input current |
| USB-A/default input | TPS22950**YBHR**, base variant, nominal 50 mA limiter; datasheet range approximately 34–66 mA, plus upstream loads | Startup and host behavior. No USB enumeration, suspend detection or BC1.2; not a claim of universal USB compliance |
| USB-C charge-path limit | BQ24075T programmed around 1.23 A, screened maximum about 1.32 A | Full toy load plus charging may exceed input budget; the battery may supplement |
| Battery protection | DW01A, three parallel FS8205 dual-FET banks, 4 A fuse; separate protected return | Pack, fuse and protection-trip coordination; short-circuit recovery and FET heating |
| System cutoff | TPS259530, nominal approximately 3.27 A limit; SYS_RAW UVLO about 3.38 V rising / 3.10 V falling | Threshold tolerance, loaded battery sag, startup and hysteresis |
| Rails | TPS63060 converters: MCU_5V, LOGIC_3V3 and ACT_3V2; output gates and independent voltage supervision | Regulation, ripple, startup/stop sequencing, transients and thermal margin into the actual toy |

The calculation sheet is a screening exercise, not a simulation or measurement. Working load targets are 5 V at 0.6 A, 3.3 V at 0.4 A and 3.2 V at 0.5 A (5.92 W combined). These are **not validated output ratings**. At low battery voltage the combined load can require roughly 2.5 A; test the complete current path, not just each converter separately. Confirm effective ceramic capacitance under DC bias and the board house's actual copper stackup.

The independent voltage monitor is retained: a converter's power-good behavior is not a substitute for verifying all three output voltages. Equal output-gate timing capacitors do not prove safe sequencing between the ESP32 module's onboard regulator and the external logic rail. Scope startup/shutdown and measure GPIO back-powering before attaching a populated main board. Exact SuperMini module revisions may differ.

Manufacturer references: [BQ24075T](https://www.ti.com/lit/ds/symlink/bq24075t.pdf), [TUSB320LAI](https://www.ti.com/lit/ds/symlink/tusb320lai.pdf), [TPS22950](https://www.ti.com/lit/ds/symlink/tps22950.pdf), [TPS63060](https://www.ti.com/lit/ds/symlink/tps63060.pdf). Other selected manufacturer datasheets are retained with the CAD project and linked in the BOM. Availability, permitted substitutions and assembler inventory are not yet approved.

## Connector and assembly instructions

| Connector | Pin assignments | Important restriction |
|---|---|---|
| J1 USB-C | Charging input only; data/SBU pins deliberately NC | Does not communicate with the ESP32 |
| J2 battery, JST VH 2-pin | 1 CELL_PLUS; 2 BAT_NEG | **BAT_NEG is not system GND. Never bypass the low-side protection by bonding them externally.** |
| J3 to main-board J1, JST XH 4-pin | 1 MCU_5V; 2 GND; 3 LOGIC_3V3; 4 ACT_3V2 | Wire pin-for-pin. Use current CONNECTOR_PIN_MAP.csv and pad numbers; do not infer order from an old or mirrored drawing |
| J4 thermistor, JST PH 2-pin | 1 NTC; 2 GND | Bond and electrically insulate the thermistor against the cell; do not substitute a fixed resistor for normal use |

Use the native assembly drawings, reference designators and pad-1 marks. The placement CSV explicitly uses board coordinates with Y increasing downward; it is a reference table, **not an unreviewed machine-ready centroid conversion**. Have the assembler verify rotation and polarity for every IC, FET, diode, connector and switch against its actual reel/part drawing. Bare TP pads and mounting holes are not fitted parts. All fitted electrical components are on the front; test pads are on the rear. The power board is factory SMT assembled, not a student through-hole soldering exercise.

`BOM_AND_PLACEMENT.csv` uses the down-positive CAD coordinates described above. `POSITIONS_NATIVE.csv` is KiCad's native mm placement export (Y values are negative for this board origin); do not mix these coordinate conventions. Both include all 108 fitted parts. THT/mixed connector and switch operations need separate assembler handling. Drawings separate silkscreen labels from component-body/fab references to avoid double-printed text; bottom assembly views are mirrored for viewing from the back. Copper-layer drawings are viewed from the front.

Suggested mating hardware for each power-to-main harness: two JST XHP-4 housings and eight SXH-001T-P0.6 contacts with Alpha 3050 24 AWG stranded wire for this prototype harness (same as main kit list). Battery mating housing VHR-2N with two SVH-21T-P1.1 contacts and 20 AWG wire, subject to the selected battery's connector/polarity and insulation diameter. Thermistor mating housing PHR-2 with two SPH-002T-P0.5S contacts and suitable 28 AWG insulated leads. Check the current JST terminal drawing, crimp tooling, wire and insulation ranges before assembly. Matching pitch alone is not sufficient; do not mate unrelated connector families.

Battery selection is still open: conventional **1S, 4.2 V maximum** Li-ion/LiPo, provisionally at least 4 A continuous discharge capability and at least 0.34 A permitted charging, with documented temperature limits. Capacity, physical fit and protection coordination must be finalized before testing a real cell. The board does not establish safe reverse-battery behavior; verify the harness polarity before connecting it. Shell, mounting screw lengths and standoffs require physical fit checks. A 3D rendering is not dimensional certification; all 108 fitted model links resolve, but connector mating volumes and seller modules still need physical checks.

## Fabrication/assembly acceptance gate

Request **five engineering samples**, four copper layers, 50 × 50 mm, 1.6 mm nominal thickness, R3 corners and four 2.2 mm M2 clearance holes. Confirm layer order F.Cu / In1.Cu / In2.Cu / B.Cu, finished copper weights, drill plating and soldermask registration with the manufacturer. The CAD rules permit 0.15 mm traces and 0.20 mm drilled vias; some package clearances are fine-pitch exceptions to wider routing clearances.

The TPS22950 YBH footprint is a 0.4 mm-pitch six-ball WCSP with approximately 0.2 mm pads. Other small packages include 0.4/0.5 mm-pitch QFNs. **Do not substitute TPS22950C/L or another package without reviewing both behavior and footprint.** The selected base device supports the low USB-A current-limit setting.

The board has vias in surface-mount pads, including small parts and thermal pads. The accompanying CAD audit lists them. Ask for **filled, capped, planarized via-in-pad construction**, appropriate fine-pitch finish/stencil processing and assembler approval of the WCSP. Simple via tenting is not equivalent. Confirm whether X-ray inspection is available for hidden joints. If these processes exceed the five-board budget, stop before ordering: relocating vias or changing the current-limiter package is a layout/circuit revision, not a fabrication checkbox.

Ask the assembler to approve the BOM, substitutions, stencil apertures, centroid conversion, polarity and THT secondary operations. Do not send an old FACTORY.zip or a two-layer stackup. The current package is a DFM/engineering review package, not authorization for unreviewed substitutions or mass production.

## Current-limited first-power-up

1. Inspect under magnification before power. Verify IC orientation, hidden-joint inspection results, polarity, solder bridges and connector pin numbering. Check rail-to-ground resistance and confirm BAT_NEG is not accidentally hard-bonded to GND. Investigate unexpected readings rather than assuming a universal resistance threshold.
2. Keep the real cell and main board disconnected. Use a current-limited battery simulator at J2, positive to pin 1 and negative to pin 2. Begin at 3.7 V with the toy switched off and a low current limit (about 50 mA); verify expected idle behavior before increasing the limit. Protection may need its documented recovery sequence; do not bypass it.
3. Switch on with an appropriate bounded current limit. Measure all three J3 outputs before attaching loads. Target nominal 5.0/3.3/3.2 V; investigate deviations beyond ±5%, and reject actuator transients above the attached components' maximum (3.3 V target ceiling for this design). Measure ripple and overshoot with short probe grounds. A current limit that is too low can itself cause startup cycling.
4. Increase dummy loads gradually, first separately and then together toward the screening targets. Record input current, rail voltage, ripple and converter/charger/FET/fuse temperatures at high and low battery voltage. Test UVLO and recovery using the simulator; never deliberately overdischarge a real cell.
5. For charging tests with USB attached, use a **sink-capable/bidirectional battery emulator** or a qualified cell with its bonded NTC. An ordinary bench supply usually cannot absorb charging current and must not be used as a battery substitute while the charger is active.
6. Check USB-A/default input limit, USB-C default/1.5 A/3 A advertisements, attach/unplug, weak-source behavior and absence of damaging reverse feed. Confirm the default path does not request high current. Measure upstream CC/LED current as well as the limiter current. This does not establish USB certification.
7. Verify charging current, termination, NTC open/short inhibition and measured temperature thresholds using controlled test equipment. Check low-battery cutoff, current-limit behavior and recovery with a current-limited simulator, not uncontrolled shorting of a cell.
8. Scope rail rise/fall ordering and GPIO leakage/back-power behavior using the actual ESP32 module and main-board load model before full connection. Then test Wi-Fi bursts, SD writes, motor starts, IR, RGB and audio together. Stop for overheating, oscillation, unexpected current or out-of-range voltages.
9. Do **not** connect the ESP32's USB power and external SYS_IN simultaneously until reverse-feed paths are qualified. Charging USB on the power board is separate and has no data path. Update firmware over Wi-Fi, or program the removable ESP32 with the main-board supply disconnected.

Record results for all five serial-numbered boards. Retain one as the comparison unit. Successful ERC/DRC and routing do not replace these measurements or toy/product safety and EMC review. Do not distribute the samples as finished student products.

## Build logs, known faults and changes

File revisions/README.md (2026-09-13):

# Historical revisions — do not manufacture from here

The [2026-09-11 cleanup archive](2026-09-11_cleanup/) preserves the original relative project paths. No archived design is the current project.

- `KK_power_module/`: legacy two-wire power board, P.1, previous backups, old fabrication outputs and original engineering scripts.
- `KK_power_module/P2_compact/`: abandoned P.2 routing candidates and intermediate board snapshots. These routes were not imported or qualified.
- `KK_main_module/`: superseded reports, BOMs, routing candidates, older schematic capture, backups and former archives.

The current projects remain outside this directory; open them through [START_HERE.md](../START_HERE.md).

## Current-only folder cleanup

[2026-09-12_current_only](2026-09-12_current_only/) holds the former C.5 main root, C5_relayout, P2_compact, old main assembly/component investigations, intermediate C.6 routes, historical documents and one-off generators. [MOVE_MANIFEST.json](2026-09-12_current_only/MOVE_MANIFEST.json) records each move and protected current CAD/ZIP hashes. Active C.6/P.3 now sit directly in their module folders.

Archived relative compatibility symlinks preserve their original text and may not resolve from their new archive location. Recover a historical project into a separate scratch tree using the manifest; do not copy it over current CAD. No material content was deleted.

## C.6 / P.3 release archive

[2026-09-12_C6_P3_release](2026-09-12_C6_P3_release/) preserves the superseded C.5/P.2 manufacturing directories, ZIPs and reports, plus the previous Desktop print sheet and the C.6/P.3 preflight ZIPs before final documentation cleanup. None of those ZIPs is the current release. [MOVE_MANIFEST.json](2026-09-12_C6_P3_release/MOVE_MANIFEST.json) distinguishes moves from preserved copies and records exact hashes. No baseline CAD was deleted or overwritten.

## Recovery

[MOVE_MANIFEST.json](2026-09-11_cleanup/MOVE_MANIFEST.json) records each original path, new path and per-file SHA-256 hash. Every move was verified. Active CAD/library/model hashes were checked separately to establish that cleanup did not modify them. Nothing was deleted.

For recovery, copy the desired archived files to a **separate scratch project**, preserving their recorded original relative paths. Include corresponding libraries/models and any generator inputs. Do not overwrite the current projects. Archived generation scripts retain original paths and are historical source, not working commands in their relocated tree. Never run them over current CAD.

The former compatibility symlinks at `KK_main_module/archive`, `KK_main_module/pcb/backups` and `KK_main_module/schematic` are now archived too. Historical reports may contain obsolete links; the move manifests, not the old links, are the recovery map.

The archive may contain packages named `FACTORY` or `release`. Those names are historical and do not approve them for the present main board, battery or product.

## Compact power P.4

See [2026-09-12_power_compact](2026-09-12_power_compact/) for the preserved P.3 projects, prior packages, source snapshots and promotion hash map. Current power is 50 × 50 mm with separate mounts; main C.6 remains unchanged.

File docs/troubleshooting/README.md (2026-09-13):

# Troubleshooting — start with the correct board

These guides are for first-time students and supervising instructors. Read from the beginning on the first attempt; use the symptom tables afterward. The power board is factory SMT; its live tests require a qualified instructor/technician.

| Board | Printable guide | Editable source | Recording sheets |
|---|---|---|---|
| Main C.6 | [Main PDF](../../KK_main_module/assembly/TROUBLESHOOTING_MAIN_C6.pdf) | [Markdown](../../KK_main_module/assembly/TROUBLESHOOTING_MAIN_C6.md) · [HTML](../../KK_main_module/assembly/TROUBLESHOOTING_MAIN_C6.html) | [Checklist](../../KK_main_module/assembly/TROUBLESHOOTING_C6_CHECKLIST.csv) · [Measurements](../../KK_main_module/assembly/TROUBLESHOOTING_C6_MEASUREMENTS.csv) |
| Power P.4 | [Power PDF](../../KK_power_module/assembly/TROUBLESHOOTING_POWER_P4.pdf) | [Markdown](../../KK_power_module/assembly/TROUBLESHOOTING_POWER_P4.md) · [HTML](../../KK_power_module/assembly/TROUBLESHOOTING_POWER_P4.html) | [Checklist](../../KK_power_module/assembly/TROUBLESHOOTING_P4_CHECKLIST.csv) · [Measurements](../../KK_power_module/assembly/TROUBLESHOOTING_P4_MEASUREMENTS.csv) |

[Factory fault-report PDF](FACTORY_FAULT_REPORT.pdf) · [Editable form](FACTORY_FAULT_REPORT.md) · [Guide/source verification](GUIDE_VERIFICATION.json)

[Download the complete troubleshooting packet](KK_C6_P4_TROUBLESHOOTING_PACKET.zip). It contains both guides, editable versions, worksheets and the factory form; unzip it and open the PDFs. The supporting schematic/datasheet links in PDFs point to the published hardware revision, so those links need internet access. The packet is not a replacement manufacturing package.

Print the PDFs double-sided if convenient. Keep one checklist and measurement sheet per serial-numbered board. Open CSVs in LibreOffice Calc or another spreadsheet editor; widen and wrap columns before printing. Retain blank templates. Record **PASS, FAIL, BLOCKED or NOT RUN**, along with the setup and evidence—not just a tick mark.

The main guide covers meter use, incoming/assembly state, harness/power, ESP32 isolation, buttons/I²C, display/backlight, SD, RGB, IR, motor, audio and integration. The power guide traces each stage and covers source/ground isolation, USB modes, charging/NTC, supervision/gating, loads, sequencing and factory escalation. Both include every released test pad and explicit stop conditions.

**A compatible diagnostic program is required for main functional tests and is not supplied by this hardware release.** Missing software is BLOCKED, not proof of a factory defect. Power itself needs no ESP32 firmware. No physical/powered tests were performed to create these guides.

Power TP3 is BAT_NEG; main TP3 is ACT_3V2. Never transfer a remembered pad number between boards. Do not bypass protection or connect ESP32 USB alongside external main power.

These are documentation supplements: CAD and issued manufacturing ZIPs remain unchanged. Printable source links refer to the published hardware commit used for verification. The older C.6 bench record in issued snapshots may mention P.3/shared mounting; use these C6/P4 troubleshooting worksheets for current tests. See [current release files](../CURRENT_RELEASE_INDEX.json).

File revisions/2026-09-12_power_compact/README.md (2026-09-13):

# Compact power revision — recovery map

Current projects are at the repository's KK_main_module and KK_power_module roots, not here.

- P4_candidate: preserved compact candidate and its original audit context, before promotion/export.
- P3_previous/KK_power_module: oversized P.3 source, supporting files and issued packages, unchanged.
- P3_previous/KK_main_module/manufacturing: previous issued C.6 packages, unchanged.
- P3_previous/instructions and P3_previous/docs: superseded instructions and shared-hole reports.
- PROMOTION.json: SHA-256 recovery map from original paths to preserved copies. Candidate audit status records its pre-promotion stage; current source-bound checks are in the active release package.

Old files are historical evidence, not current assembly instructions. Restore to a scratch directory, never over the active boards. The former matching-outline and 20 mm shared-standoff instructions no longer apply.

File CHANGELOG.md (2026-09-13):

# Release notes

## 2026-09-12 — compact P.4 power / unchanged C.6 main

- Restored power to 50 × 50 × 1.6 mm, R3 corners and its original four mounting holes. Main stays 96 × 105 mm/R4; separate case supports replace the shared-hole stack plan.
- Preserved the routed electrical core and repaired P.3 models. All electrical pad/net/track/via geometry matches the original compact core after rigid transformation; no circuit redesign or global autoroute.
- Archived the oversized P.3 source and previous issued packages intact. Current native projects are directly at the two module roots.
- Refreshed both manufacturing review packages, BOM/placement/maps, native checks, mechanical print sheet and assembly documentation. Main CAD and manufacturing geometry remain unchanged.
- Hardware is still an engineering prototype: factory DFM/process approval, physical fit, battery selection and bench qualification remain open. No order or production approval is implied.

Previous release notes are preserved in [the pre-promotion instructions](revisions/2026-09-12_power_compact/P3_previous/instructions/CHANGELOG.md).

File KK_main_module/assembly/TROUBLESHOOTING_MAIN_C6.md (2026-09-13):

# Main C.6 — student troubleshooting guide

For the 96 × 105 mm, two-layer Keychain Kreatures main board, paired with compact P.4 power. Guide version 1, 2026-09-12. Read in order on the first attempt; use the symptom table later.

**A board that does not work is a clue, not a student's failure.** Change one thing, measure again, and write down what changed. This guide describes tests to perform; it does not claim these prototypes have passed physical or powered testing.

## 1. Start here: what did the factory actually supply?

| What arrived | What it can do before assembly/programming |
|---|---|
| Bare main PCB | Nothing by itself. It needs its parts, socketed modules, power and software. |
| Populated main without ESP32/display/SD | Some power and wiring tests only; no game screen is expected. |
| Complete main with an unprogrammed or wrong-version ESP32 | It may look completely dead even with correct hardware. |
| Complete main with a verified C.6 diagnostic program | The functional tests below can begin, after the electrical checks. |

The hardware release does **not** include a validated C.6 diagnostic program or completed game/upload firmware. The instructor must supply and identify the correct test program. Record its version/hash. If none exists, mark software-dependent steps **BLOCKED — test firmware unavailable**, not FAIL. Do not install an old C3/MAX98357A/PCF8574 sketch on this S3/MCP23017/TDA2822L design.

A known-good comparison board means one that has actually passed these tests, not merely another untested factory sample.

## 2. Safety and who does what

**Students, with supervision:** identify parts, inspect unpowered boards, check a disconnected cable, record measurements, and operate an instructor-approved test setup. **Instructor only:** prepare power, attach live-test clips, change meter current ranges, use an oscilloscope, repair solder joints, program/recover modules, and approve replacement parts.

Stop immediately for smoke, unusual smell, a reversed connector, a swelling/leaking battery, sudden temperature rise or a supply repeatedly entering current limit. Switch off the bench supply and disconnect external power if safe. Do not touch a hot component or handle a damaged battery; alert the instructor and follow the lab's emergency procedure. Do not keep cycling power to see whether it improves.

- Never connect a battery directly to main J1. It needs **three regulated rails**, not a single battery voltage.
- Never attach ESP32 USB while external power is connected to main. For USB programming, remove the ESP32 from the unpowered board and use it alone.
- Power off and disconnect all sources before inserting/removing a module, SD card, chip, plug or meter clip. Verify the rails have fallen near 0 V; never discharge a capacitor with a screwdriver.
- Speaker J5 has **two driven outputs**. Neither is ground. Motor J4 pin 2 is also not a ground terminal.
- Do not bridge a pad with wire, replace a resistor with a short, bypass R23/R24, or increase a current limit to conceal a fault.
- Use a nonconductive bench mat and board holder. No metal rulers, loose screws or battery pouches beneath solder tails. Do not probe a handheld board.
- Protect your eyes during supervised soldering/lead clipping; use ventilation and wash hands afterward. Repairs must be inspected before power returns.

## 3. Your tools and a few useful words

Bring the board, this guide, the matching assembly drawing, a magnifier, a multimeter, insulated fine probes, and the instructor's verified power fixture. Functional testing also needs the identified test firmware, a spare test-only SD card, a known-compatible 38 kHz IR remote and a verified data USB cable. Scope/logic-analyzer work is instructor-only and uses voltage-compatible inputs.

| Word on the sheet | Meaning |
|---|---|
| J / U / R / C / Q / D / TP | Connector / integrated circuit / resistor / capacitor / transistor / diode or LED / test point. |
| Rail | A distributed power supply, such as LOGIC_3V3. |
| GND | The system's voltage reference. It is not automatically every metal part. |
| Open | A connection that should conduct but does not. |
| Short | An unintended low-resistance connection. |
| High / low | A digital signal near its logic supply / near ground. Not every signal uses 5 V. |
| `_N` | Usually active-low: the function is asserted when the signal is low. |
| PWM | Fast on/off pulses. A voltmeter shows an average, not the waveform. |

### How to use the meter without creating a fault

1. Black lead in **COM**; red lead in **V/Ω**, never the A/mA jack for these student checks.
2. For continuity or resistance: all power and USB disconnected; instructor confirms discharged rails. Touch probes together first and note the lead resistance/beep. Separate them and observe the open indication, often `OL`.
3. A brief beep across a supply capacitor may stop as it charges from the meter. Semiconductor paths can also conduct. Record settled readings and probe direction; a beep alone does not prove a short. Do not invent a universal resistance threshold.
4. For voltage: select DC volts and a suitable range above 5 V. The instructor attaches the black clip to **main TP4, TP6, TP8 or J1 pin 2** while power is off. Turn on, touch only the intended point with red, record the value, then switch off before moving clips.
5. Never place a meter in current mode across a power rail. Current measurement needs a correctly fused series connection prepared by the instructor; prefer the supply's current display initially.

## 4. M1 — photograph and inspect before power

Record main serial number, revision, supplier/lot, assembly date and the exact ESP32, screen and SD-reader markings. Photograph both sides before rework. Check that the PCB says C.6 and matches the current files. Save the supplier's assembly/BOM/substitution report.

Use the [assembly guide](ASSEMBLY_GUIDE.md) and [reference BOM](C6_BOM_BY_REFERENCE.csv). Inspect one component group at a time:

- All 43 resistors lie flat; verify their values from the BOM, not appearance alone. In-circuit resistance can be lower because other paths are connected; an instructor may isolate a lead if needed.
- Capacitor pad 1 is positive, pad 2 negative. The sleeve stripe marks negative. C21 is special: positive to U3 pin 8, negative to U3 pin 5, **not ground**. Look for crossed formed leads or stressed seals.
- Q1/Q2 KSP2222A are E-B-C; Q3 BC327 is C-B-E. Q4/Q5 TN0702 and Q6 LP0701 are S-G-D in numbered-pin order. These are not interchangeable simply because the plastic bodies fit.
- DIP chips face their socket notch/pin-1 mark. No folded-under pins, half-inserted chips or one-hole-offset modules. Inspect the back-side U4 orientation from the correct-side drawing.
- D2's banded pad 1 goes to ACT_3V2. D1 is the IR transmitter, **not** the mood LED. D3 is the four-lead RGB LED.
- Check cold-looking/incomplete joints, actual cracks, solder bridges, lifted pads and clipped wire fragments. A dull lead-free joint is not automatically bad; inspect wetting and continuity.
- Look below socketed modules for contact with opposite-side solder tails. Display support must not rely only on the header. Debug holes remain bare, not tall posts under another part.

**Pass:** correct parts and orientation, no visible damage or suspected bridge. **If uncertain:** stop and ask the instructor; do not apply power to settle the question.

## 5. M2 — prove the plugs and unpowered wiring

Disconnect the four-wire harness from both boards. Use pin numbers from the drawings, never left/right in a rear-view photo. Power J3 pin 1 must reach main J1 pin 1, and similarly 2→2, 3→3, 4→4. Check each wire end-to-end and check that it does **not** connect to any of the other three wires. Gently flex the disconnected harness while measuring. An intermittent connection is a failure even if the plug clicks.

| Main connector | Numbered pins |
|---|---|
| J1 SYS_IN | 1 MCU_5V; 2 GND; 3 LOGIC_3V3; 4 ACT_3V2. |
| J2 display | 1 GND; 2 LOGIC_3V3; 3 SCK; 4 MOSI; 5 RESET; 6 DC; 7 CS; 8 BLK. |
| J3 SD reader | 1 LOGIC_3V3; 2 CS; 3 MOSI; 4 SCK; 5 MISO; 6 GND. |
| J4 motor | 1 ACT_3V2; 2 switched motor return. |
| J5 speaker | 1 amplifier OUT1; 2 amplifier OUT2. Neither is GND. |

The two-pin motor and speaker plugs physically fit each other's sockets. Label them **MOTOR** and **SPEAKER** and check the wiring; matching plastic does not prove compatibility.

With the main still unpowered, the instructor checks all three rails to GND and rail-to-rail for suspected shorts. Compare to a verified board in the same module-population state when readings are ambiguous. The ESP32 module's `3V3` output is intentionally **not connected** to the board's LOGIC_3V3 rail. Do not “repair” that intentional separation with a jumper.

**Pass:** harness maps exactly, no intermittent connection, no unresolved rail-short suspicion. **Fail:** photograph and locate the fault before replacing any electronics.

## 6. M3 — verify main-board power first

Instructor: qualify the P.4 power module independently using its own guide before connecting main, or use a reviewed, coordinated three-rail fixture with correct sequencing. A random single-output supply is not a substitute. Begin with socketed loads and motor/speaker unplugged; test each populated stage with approved current limits. There is no validated universal main-board startup-current limit yet. Record the chosen limits and actual current; do not guess them from a USB charger's label.

Use a common system-GND reference. These are **investigation windows**, not a production specification or absolute maximum ratings:

| Main measurement | Nominal | Stop and investigate outside |
|---|---|---|
| TP1 or J1 pin 1, MCU_5V | 5.0 V | 4.75–5.25 V. |
| TP2 or J1 pin 3, LOGIC_3V3 | 3.3 V | 3.135–3.465 V. |
| TP3 or J1 pin 4, ACT_3V2 | 3.2 V | 3.04–3.30 V; upper bound deliberately tighter than +5%. |

Measure first at power J3, then at main J1 and the main TP. Correct source voltage but wrong main voltage points to the harness, connector or PCB path. Wrong voltage already at power J3 means troubleshoot power, not the screen. A steady voltmeter reading does not rule out fast brownout/overshoot; the instructor scopes startup and load changes.

After each approved stage: switch off, verify discharge, fit the next load, recheck polarity, power on and record the current change. If a rail collapses after adding a part, remove that part **with power off** and repeat the earlier stage. Do not put a suspect part into the known-good board until shorts/pinout have been checked.

## 7. M4 — isolate the ESP32 and firmware

If the processor will not communicate, the instructor removes it from the unpowered main board. Test the module **alone** with its own USB connector and a verified data cable. This separates a module/software issue from a main-board issue.

Check the selected port, OS permissions, cable and other programs holding the port. Record chip identification and actual flash/PSRAM; do not assume all “SuperMini” listings are N16R8. If needed, use the module's documented BOOT/reset procedure: on boards with the corresponding buttons, hold BOOT during reset to enter download mode, then release. Do not short unidentified header pins. Back up recoverable firmware/data before erasing or reflashing. See [Espressif boot-mode guidance](https://docs.espressif.com/projects/esptool/en/latest/esp32s3/advanced-topics/boot-mode-selection.html) and [connection troubleshooting](https://docs.espressif.com/projects/esptool/en/latest/esp32s3/troubleshooting.html).

**Module works alone, fails in main:** inspect socket alignment, 5 V at the module, its local regulator/reset behavior and GPIO back-powering during rail transitions. **Module also fails alone:** resolve cable/host/firmware/module first; main-board rework is not justified yet.

The power module's USB-C connector is charging-only and will never appear as the ESP32's data port. GPIO43/TX and GPIO44/RX are used for display DC/CS on this design; do not attach a UART adapter to them in the assembled toy. Use instructor-approved logging without a second power path.

## 8. M5 — buttons and the MCP23017 expander

The instructor's test firmware must identify U1 at I²C address **0x20**, set safe output latches before output directions, and report raw button state. AMP_EN and MOTOR_EN start low; RGB_OE_N starts high (blanked). A bus scan alone is not a complete functional test.

Instructor measurement: U1 pin 9 is 3.3 V, pin 10 GND; TP33/U1 pin 18 should leave reset and be high. SDA TP9 and SCL TP10 normally idle near 3.3 V. Persistent low can mean a bridge, reset/unpowered device, wrong initialization or a device holding the bus. Power off before isolation; do not force a bus high with a wire. U1 address pins 15–17 are grounded.

| Button | Expander / processor input | Expected when pressed |
|---|---|---|
| SW1 Up; SW2 Down | U1 GPA0 pin 21; GPA1 pin 22 | Low; released high. |
| SW3 Left; SW4 Right | U1 GPA2 pin 23; GPA3 pin 24 | Low; released high. |
| SW5 A; SW6 B | U1 GPB0 pin 1; GPB1 pin 2 | Low; released high. |
| SW7 X; SW8 Y | U1 GPB2 pin 3; GPB3 pin 4 | Low; released high. |
| SW9 Function | ESP32 GPIO2; TP12 | Low; released high. |

Press each ten times, hold for two seconds, release, then try intended two-button combinations. Raw changes should follow the correct switch; user-visible events should be one per deliberate press after debouncing. Contact bounce in raw readings is normal; stuck states are not. If the raw bit changes but the game ignores it, investigate firmware mapping/debounce rather than replacing the button.

Unpowered switch check: A/B are internally common and C/D internally common. Check **across the two groups**, not A-to-B; pressing joins the groups. In-circuit readings can include the pull-up network.

TP11/BUTTON_INT_N only behaves as a button interrupt **after firmware configures interrupts**. A constant high before setup is not evidence of a broken trace. GPA4–7 control RGB; GPB4/5 control audio/motor; GPB6 resets the screen. Do not configure those as more button inputs. GPB7 is unused.

## 9. M6 — display and backlight are separate tests

First check that J2 pin 2 receives 3.3 V and pin 1 reaches GND, with the header on the correct side and no one-pin offset. The supplied screen configuration is ST7789V2, **280 × 240 in landscape**. The instructor must use the exact panel's initialization, offsets and color order, not merely a similarly sized screen example.

| Symptom | Next check and what it means |
|---|---|
| Completely dark | TP20/BL_PWM command, Q2/Q3 path, R23 and TP21/J2 BLK. A faint image under external light can suggest backlight trouble, but is not definitive. |
| Backlight on, white/blank screen | Check reset TP19, CS TP17, DC TP18 and SPI clock/data TP13/TP14 with test firmware. Light alone does not prove data works. |
| Picture shifted, cropped or wrong colors | Check landscape dimensions, ST7789 initialization, offsets and RGB/BGR setting before reworking traces. |
| Works until SD is used | Check shared SPI transaction settings and that the non-selected device's CS is high. Test each module separately with power-off changes. |

R23 remains **100 Ω** until actual backlight current is measured. Do not bypass it to make the screen brighter. PWM measurements need a scope; a meter's average voltage is not an on-state limit. Instructor may calculate current from measured drop across R23 using I=V/R under a defined steady test, with insulated differential probing.

Pass the display test with red/green/blue/black/white fills, a border on all four edges, text and moving graphics. Record brightness setting, current and any resets. A black test pattern is not the same as a failed backlight.

## 10. M7 — microSD storage

Use a backed-up **test card**, not a student's only save data. Confirm the 3.3 V six-pin reader's pin order at J3. The selected 32 GB microSDHC card is intended for FAT32. Formatting erases data and is instructor-approved only.

Test in stages: detect card; write a uniquely named test file; close it; read it back and compare a checksum; reboot and read again. Repeat while the display updates, then during approved Wi-Fi activity. Record file size, checksum and SPI clock. Start with conservative bus speed; a speed reduction that helps suggests timing/signal-integrity or firmware transaction problems, not an automatic permanent fix.

TP16 is SD_CS. SPI clock is TP13, MOSI TP14. **There is no TP15 in this revision:** probe MISO at J3 pin 5 only with an instructor-prepared clip. Socket contamination, contact pressure, a wrong-voltage reader and incompatible software can all resemble a bad card.

Controlled interrupted-write recovery is an instructor test using disposable test data and the normal power-control fixture. Never pull the card live or repeatedly cut a real battery connection. An unimplemented recovery feature is BLOCKED, not a passed storage test. SD adds storage, not processor RAM or automatic support for downloadable applications.

## 11. M8 — RGB mood LED

Confirm D3's socket pin order: **1 red cathode, 2 common anode at 5 V, 3 blue cathode, 4 green cathode**. Do not force or twist the formed leads. U4 pin 16 uses 3.3 V; pin 1 GND. The LED must not be driven directly from the expander.

With test firmware: reset should keep the LED blank; command OFF, red, green, blue, then mixed colors briefly. Red is U4 OUT0/pin 5, green OUT1/pin 6, blue OUT2/pin 7. Data comes from U1 GPA4, clock GPA5, latch GPA6 and active-low blanking GPA7. There are no dedicated RGB test pads; the instructor checks DIP/socket pads with power-off clip placement.

If all colors are off, check both supply rails and OE_N first. If colors are swapped, compare socket lead order and software bits before bending leads. If one color fails, power off and check that lead/contact/path. R40 is **1.8 kΩ**, giving a calculated default near 10.4 mA/channel; measure rather than treating it as calibrated brightness. Always-on light at reset is a failure to investigate, not a harmless startup effect. Do not remove R40 or connect a cathode directly to ground.

## 12. M9 — IR receive first, then transmit

U2 is the **TSOP38238 receiver**. D1 is the **TSAL6200 transmitter**; D3 is RGB. Check U2 pin order 1 OUT, 2 GND, 3 supply and lens direction. TP32 is its filtered supply after R27; it should be close to the 3.3 V logic rail under normal light. A substantial drop suggests incorrect assembly, excess current or a supply-path problem.

Test receive with a known-compatible 38 kHz remote at a modest distance, away from strong sunlight. TP31/IR_RX normally rests high and produces low-going **demodulated bursts**, not a continuous 38 kHz waveform. Use a scope/logic analyzer and the decoder's raw-event display. A decoder saying “unknown protocol” while pulses arrive means the optical/electrical path may work but the software does not understand that remote. See the [Vishay receiver datasheet](https://www.vishay.com/docs/82491/tsop382.pdf).

Then transmit short, protocol-valid carrier bursts using GPIO7/TP30. Check Q1, R25, R26 and the **100 Ω R24** LED current-limiting path. The transmitter is supplied from LOGIC_3V3, not 5 V. Never hold the output on continuously as a brightness test or bypass R24. Verify with a second known-good receiver at a controlled distance; self-reception alone is insufficient. A phone camera may show some IR, but many filter it out: a dark camera image does not prove failure. Do not aim the LED into anyone's eyes.

## 13. M10 — vibration motor

Check the motor is at J4, not J5. Start with motor command OFF. Instructor verifies U1 GPB5/pin 6 remains low until requested, then commands a short pulse (for example 100 ms) with a current limit approved for the actual motor. Secure the motor; do not stall or hold its shaft/rotor.

During ON, Q4 pulls J4 pin 2 / TP29 toward GND; voltage **across J4 pins 1 and 2** drives the motor. An unloaded OFF return may float; do not demand a universal TP29 off-voltage. Check the ACT_3V2 rail dip, R28 gate path, R29 pull-down, and D2/C16 suppression if there is a reset or large transient. D2 band faces ACT_3V2. A motor that stays on when commanded off needs investigation before reconnecting it for further use.

No movement with correct voltage across the connected motor points toward its harness/motor or mechanical retention. Voltage disappearing under load points toward a short, excessive load or supply path. Do not test it by connecting it straight to an unspecified battery.

## 14. M11 — audio: protect the speaker and the meter

Instructor first leaves the speaker disconnected. Verify U3 and C21 orientation, Q6 LP0701 pin order, and the bridge wiring: U3 pin 1→J5 pin 1, U3 pin 3→J5 pin 2, U3 pin 4→GND. Q6 pin 1 is ACT_3V2; Q6 pin 3/C25 positive/U3 pin 2 is switched amplifier supply.

With AMP_EN (U1 GPB4/pin 5) low, the amplifier supply should decay toward zero after settling. With AMP_EN high, it should rise toward ACT_3V2; record Q6's drop and current. Unexpected enable behavior suggests Q5/Q6 orientation, R36–R39 or firmware, not necessarily a bad amplifier. There are no separate amplifier-enable/supply test pads: use identified component pads, not guessed TP numbers.

Signal path: GPIO8/TP22 → R30/C18 → R31/C19/TP23 → C20 → R32/R33 → U3 pin 7. Scope input PWM, filtered signal and the two outputs under a defined silence/tone program. The design review assumed a 200 kHz PWM carrier; an arbitrary example may hiss, click or use the wrong output pin. Use midscale PWM silence, settle, then enable/fade in; fade out before disabling.

**Never clip a grounded scope lead to either J5 pin.** Use an appropriately rated differential probe, or two compatible channels with both ground clips at system GND and channel subtraction. Scope grounds are usually connected together. Do not connect a grounded external audio input to the bridged speaker pair.

At commanded silence, measure differential DC **across J5**; individual outputs can have a normal DC bias. The exact speaker's continuous power rating is unresolved, so no validated allowable DC offset or production volume limit exists. If there is sustained unexplained differential DC, clipping, strong popping or heating, leave the speaker disconnected and escalate. After instructor approval, attach the speaker with power off and start the test tone at the lowest practical volume, increasing only while measuring. Do not infer speaker safety from a firmware percentage.

## 15. M12 — integration, intermittents and repeatability

Only after each earlier stage passes, add normal Wi-Fi traffic, display updates, SD writes, one RGB state, short IR/motor bursts and low-level audio in controlled combinations. Use approved loads and temperature limits. Record the rail minima/maxima and reset logs; a handheld meter can miss the event that causes a brownout.

For a first prototype run, propose ten supervised cold starts and a ten-minute representative activity run **after** the instructor approves power and temperature limits. These are repeatability screens, not lifetime, toy-safety or battery certifications. Never leave an unqualified assembly charging unattended. Stop for resets, rail excursions, current-limit cycling or abnormal temperature rise.

Keep the power PCB, battery and wires outside the main antenna region. Compare radio behavior with and without the final enclosure only under the same test conditions. Don't call weak Wi-Fi a solder fault before checking firmware, network configuration and the metal/battery placement.

The old main reservation of 0.5 A on 3.3 V exceeds the power screening target of 0.4 A. The instructor must measure the actual simultaneous demand and approve margin; neither figure is a measured capacity. A failure under combined load can require design revision, not more solder or a larger battery.

## 16. Quick symptom route

| Symptom | First route |
|---|---|
| Absolutely nothing happens | Section 1 (assembly/firmware state), M2 harness, then M3 rails. |
| Supply current limit / part heating | Stop; M1/M2 unpowered inspection, instructor isolates the last-added load. |
| ESP32 repeatedly resets | M3 transient power, M4 boot/firmware, then isolate the triggering peripheral. |
| Buttons and motor/audio controls all fail | M5 expander supply/reset/I²C, not nine independent switch replacements. |
| One button stuck | M5 raw bit, pin grouping, pull-up and joint. |
| Screen lit but blank | M6 initialization/reset/SPI; then firmware prerequisites. |
| SD works alone but not with screen | M7 and M6 shared-bus chip selects/settings. |
| RGB never lights / wrong colors | M8 rails, blanking and lead/bit order. |
| IR does not decode | M9 raw pulses and known-compatible source before decoder changes. |
| Motor causes reset | M10 current/suppression and M3 transient rail measurement. |
| Audio hums/pops or gets hot | M11 bridge wiring, DC, supply, PWM/filter and switch timing. |
| Works only when pressed/bent | Power off; inspect socket, crimp, joint and solder-tail contact. Do not keep flexing live. |

## 17. Record the failure; repair only with evidence

Use the accompanying worksheet. Record setup, connected modules, source/limits, firmware version, exact probe points, measured values, and the first failed step. Photograph before/after each repair. Write PASS, FAIL, BLOCKED or NOT RUN—never leave an unperformed test marked PASS. For all five boards, record serials separately and keep one genuinely verified unit as the comparison reference.

An instructor may reflow a confirmed through-hole joint, correct an identified assembly error or replace a verified wrong part. First preserve the factory evidence and check return/warranty instructions. Missing internal copper, repeated identical failures, damaged pads or an unresolved design/load issue go to the designer/factory; do not hide them with undocumented jumper wires.

After a repair, repeat M1/M2, M3 power, the failed function, and M12 integration. Keep the repaired part/lot information. Passing this guide establishes only the tests actually recorded, not a finished product certification.

## 18. Instructor pin and probe reference

All main test points are on **B.Cu, the rear copper face**. Their numbers have intentional gaps. Native CAD coordinates use the board's front-view origin, X right/Y down; a rear viewing drawing is mirrored. Find the reference in the assembly drawing before measuring. Do not add pins beneath parts just to make probing easier.

| ESP32 GPIO / header label | Assigned main signal |
|---|---|
| GPIO1 / 1; GPIO2 / 2 | Button interrupt; function button. |
| GPIO4 / 4; GPIO5 / 5 | I²C SDA; I²C SCL. |
| GPIO6 / 6; GPIO7 / 7 | IR receive; IR transmit. |
| GPIO8 / 8; GPIO9 / 9 | Audio PWM; backlight PWM. |
| GPIO10 / 10 | SD chip select. |
| GPIO11 / 11; GPIO12 / 12; GPIO13 / 13 | SPI MOSI; MISO; clock. |
| GPIO43 / TX; GPIO44 / RX | Display DC; display chip select—not a free debug UART. |
| GPIO3 / 3; module 3V3 output | Intentionally unconnected to main functions / external logic rail. |

Verify the actual seller module matches these header assignments before using firmware. The following complete TP table is generated directly from the current release map.

<!-- GENERATED_TEST_POINT_TABLE -->

| TP | Signal | What to expect / use | CAD X, Y mm |
|---|---|---|---|
| TP1 | `MCU_5V` | Main 5 V input; nominal 5.0 V. | 54.0, 33.0 |
| TP2 | `LOGIC_3V3` | Logic supply; nominal 3.3 V. | 29.5, 73.5 |
| TP3 | `ACT_3V2` | Actuator supply; nominal 3.2 V. NOT power-board BAT_NEG. | 28.5, 53.5 |
| TP4 | `GND` | System ground reference. | 55.5, 76.5 |
| TP6 | `GND` | Alternate system ground. | 59.5, 76.5 |
| TP8 | `GND` | Alternate system ground. | 55.5, 80.5 |
| TP9 | `I2C_SDA` | I2C SDA; normally idle high with valid logic power. | 9.5, 4.5 |
| TP10 | `I2C_SCL` | I2C SCL; normally idle high with valid logic power. | 22.5, 73.5 |
| TP11 | `BUTTON_INT_N` | Active-low expander interrupt; requires firmware interrupt configuration. | 35.0, 39.5 |
| TP12 | `BUTTON_FN_N` | Function button; released high, pressed low. | 44.5, 75.0 |
| TP13 | `SPI_SCK` | Shared SPI clock; activity only during transfers. | 35.5, 43.5 |
| TP14 | `SPI_MOSI` | Shared SPI MOSI; activity during transfers. | 66.5, 52.0 |
| TP16 | `SD_CS` | SD chip select; normally high when deselected. | 61.5, 43.0 |
| TP17 | `TFT_CS` | Display chip select; normally high when deselected. | 44.5, 39.5 |
| TP18 | `TFT_DC` | Display command/data selection; state depends on transfer. | 48.5, 39.5 |
| TP19 | `TFT_RST_N` | Display reset, active-low; controlled by U1 GPB6. | 22.5, 69.5 |
| TP20 | `BL_PWM` | Backlight PWM before driver; meter shows only an average. | 26.5, 69.5 |
| TP21 | `Net-(J2-BLK)` | Display BLK after switching/current-limiting path; load/PWM dependent. | 72.0, 66.5 |
| TP22 | `AUDIO_PWM` | Audio PWM before filter; inspect with scope and known test program. | 56.0, 37.0 |
| TP23 | `Net-(C19-Pad1)` | Second low-pass filter node, C19 pad 1/C20 input; waveform and DC bias depend on PWM. C19 is nonpolarized. | 48.5, 72.5 |
| TP29 | `Net-(D2-A)` | Switched motor return; near GND during ON, may float unloaded when OFF. | 19.5, 90.5 |
| TP30 | `IR_TX` | IR transmit logic; valid carrier bursts, not continuous DC test. | 17.5, 16.5 |
| TP31 | `IR_RX` | IR receive output; normally high, low-going demodulated bursts. | 22.5, 13.5 |
| TP32 | `Net-(U2-VS)` | IR receiver filtered supply; normally close to LOGIC_3V3. | 13.5, 4.5 |
| TP33 | `Net-(U1-RESET_N)` | Expander reset; should rise high after startup. | 73.5, 73.5 |

<!-- END_GENERATED_TEST_POINT_TABLE -->

Sources: [current schematic](SCHEMATIC.pdf), [connector coordinates](../release_checks/CONNECTOR_PIN_MAP.csv), [test-pad coordinates](../release_checks/TEST_POINTS.csv), [MCP23017 datasheet](../datasheets/mcp23017.pdf), [TDA2822L datasheet](../datasheets/tda2822.pdf), [TLC5916 datasheet](../datasheets/tlc5916.pdf). Existing release manifests identify the exact CAD; this troubleshooting supplement does not change the boards or previously issued ZIPs.

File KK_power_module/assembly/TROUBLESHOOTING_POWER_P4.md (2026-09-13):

# Power P.4 — troubleshooting and factory-return guide

For the compact **50 × 50 mm, four-layer** Keychain Kreatures power module, paired with C.6 main. Guide version 1, 2026-09-12. Work from the first failed stage, not from a guessed bad component.

**Students begin with identification and unpowered inspection. All powered power-module tests are instructor/qualified-technician work.** Students may observe and record results. This board contains fine-pitch surface-mount parts and lithium-battery charging/protection circuitry; it is not the student through-hole soldering exercise.

This is a proposed test procedure for engineering samples, not a record of completed testing or a battery-safety certification. If the required equipment or qualified supervision is missing, mark the test **BLOCKED** and ask the factory to perform it.

## 1. What should a factory-delivered board do?

| Delivered item | Correct expectation |
|---|---|
| Bare P.4 PCB | Cannot regulate or charge until its parts are assembled. Do not connect power. |
| Factory-assembled P.4 | Can be tested independently with the approved fixture. It does not need ESP32 firmware. |
| P.4 without a battery/thermistor | Not a complete rechargeable product. Missing charge indications do not by themselves prove failure. |
| P.4 attached to a blank main board | Does not create game software or prove the main is assembled correctly. |

There are 108 fitted electrical positions and 28 rear bare test pads. The four mounting holes do **not** align with main C.6. Use independent supports; do not force a common four-standoff stack. Some inherited BOM value text says `C.5 SYS_IN / XH`; J3's actual four-wire interface remains the one below. Identify the power revision from the PCB/title and current release files, not that inherited connector description.

Before rework, collect photographs, serial/lot numbers, factory inspection/X-ray reports, approved BOM substitutions and bare-board electrical-test results. Preserve one untouched failing unit when possible. “DRC passed” means the design files passed the reported CAD checks; it does not mean every fabricated joint and IC works.

## 2. Stop conditions and prohibited shortcuts

Stop for smoke, unusual smell, rapid temperature rise, reversed polarity, swelling/leaking cell, oscillating startup or unexplained current limiting. Turn off external supplies if safe and alert the instructor. Do not touch hot parts, move a damaged cell by hand or continue cycling power. Follow the lab's emergency procedure.

- Never short or jumper a fuse, protection FET, eFuse, rail gate, regulator enable or thermistor input to make the board start.
- Never replace F1 with a higher rating, bypass the USB current limiter, or substitute a “similar” charging IC without design review.
- Never connect an unspecified battery. The eventual pack is conventional **1S, 4.2 V maximum** Li-ion/LiPo; chemistry, current, temperature limits, connector polarity and protection coordination still need approval.
- Never place a multimeter in A/mA mode directly across a rail or cell. Never short a real cell for a protection test.
- Never connect external sources to J3 outputs. J3 is an **output**, not a battery or USB input.
- Never plug ESP32 USB in while the main receives this board's external rails.
- Never lift equipment protective earth to solve a grounding problem. Use the right isolated/floating fixture and rated measurement equipment.
- No student hot-air rework of QFN/WCSP packages. Preserve factory return evidence before any technician repair.

## 3. The two returns: the most important wiring rule

**J2 pin 2 / TP3 is BAT_NEG. J3 pin 2 / J4 pin 2 / TP4 is system GND. They are different nets.** The protection FETs control the connection between them. An external wire or test-equipment earth connection between them can bypass protection.

A small voltage difference or low resistance between BAT_NEG and GND does **not** automatically prove a solder bridge: the protection FETs may be conducting normally, and meter polarity can affect semiconductor readings. Never demand an open-circuit reading in every operating state. The technician must distinguish intended conduction through Q1–Q3 from an unintended copper/solder/fixture bypass, using the schematic and controlled emulator tests.

Before power, draw the grounding of the **source, oscilloscope, electronic load, USB host, USB meter and computer-connected instruments**. If the source's negative terminal at BAT_NEG is tied to earth and a scope/load ties GND to earth, the protection is bypassed. Use a verified floating source/fixture or appropriately isolated measurements that do not create this return connection. A battery-powered meter can also become grounded through its USB logging cable. Do not assume “USB disconnected from main” eliminates every earth path.

System rail measurements below use **TP4 GND** unless explicitly stated otherwise. Cell-side voltage is measured across **J2 pin 1 and J2 pin 2**. Do not move a ground clip between those domains while powered.

## 4. Equipment and record keeping

Unpowered student station: printed current drawings, magnifier, nonconductive holder and supervised multimeter. Black lead in COM, red in V/Ω. Continuity/resistance only with all sources disconnected and capacitors discharged; verify the meter on shorted/separated probes first. A brief rail beep can be capacitor charging. Record settled resistance and probe direction rather than inventing one pass/fail resistance for all circuits.

Instructor powered station: current-limited, correctly isolated battery simulator; voltage/current readback; approved load fixture; fine insulated test clips; temperature measurement; scope/differential measurement; verified USB-C advertisement/source fixtures and cables. For **charging while a battery emulator is connected**, the emulator must be **sink-capable/bidirectional** and configured for the expected current. An ordinary bench supply generally cannot absorb charging current and is not acceptable in that state.

Keep the real cell and populated main disconnected until their prerequisite checks pass. Use the actual Semitec 103AT-2 in the bench fixture as appropriate; real-cell work requires a bonded, electrically insulated sensor on the selected cell. A loose sensor on the bench does not protect a real battery's temperature.

Record board serial, lot, setup photograph, equipment model, isolation arrangement, current limits, ambient temperature, load conditions, probe reference and actual readings. PASS means a performed test met its stated criterion. FAIL means an observed mismatch. BLOCKED means equipment/approved limits are missing. NOT RUN is not PASS.

## 5. P1 — unpowered incoming inspection

Check the 50 × 50 mm/R3 outline, four 2.2 mm mounting holes, intact board edges and P.4 revision. Inspect USB shell anchors, connector latches, switch and both copper faces. Look for missing components, wrong orientation, displaced tiny parts, solder beads, damaged pads or scratches. Use the [reference BOM/placement](../release_checks/BOM_AND_PLACEMENT.csv) and [schematic](SCHEMATIC.pdf), not an older revision's coordinates.

The assembler must confirm these particularly important parts, not just that a package fits:

| Position | Required part / reason to check |
|---|---|
| U1 | **BQ24075TRGTR** charger; the T variant matters. |
| U13 | **TPS22950YBHR**, base variant, 0.4 mm WCSP; C/L variants are not automatic substitutes. |
| U2 and Q1–Q3 | DW01A and three FS8205 banks; protection pinout/orientation matters. |
| U4 | TPS259530 eFuse and its programming resistors. |
| U5–U7 | TPS63060 regulators; L1–L3 and feedback/output capacitors must match the BOM. |
| U8–U10 / U11 / U12 | Output gates / buffer / independent voltage supervisor. Do not omit them to get output. |
| F1 | 4 A fast fuse, exact BOM part; do not bridge it. |
| J2/J3/J4 | Battery VH / four-wire XH / thermistor PH families; polarity is not guaranteed by wire color. |

Confirm the factory approved **filled, capped, planarized via-in-pad**, fine-pitch assembly and hidden-joint inspection. Ordinary tenting is not equivalent. The release lists 74 via centers inside SMD pads; partial overlaps also need review. Hidden WCSP/QFN joints cannot be cleared by looking only at the board's top. If assembly process or part substitution is undocumented, hold powered testing and obtain the factory response.

## 6. P2 — verify the connectors and fuse without power

| Connector | Exact numbered functions |
|---|---|
| J1 USB-C | Charging input only. D+/D− and SBU are intentionally not connected. |
| J2 battery, VH | 1 CELL_PLUS; 2 BAT_NEG. |
| J3 to main, XH | 1 MCU_5V; 2 GND; 3 LOGIC_3V3; 4 ACT_3V2. |
| J4 thermistor, PH | 1 NTC; 2 GND. |

Check the disconnected four-wire harness end-to-end: power J3 1→main J1 1, 2→2, 3→3, 4→4; no cross-connections. Inspect crimps and gently flex the disconnected harness during continuity testing. Verify battery-harness polarity independently before any future cell connection. Connector mirroring in rear drawings is a common source of mistakes.

Technician: check F1 end-to-end for continuity using its identified pads and compare the meter's lead resistance. An open fuse is a **symptom**; determine the reason before replacing it. Confirm J2 pin 1 reaches F1's CELL_PLUS side and the other side reaches VBAT/TP2. Check VBUS, SYS_RAW, SYS_SW and all six pre-/post-gate rails for unresolved short indications to system GND and one another. Compare only with a verified board in the same unpowered state. Do not bypass protection to make a continuity test simpler.

**Pass:** correct mapping, no physical damage or unexplained short, fuse intact, approved test fixture grounding. Otherwise stop at this stage.

## 7. Understand the stages before chasing an output

| Stage | Function and accessible checkpoints |
|---|---|
| Cell path | J2 → F1 → VBAT TP2 → charger power path → SYS_RAW TP5; low-side protection is U2/Q1–Q3. |
| USB path | J1 → VBUS TP1 → U13 current limiter → USB_CHG TP22 → U1 → SYS_RAW TP5. U14/U3/Q4/Q5 select the permitted input-current mode. |
| User switch / eFuse | SW1/RUN_CTL TP7 and U4 create SYS_SW TP6 from SYS_RAW. |
| Regulation | U5/U6/U7 produce REG_5V TP13, REG_3V3 TP14 and REG_3V2 TP15. |
| Supervision | U12 evaluates the rails; VOLTAGES_OK TP28 → U11 → RAILS_EN TP12. PG_ALL TP11 is a separate regulator-status node. |
| Gated outputs | U8/U9/U10 → MCU_5V TP16, LOGIC_3V3 TP17, ACT_3V2 TP18 → J3. |

When all outputs disappear together, first check shared upstream power and supervision. Do not assume three regulators independently failed. Never jump across a gate or pull its enable high to defeat a failed prerequisite.

## 8. P3 — battery-simulator startup, USB disconnected

Instructor only. Disconnect main J3, USB J1 and any real battery. Connect the reviewed floating current-limited simulator to **J2 positive pin 1, negative pin 2**. Confirm the voltage at the disconnected fixture plug before inserting it. Start at **3.7 V with SW1 OFF** and an initial current limit around **50 mA**, as in the existing review procedure. This is a cautious off-state inspection setting, **not** a claim that an enabled three-regulator board will start at 50 mA.

Measure and record off-state input current. There is no validated quiescent-current acceptance number yet; compare with approved calculations/verified samples and investigate unexpected current or heat. USB status LEDs may be dark during battery-only operation. Check cell-side voltage, then the protected system path with the correct reference. If protection is latched, follow the selected protection devices' documented recovery sequence using the qualified fixture; do not bypass them.

Switch off the fixture before moving clips. The instructor then selects a bounded startup current limit justified by expected no-load inrush and equipment limits, records it, and enables the board. Increase only after determining that current limiting—not a short—is preventing startup. Watch voltage and current together; repeatedly increasing the limit is not troubleshooting.

### Locate the first missing stage

| Probe, relative to TP4 | Expected qualitative state with a valid 3.7 V source and SW1 ON | If not present |
|---|---|---|
| TP2 VBAT | Battery-derived voltage when the protected return conducts; compare with cell-side measurement. | Check simulator, F1 and protection/return path; do not assume GND=BAT_NEG. |
| TP5 SYS_RAW | Battery-derived system supply, allowing power-path drop. | U1 power path, source/protection and assembly. |
| TP7 RUN_CTL | Close to SYS_RAW when ON; near GND when OFF. | SW1 mapping/joints and control path. |
| TP6 SYS_SW | Close to SYS_RAW after valid enable/UVLO and ramp. | U4, UVLO/divider, load fault or source sag. |
| TP13 / TP14 / TP15 | Approximately 5.0 / 3.3 / 3.2 V after startup. | Corresponding U5/U6/U7, shared REG_ENABLE, inductor, feedback/output path. |
| TP28 VOLTAGES_OK | High near REG_3V3 after required rails are valid and supervisor delay. | Find the rail below threshold, sensing network, U12 supply/reset or fault. |
| TP12 RAILS_EN | Follows a valid high through U11. | Check U11 supply and signal path; do not force it. |
| TP16 / TP17 / TP18 | Approximately 5.0 / 3.3 / 3.2 V at the gated outputs. | Compare pre-gate rail and enable, then U8/U9/U10 or downstream short. |

TP11 PG_ALL is pulled toward REG_3V3 when the tied regulator status outputs release it. A low value while a regulator is starting is not surprising; a high does **not** substitute for measuring all rails or the independent supervisor. State timing and scope capture matter.

These are steady-state diagnostic expectations, not permission to force power onto an unpowered control pin. Probe small IC pins only if a dedicated pad is insufficient and the technician has a safe method. Do not probe regulator switch-node/inductor pads casually; a slip there can destroy the converter.

## 9. P4 — qualify the outputs with no main attached

Measure each pre-gate rail, post-gate rail and J3 pin under the same settled condition. A correct test pad but bad connector pin points toward an open pad/trace/joint. Correct pre-gate voltage and missing post-gate voltage points toward gating, enable or a downstream load, not automatically the regulator.

| Rail | Nominal | Initial investigation window |
|---|---|---|
| REG_5V / MCU_5V | 5.0 V | 4.75–5.25 V. |
| REG_3V3 / LOGIC_3V3 | 3.3 V | 3.135–3.465 V. |
| REG_3V2 / ACT_3V2 | 3.2 V | 3.04–3.30 V. |

These windows are conservative prototype checks, **not qualified production limits**. ACT_3V2's upper bound is deliberately below +5%; reject unexplained excursions above the design's 3.3 V target ceiling before connecting main loads. Scope startup, shutdown and load transitions: a meter can miss dangerous spikes or short dropouts. Do not approve ripple or temperatures without defining limits for the actual attached components.

The calculated supervisor low thresholds are approximately 4.64 / 3.06 / 3.00 V. Therefore, “VOLTAGES_OK high” does **not** mean the rails meet the tighter investigation windows. A supervisor fault may correctly turn off all outputs when only one rail is low.

Switch OFF and check outputs decay without remaining powered by the load fixture. Record decay time and any residual voltage; an unloaded high-impedance meter can show leakage/charge. Do not use a wire to pull it down. Confirm the no-backfeed fixture state before declaring a gate stuck on.

## 10. P5 — controlled loads and low-voltage behavior

Instructor only, with correctly referenced rated loads and temperature measurement. Keep main and the real cell disconnected. Begin at no load, increase **one rail at a time** in reviewed steps, then test combined loads only after individual results are acceptable. Do not connect an earth-referenced electronic load in a way that bypasses BAT_NEG protection. Resistor loads can become burn hazards; calculate power rating and provide safe mounting if used.

The design's unvalidated screening targets are **5 V at 0.6 A, 3.3 V at 0.4 A and 3.2 V at 0.5 A**. They are not guaranteed delivered ratings. Record actual load/current, cell-side input power, rail minima/maxima, ambient and component temperatures at each step. Stop on unexpected heat, oscillation, current limit or rail excursions. Establish acceptable temperatures from component ratings and the intended enclosure/ambient before a prolonged run; “comfortable to touch” is not a thermal qualification.

Using the simulator, check startup/shutdown and a controlled voltage ramp around the system cutoff. Calculated SYS_RAW eFuse UVLO is about **3.38 V rising / 3.10 V falling**, with tolerances and source sag. It is not a fixed guaranteed trip at the cell connector. Record the observed SYS_RAW thresholds, recovery and hysteresis. Do not deliberately overdischarge a real cell to perform this test.

Hard shorts, fuse opening and protection-trip validation require a separately approved technician test fixture/procedure and emulator. They are **not student exercises** and not accomplished by touching output pins together. Do not intentionally blow F1 as a routine incoming test. If fault-injection equipment or safe test limits are unavailable, record BLOCKED and obtain factory/design-lab testing.

Main's historical 3.3 V reservation was 0.5 A; this power screening used 0.4 A. Resolve actual combined peak demand and margin before approving integration. A failure at an unqualified combined load may expose a design limit, not a manufacturing defect.

## 11. P6 — USB input and current selection

Instructor only. First remove the non-sinking ordinary supply, if one was used for battery-only checks. Any emulator remaining at J2 during charging must absorb the charge current safely. Keep main disconnected. Use verified sources/cables and measure total USB input current with a reviewed fixture; an inline USB meter that changes CC behavior can invalidate the test.

Check TP1 VBUS for nominal 5 V when a compatible source is attached. Check TP25 CC_3V3 near 3.3 V, then TP22 USB_CHG. Voltage absent at TP1 suggests cable/source/connector; present at TP1 but absent at TP22 suggests U13, current-limit/fault conditions or a short downstream. A valid USB input does not guarantee the three toy outputs are on.

| Verified source advertisement | TP20 CC_DEFAULT_N | TP21 USB_HIGH_CURRENT | Interpretation |
|---|---|---|---|
| USB-A/default or USB-C default | High near CC_3V3 | Low | Default low-current path intended. |
| USB-C advertising 1.5 A or 3 A | Low | High near CC_3V3 | Higher-current path permitted by this design. |
| No USB source | CC supply may be absent | Not a meaningful normal logic test | Do not demand powered logic levels. |

This follows TUSB320 GPIO OUT1 and the Q4 inverter in the current netlist. The design does not distinguish 1.5 A from 3 A for its mode selection. A source's advertisement is an available limit, not the current the board must draw. See [TI's TUSB320 GPIO truth table](https://www.ti.com/lit/ds/symlink/tusb320lai.pdf).

The default limiter is calculated near **50 mA**, with a datasheet screening range of roughly **34–66 mA**, plus upstream consumption and resistor tolerance. A USB-A connection may charge very slowly or fail to sustain a running toy; that behavior is not automatically a broken charger. This design has no USB enumeration, suspend detection or BC1.2 negotiation; do not claim universal computer-port compliance. Initial fault investigation should use controlled test sources, not risk a student's laptop port.

On a suitable USB-C source, U1's programmed input limit is approximately 1.23 A, screened up to about 1.32 A. This is not the battery charge current. A 3 A charger does not command 3 A charging. Check default, 1.5 A and 3 A advertised modes, both cable orientations, attach/unplug, weak-source behavior and switchover, recording overshoot/current. Do not force the higher-current mode when a source advertises only default current.

## 12. P7 — charging and the temperature sensor

Use a correctly configured sink-capable battery emulator and known sensor/test fixture, or a **previously approved** cell with its bonded/insulated sensor. No battery has been finalized by this hardware release. Charge tests with an unselected cell are BLOCKED.

At an appropriate simulated battery voltage and normal sensor temperature, check TP22 USB_CHG, TP19 NTC, input status and actual battery current. Record current direction: emulator sinking current indicates charge; the same connection may source current into the toy under other conditions. An LED alone does not prove charge current reaches the battery.

| Indicator/checkpoint | What it tells you—and what it does not |
|---|---|
| LED1 POWER GOOD / TP26 PGOOD_N | Charger recognizes a valid input when status is asserted low. Does not certify J3 output rails. |
| LED2 CHARGING / TP27 CHARGE_N | Low generally indicates charging. Off may mean complete, disabled, invalid source, temperature inhibit or another condition; flashing can indicate a timer fault. Measure and consult U1's status definitions. |
| TP19 NTC | Analog temperature-sense voltage, not a digital on/off flag. Depends on USB_CHG, R74/R75 and sensor resistance. |

PGOOD_N and CHARGE_N are open-drain indicators connected through their LED/resistor paths to VBUS, not guaranteed 3.3 V logic outputs. Use an appropriately rated meter/probe. Do not connect them directly to an ESP32 or a 3.3 V-only logic analyzer.

The nominal full charge-current setting is about **0.303 A**, screened **0.271–0.332 A** under the reviewed conditions. Precharge, near-full taper, thermal regulation, input limits or system load can legitimately lower it. Do not demand 0.303 A at every battery voltage. Verify termination and recharge behavior against [BQ24075T's datasheet](../datasheets/BQ24075TRGTR.pdf), recording source, battery voltage, temperature and load conditions.

Sensor check with **all power off and sensor unplugged**: measure the actual 103AT-2 resistance at a recorded temperature; nominal is 10 kΩ at 25°C, not at every room temperature. Inspect J4 and its lead continuity. An instructor may gently change the detached sensor's ambient temperature in a controlled setup; do not heat/chill a real cell to provoke faults.

Temperature-threshold screening gave roughly 4.8°C cold and 40.0°C hot nominal, with screened corners about 2.9–42.2°C. These are calculations, not certified pack limits. Instructor-only open/short/temperature simulations use a purpose-built fixture and emulator, changing connections with power off. Confirm charging inhibits as specified and recovers properly; never leave a short or fixed resistor installed as a replacement for a real pack sensor. Do not bypass a temperature inhibit to finish a test.

## 13. P8 — reverse feed, sequencing and final integration

Before attaching main, the technician checks rail rise/fall ordering, load-gate behavior and absence of damaging GPIO/module back-powering using the exact SuperMini revision. Equal timing capacitors do not prove safe sequencing. Do not power one output separately as an improvised test; use a reviewed fixture for controlled backfeed analysis.

Measure USB reverse feed with an approved breakout/isolation test arrangement, not by shorting VBUS or returning power to a laptop. Record current as well as voltage: residual voltage on a high-impedance meter can be stored charge or leakage, not necessarily damaging backfeed. Validate source transitions with the actual planned load. If the fixture or acceptance limits are missing, record BLOCKED.

Only after P1–P7 and sequencing/backfeed checks pass, connect the verified pin-for-pin harness to an unpowered main at its minimal approved population. No ESP32 USB cable. Recheck rails at both ends before adding loads in the main guide's order. Stop when the first added function causes a fault; power off, remove that load and compare with the last passing stage. Do not use a known-good main as a sacrificial dummy load for an unqualified power board.

For each sample, record repeated cold-start behavior and a supervised representative-load run after temperature/current limits are approved. Keep battery and power PCB clear of the main antenna and solder tails; separate support height, plug access and final case fit remain unqualified. Passing a bench test in open air is not proof of enclosed thermal safety.

## 14. Quick symptom route

| Symptom | First investigation |
|---|---|
| Board appears dead from the factory | Confirm assembled vs bare; P1/P2; source polarity and protected return; P3 first missing stage. No firmware is needed by power itself. |
| Input immediately current-limits | Stop; source/fixture setting, polarity, bridges and the first shorted stage. Never just increase the limit. |
| Battery-only works; USB does not | P6 VBUS → CC_3V3 → USB_CHG, cable orientation/source mode; then charger status. |
| USB works; battery-only does not | P2 fuse/harness; P3 protection and U1 battery power path; emulator recovery state. |
| SYS_RAW present, SYS_SW absent | SW1/RUN_CTL, UVLO and U4/fault/load condition. |
| All three outputs absent | Measure pre-gate rails, TP28 and TP12; one low rail may correctly gate all outputs off. |
| One regulator output wrong | That U5/U6/U7 channel's input/enable, inductor, feedback values, capacitor/joint and load. |
| Regulator output correct, J3 rail missing | Enable plus U8/U9/U10 gate path and connector continuity. |
| LEDs lit, main dead | LED1/2 describe charger status, not main rails. Measure J3 and the harness. |
| Charges on USB-C but slowly on USB-A | May be intended default-current behavior; verify P6 mode and measured current before calling it a defect. |
| Charging never starts | Source, emulator/cell state, actual current direction, NTC/sensor, status; P7. |
| Repeated on/off or ticking | Source sag/current limiting, UVLO, load transients, unstable regulator or supervisor cycling; scope first failed stage. |
| Works on bench, fails in case | Support shorts, wire stress, connector access, cooling and antenna/cell placement; do not keep operating closed. |

## 15. Complete test-point reference

All 28 test points are on **B.Cu, the rear copper face**. Coordinate values below are native front-view CAD coordinates, X right/Y down; rear drawings are mirrored. Use the reference label and [assembly drawings](../release_checks/drawings/) to locate the actual pad. Attach clips with power off, support the board and do not bridge adjacent pads.

**TP numbers are board-specific.** Power TP3 is BAT_NEG; main TP3 is ACT_3V2. Never carry a remembered TP number from one board to the other.

<!-- GENERATED_TEST_POINT_TABLE -->

| TP | Signal | What to expect / use | CAD X, Y mm |
|---|---|---|---|
| TP1 | `VBUS` | Raw USB VBUS; nominal 5 V when attached. | 5.0, 29.0 |
| TP2 | `VBAT` | Fused battery positive; interpret with protection state/reference. | 8.5, 29.0 |
| TP3 | `BAT_NEG` | BAT_NEG, cell-side return. Never use as a spare system GND. | 12.0, 29.0 |
| TP4 | `GND` | System GND; usual rail-measurement reference. | 15.8, 28.5 |
| TP5 | `SYS_RAW` | Charger/system power path output; varies with source and operating state. | 20.0, 29.0 |
| TP6 | `SYS_SW` | After eFuse; near SYS_RAW when enabled and healthy. | 23.0, 29.0 |
| TP7 | `RUN_CTL` | User run command; OFF near GND, ON near SYS_RAW. | 26.5, 29.0 |
| TP8 | `EF_UVLO` | eFuse analog undervoltage divider; do not drive externally. | 30.0, 29.0 |
| TP9 | `EF_ILIM` | eFuse current-programming node; no universal digital level. | 34.0, 29.0 |
| TP10 | `EF_FAULT_N` | Active-low eFuse fault; pull-up is to SYS_RAW, not fixed 3.3 V. | 44.0, 40.0 |
| TP11 | `PG_ALL` | Regulator status, pulled toward REG_3V3; not independent supervisor output. | 41.0, 29.0 |
| TP12 | `RAILS_EN` | Common output-gate enable; high after valid supervision. | 44.5, 29.0 |
| TP13 | `REG_5V` | Pre-gate 5 V regulator output. | 5.0, 32.5 |
| TP14 | `REG_3V3` | Pre-gate 3.3 V regulator output. | 8.5, 32.5 |
| TP15 | `REG_3V2` | Pre-gate 3.2 V regulator output. | 12.0, 32.5 |
| TP16 | `MCU_5V` | Gated MCU_5V to J3 pin 1. | 16.0, 32.5 |
| TP17 | `LOGIC_3V3` | Gated LOGIC_3V3 to J3 pin 3. | 19.5, 32.5 |
| TP18 | `ACT_3V2` | Gated ACT_3V2 to J3 pin 4. | 29.0, 47.0 |
| TP19 | `NTC` | Analog thermistor node; depends on source and sensor. No forced logic levels. | 22.0, 41.0 |
| TP20 | `CC_DEFAULT_N` | CC-mode OUT1: high for default, low for 1.5/3 A attached advertisement. | 30.0, 32.5 |
| TP21 | `USB_HIGH_CURRENT` | Inverted mode control: low default, high for 1.5/3 A advertisement. | 34.0, 32.5 |
| TP22 | `USB_CHG` | USB supply after U13 current limiter, before charger. | 37.5, 32.5 |
| TP23 | `USB_PORT_ILIM` | USB current-limit programming node; do not drive externally. | 41.0, 32.5 |
| TP24 | `USB_LIMIT_FAULT_N` | Active-low U13 fault; pull-up to VBUS. Use voltage-rated probe. | 44.5, 32.5 |
| TP25 | `CC_3V3` | Dedicated CC supply, nominal 3.3 V with USB input. | 5.0, 39.0 |
| TP26 | `PGOOD_N` | Charger input-good status, active-low via VBUS LED path; not 3.3 V logic. | 8.0, 39.0 |
| TP27 | `CHARGE_N` | Charge status, active-low via VBUS LED path; read with charge conditions. | 14.0, 39.0 |
| TP28 | `VOLTAGES_OK` | Independent supervisor result; high after valid rails and delay. | 17.0, 39.0 |

<!-- END_GENERATED_TEST_POINT_TABLE -->

TP8 EF_UVLO, TP9 EF_ILIM, TP19 NTC and TP23 USB_PORT_ILIM are analog programming/sense nodes, not places to inject a logic level. TP10 EF_FAULT_N and TP24 USB_LIMIT_FAULT_N have pull-ups to their associated power domains; TP26/27 use VBUS indicator paths. “High” is not always 3.3 V. Only use voltage-rated probes, and evaluate status when that circuit is actually powered.

## 16. When to send it back instead of repairing it

Contact the factory/designer for a wrong/undocumented IC substitution, open internal trace/via, damaged pad, suspected hidden-joint defect, incorrect via-in-pad process, persistent rail error or multiple boards failing identically. Fine-pitch rework and protection changes belong to a qualified technician; repeated failures can be a design/fixture problem, not five bad ICs.

Send the exact C6/P4 release identification, serial/lot, both-side photographs, unmodified as-received evidence, setup/isolation diagram, source and load settings, ambient temperature, first failed step and a table of measurements with references. Attach scope traces with scales/trigger/probe setup, the factory's X-ray/electrical-test records and approved substitutions. State whether a real cell was connected and whether any rework occurred. Do not send a damaged battery through ordinary return shipping; coordinate the appropriate process with the responsible lab/supplier.

After an approved repair, repeat incoming inspection, unpowered checks, every power stage and the relevant charging/protection/integration tests. Keep all five board records separate. A completed worksheet reports only the conditions actually tested; battery, product/EMC and student-use approval are separate responsibilities.

Sources: [P.4 electrical review](P4_REVIEW_AND_TEST.md), [test-point map](../release_checks/TEST_POINTS.csv), [connector map](../release_checks/CONNECTOR_PIN_MAP.csv), [calculated screening](../electrical_screening.json), [DW01A](../datasheets/DW01A.pdf), [FS8205](../datasheets/FS8205_rev1_7.pdf), [TPS259530](../datasheets/TPS259530DSGR.pdf), [TPS63060](../datasheets/TPS63060DSCR.pdf), [TPS386000](../datasheets/TPS386000RGPR.pdf), [TPS22950](../datasheets/TPS22950YBHR.pdf), [103AT-2](../datasheets/103AT-2.pdf). This supplement does not alter CAD or previously issued manufacturing ZIPs.

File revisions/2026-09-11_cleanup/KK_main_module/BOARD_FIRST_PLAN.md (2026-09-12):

# Board-first sizing amendment

2026-09-10. The user has relaxed the original shell-first dimensions: make a comfortable, appropriately small handheld-toy board; the user will model its shell afterward. This supersedes the earlier enclosure-CAD-first gate, not the electrical, THT or feature requirements.

## Working proposal

Start component placement in a **50 W × 65 H × 1.6 mm PCB**, approximately R4 corners. This is an engineering trial size, not a fitted layout or finalized outline. Its 3250 mm² raw rectangular area is about **49% greater** than the previous 42 × 52 mm envelope. Use that space for controls, hand-solder access, sensible connectors and real component clearances.

A shell around this board might be roughly **55 × 72 mm in face dimensions**, depending on walls, mounting and connector protrusions. This is a packaging allowance, not a promised enclosure size. Thickness remains stack-dependent; the previous 19–20 mm ceiling is no longer treated as binding. Making the board wider/taller does not itself eliminate overlapping battery, power-board or socket heights.

Keep the 1.69-inch screen, nine gameplay inputs, compact S3/PSRAM, separate RODDY power PCB and battery, IR, speaker and haptics. Latest clarification: **all main-board mounting is through-hole for students; ESP32 uses a preassembled module with legs**. No factory-populated SMD parts directly on the main PCB. Recheck the trial footprint with real module/socket heights and hand-solder access. See [student-kit requirements](STUDENT_KIT_REQUIREMENTS.md). No separate sub-GHz hardware or automatic return to a large processor module.

## Placement priorities

1. Screen registration/window and nine-control geometry first. Test a real-size paper/button mock-up; a larger board is not evidence of comfortable controls by itself.
2. Reserve component and antenna keepouts, four practical mounting locations, power actuator/USB access, cable bends and soldering/tool access. Do not place mounting holes merely to make a symmetric drawing.
3. Arrange battery and power PCB against actual component height maps, keeping sharp leads and screw paths clear of the cell. Preserve RODDY's electrical architecture.
4. Compare direct GPIO against a THT button expander after selecting the exact compact S3 variant. Fit the full audio/IR/haptic circuits, not just their IC bodies.
5. Adjust the trial outline only where actual placement requires it. Report final dimensions and the reasons for meaningful growth before release. Do not add unused area by default.

## Shell handoff after board finalization

Provide the board outline and thickness, mounting-hole coordinates/diameters, control centers and actuation heights, display position and mounting envelope, connector mating/service clearances, IR window positions, RF/metal keepouts, speaker/motor pockets, battery/power-board placement and complete assembly depth limits. Export board 3D data and dimensioned drawings when geometry exists; none is claimed created by this amendment.

The exact display assembly, battery envelope and speaker/motor specifications remain necessary for a trustworthy final board. They do **not** require the user to model a shell first. Schematic/part qualification and trial placement can progress before enclosure modeling; do not fabricate unknown connector pinouts or component heights.

## Historical artifacts

The existing `mechanical/fit-study.svg` and `.pdf` show the **old 46 × 62 mm shell study**. Keep them for comparison only; they are not the new board outline. The earlier review's dimensional calculations remain valid for that old study, while its shell-first sequencing and dimensional limits are superseded here. Costs must be refreshed for final board dimensions/process.

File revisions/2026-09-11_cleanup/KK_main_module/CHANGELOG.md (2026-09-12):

# Design revision log — 2026-09-10

## Entire-kit sourcing and exact budget processor

Added ENTIRE_KIT_PARTS.md and scope CSV covering main electronics, sockets, harnesses, passive value pool, existing assembled power board, battery/NTC, enclosure components and kit preparation. User rejected XIAO, requested low-cost off-brand components, then supplied Teyleten Robot Amazon B0D47HBFDY. Inspected listing photos: FH4R2 chip marking and THT header rows; cross-checked 4 MB flash / 2 MB PSRAM against Espressif Table 1-1. Selected as prototype candidate, not qualified production assembly. Retained MCP23017 and selected soft elastomer Adafruit 3101 buttons. Withdrew XIAO-specific power/pin assumptions and its partial price subtotal; regulator selection reopened. Marked current-path, USB isolation, memory, sample/footprint, passive quantity and custom mechanical holds. No circuit, PCB, power-board or purchase changes.

## Budget-first sourcing amendment

User retained Amazon screens, removed the Mouser-only preference and rejected the Same Sky speaker on cost. Added BUDGET_PARTS_LIST.md: wired 1511 micro-speaker sample direction, generic wired ERM, complete block-level target budget and assembled-feel priorities. Clearly separated wholesale advertisements/user screen price from unquoted procurement targets, and kept THT, compact size, memory and supply qualification constraints. No purchasing, circuit changes or final BOM release.

## Latest component clarification

User approved a preassembled THT-pin regulator module on the main board, preserving the through-hole kit and separate reusable power module. User allows new speaker/motor selection and asked for a premium/cost-effective memory recommendation. Added COMPONENT_DECISIONS.md with a proposed 16 MB flash/8 MB PSRAM target, wired Same Sky speaker and SparkFun ERM shortlist, source links, price caveats and remaining qualification gates. Also recorded the preceding relaxation of display size/resolution and rejection of the expensive Adafruit option. Updated current requirements and precedence notices; no exact processor, regulator, audio driver, display or manufacturing BOM is released. No power-board or hardware files changed.

## Latest clarification: student through-hole kit is mandatory

User clarified that separating RODDY is specifically to enable student THT assembly, and the ESP32 must be on a module with legs. Withdrew the direct-mounted fine-pitch MCU/regulator island and any bare-SMT audio fallback. Added STUDENT_KIT_REQUIREMENTS.md and updated current brief/architecture/board-first plan/power interface and historical report/cost notices. All components directly mounted to the main PCB must be THT; only the already assembled ESP32 module, RODDY and other external assemblies carry their own internal SMT. Additional module exceptions are not assumed. Exact header GPIO, regulation, module/socket dimensions, sourcing and student-assembly verification remain open. No schematic, PCB or released BOM was changed or claimed qualified.

## Subsequent user amendment: board first

The user now prefers a comfortable, small handheld-toy board and will model the shell around the finalized board. This overrides the original shell-first sequence and fixed size limits described in the historical table below. Updated brief, README, architecture and review/cost notices; added BOARD_FIRST_PLAN.md. Proposed trial PCB: 50 × 65 × 1.6 mm, not a verified fit or final outline. Features, THT priorities and separate RODDY architecture remain unchanged. No actual PCB or electrical circuitry was changed in this amendment.

## Source precedence

Read the latest user-designated pasted request in full, plus the root `KC NOTES.txt`, `WIRING DIAGRAM.odt` and `Keychain_Kreatures_Main_PCB_Astra_Specification.docx`. Inspected the existing power PCB and production BOM for integration evidence. Instructions embedded in older specifications do not override the user's latest request or independently authorize unrelated changes.

The DOCX is useful engineering context, but its C3 and six-control baseline is superseded by the accepted compact S3/PSRAM and nine-input brief. Its detailed transistor/filter/resistor values are candidates, not verified circuit values.

## Changes

| Preliminary choice | Current treatment | Reason |
|---|---|---|
| Large S3-WROOM-N16R8 default | Withdrawn; compact module comparison, no exact selection yet | User's keychain-size constraint |
| Six buttons in source docs; eight in prior proposal | Nine: D-pad, A/B/X/Y, Function | Explicit final user layout |
| Optional sub-GHz | Removed from current hardware/I/O budget | User selected IR only; built-in ESP wireless retained |
| TCA9535 SMT expander default | Direct GPIO versus THT expander study | THT assembly and tight volume |
| DOCX MCP23008-E/P PDIP-18 | Remains a candidate to compare; not implicitly approved or rejected | Need compare interrupt/wake behavior, footprint and sourcing with PCF8574N/direct GPIO |
| PCF8574 used for IR in breadboard | Buttons only; direct RMT for IR | Pulse timing must not depend on I2C polling |
| MAX98357A integrated SMT default | Explicit fallback, not baseline; DIP audio qualification first | User's THT/repairability priority |
| NJM2073D | Existing-stock experiment; qualify HT82V739 DIP alternative | Obsolete listing and need for low idle consumption; neither replacement nor pinout finalized |
| Display resolution uncertain | 240 × 280 confirmed by user | Assembly dimensions/pinout still unknown |
| Display backlight always powered | Controlled backlight/peripheral shutdown planned | Week-of-pet-use target |
| PCB-first layout | Mechanical measurements/CAD first | Explicit latest sequencing constraint |
| RODDY convenient supply assumption | Preserve architecture; flag real interface/current gates | SYS_OUT unregulated, status levels, switch rating and mated connector heights |

DOCX candidates retained for schematic qualification: TSAL6200 emitter, TSOP38238 receiver, KSP2222ABU drivers, 1N5819 flyback diode, 3 V motor, THT tact switches and optional service header. No base resistor, IR current resistor, receiver filter or battery divider value is approved by this feasibility report. Their exact datasheets, current/thermal calculations and reset states must be reviewed during schematic design. Do not order from the inventory list as if it were a released BOM.

## Deliverables and limits

Delivered: current brief, architecture, feasibility/report, functional I/O counts, power-interface constraints, budgetary cost report, 1:1 SVG/PDF worksheet and source/change traceability. Archived old architecture/review/radio/pin-map files rather than discarding them. Existing user changes outside this folder were left untouched.

Verified: local document links, eight distinct expander buttons plus direct Function, 20 base direct MCU interface signals, framebuffer/runtime/fit arithmetic, successful SVG/PDF export and visual inspection. These checks do not verify hardware.

Still required after measured mechanics: source-qualified exact BOM, complete calculated circuits and schematic, final module GPIO mapping, actual screen interface, placed/routed PCB, ERC/DRC and manufacturing/assembly instructions. Physical runtime/RF/audio/thermal/reliability tests remain open. These are not claimed complete or factory-ready.

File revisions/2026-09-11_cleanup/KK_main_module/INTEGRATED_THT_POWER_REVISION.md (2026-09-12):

# Integrated through-hole power revision

**HISTORICAL — superseded by [revision B](component_review/REVISION_B.md):** user now wants the socketed ESP32-S3 SuperMini and a separate revised power board with regulation. Integrated charging is no longer a main-board requirement. No power-board edits have been made by this scope revision.

2026-09-10 — latest user direction; feasibility brief, NOT a verified circuit or fabrication release.

**Processor amendment:** replacement with another mini ESP32 is now authorized. See [replacement review](component_review/MINI_MODULE_REPLACEMENT.md) for the Nano-M candidate, separate VUSB/VIN nodes and the additional step-up requirement. No power circuit is released and no SMD rework is authorized.

**Follow-up component review:** [exact-parts register and unresolved power gates](component_review/README.md). The user permits choosing the battery after board design, subject to a defined electrical interface. Its old brand/model is no longer a fixed requirement. Twenty-three datasheets/drawings are archived, but the exact module power circuit and integrated charge/protection implementation still prevent a final component freeze.

## Requirements replacing the separate-power architecture

- Leave the existing `KK_power_module` project unchanged and exclude it from this toy's proposed architecture for now.
- Integrate battery charging, system power routing, protection and voltage regulation on the main PCB using actual through-hole parts. No separate regulator/charger breakout and no factory-populated SMD island on the main PCB.
- The permitted preassembled electronics are the screen and legged ESP32 module; the battery remains a separate, connectorized assembly. No student soldering to cell tabs. Speaker/motor remain electromechanical parts, not driver breakout boards.
- Retain ONE externally accessible USB-C connection for computer data and charging: the existing connector on the ESP32 module. Latest user clarification excludes an additional main-board USB receptacle. Take USB input power through a qualified module header connection to the main-board charger; do not connect USB 5 V directly to the battery. The battery-powered return path and isolation are not yet selected.
- Prioritize student solderability over the previous provisional 50 × 65 mm outline. No replacement dimensions are established yet; retain a comfortable handheld form where feasible.
- Keep existing non-power component candidates provisionally, but requalify rail voltage/current and mechanical fit. Prior kit CSV/report power rows and totals are superseded, not a purchasing release.

## Feasibility evidence, not selected purchase parts

**Lithium charging is possible with a true through-hole IC.** Analog Devices lists **LT1512CN8#PBF** and **LT1512IN8#PBF** in 8-lead PDIP. The LT1512 implements a switching constant-current/constant-voltage charger with a 2.7 V maximum specified minimum operating input, making nominal 5 V USB input a plausible starting point. This is not a complete USB charger, cell-protection system or charging safety controller by itself.

Sources: [manufacturer ordering table](https://www.analog.com/en/products/lt1512.html), [LT1512 datasheet](https://www.analog.com/media/en/technical-documentation/data-sheets/1512fc.pdf).

The IC requires magnetics, a diode, capacitors, sensing/feedback and a carefully laid out switching loop. Additional circuitry must address charge termination/restart, deeply discharged or absent cells, permitted charging temperature, fault timeout, input-current limits, reverse current and system load sharing. Do not adopt an old example circuit as a complete modern toy battery-safety design. Source pricing and a full THT magnetics/capacitor implementation remain open; this approach is not established as cheaper than an SMD module.

**Regulation remains a separate design task.** The previously discussed MCP1826S-3302E/AB is a THT linear-regulator candidate, not a buck-boost replacement: heat and low-battery headroom still apply. Integrating charging does not automatically supply regulated 3.3 V. A THT switching alternative must be sized for the actual load and sleep-current target.

## One-port USB gate

With the module's existing port, USB data stays entirely on the module; the main PCB does NOT need header access to GPIO19/D− or GPIO20/D+. The main-board charger instead needs USB power and ground through the module header. Source for native USB: [Espressif schematic checklist](https://docs.espressif.com/projects/esp-hardware-design-guidelines/en/latest/esp32s3/schematic-checklist.html).

The [NOLOGO reference schematic](https://wiki.nologo.tech/assets/img/esp32/esp32s3supermini/1.png) shows USB VBUS tied to H2 pin 1 and an onboard TP4054 charger, plus a BAT-to-VBUS diode. This establishes a plausible header-powered charging architecture, not exact compatibility: the delivered Teyleten board has not been matched to this schematic. The illustrated battery diode also means isolation must not be assumed. Check the real board's continuity, module current/thermal limits and reverse-current behavior before wiring. Leave its battery pads unused when using the separate main-board charger; do not parallel chargers.

Do not assume that taking 5 V from a SuperMini header is isolated or safe on battery, or that its onboard charger can operate in parallel with the proposed charger. Resolve the exact module schematic, reverse-current paths, VBUS sensing, reset/boot recovery and powered-off states before selecting the USB topology. No soldering to hidden SMD pads is permitted. A module replacement needs an explicit selection decision, not a silent swap.

No additional USB-C receptacle is planned. Review the existing module's USB-C CC termination and ESD implementation, plus negotiated/advertised input-current limits for the combined toy and charger. A fixed 500 mA charging setting is not a universal entitlement to draw that much from every computer port, especially before enumeration.

## Battery and release gates

- Qualify the exact cell/pack datasheet, charge voltage/current, temperature limits, connector polarity and protection. A protected pack is a candidate within the separate-battery allowance, not evidence that the current pack is protected. Pack protection does not replace correct charging.
- Complete independent battery fault protection and a fail-safe charging shutdown strategy; do not depend solely on downloadable game code or normal ESP32 execution for battery safety.
- Establish whole-system operating/peak current, USB load priority, thermal behavior and low-battery shutdown. The old power board's switch rating no longer constrains the new design, but every replacement path component must be rated.
- Bench-test charging alone and with system load, battery/USB insertion and removal, low/absent battery, temperature faults, output shorts, charge termination and firmware failure. Use current-limited equipment and qualified battery review before student trials.
- Audit every exact BOM package, footprint and assembly operation for THT compliance. Size the board only after these blocks are credible.

Current result: the requirement is technically plausible and a real DIP charger exists. No complete all-THT power circuit, final BOM, main-board schematic, routed PCB or safety qualification has been completed.

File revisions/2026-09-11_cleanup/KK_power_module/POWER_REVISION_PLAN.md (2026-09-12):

# Charging-only power-module revision — pre-schematic assessment

2026-09-11. Status: proposed engineering direction, not a released circuit or purchasing BOM.

## Scope fixed by the user

- External USB-C is power/charging only. No USB data routing, internal USB cable, or USB communication circuitry is to be added.
- Keep the C.5 main PCB unchanged. Its four-pin JST-XH input is authoritative: 1 = MCU_5V, 2 = GND, 3 = LOGIC_3V3, 4 = ACT_3V2.
- Keep charging, cell protection and conversion on the separate power module. The existing power module is an SMT assembly; this does not add student-soldered SMT to the main board.
- Physical battery selection remains deferred, but electrical battery requirements must be established before releasing the power design.
- This document lists changes before altering the schematic/PCB. Neither has been altered in this assessment.

## Existing design and newly identified constraint

The existing MCP73871-2CCI/ML charger feeds a switched, unregulated two-pin SYS_OUT. It does not generate any of the three regulated rails. USB data pins are intentionally unconnected. SEL is low, PROG2 high, and PROG1 has 3.3 kohm: nominal USB input ceiling 500 mA and charge setting about 303 mA, subject to system demand and thermal regulation.

**A regulator addition alone is not sufficient qualification.** MCP73871 datasheet section 6.1.1.7 recommends system load no greater than the lesser of 1 A and the selected cell's discharge capability. Its internal battery-to-system diode is described as supporting up to 2 A, with thermal shutdown possible. That is not a blanket 2 A continuous design rating. The existing C&K JS102011SAQN series switch is rated 0.3 A at 6 VDC and must not remain the unqualified whole-system current path.

The charger need not automatically be replaced: retaining it depends on demonstrating a load envelope within its recommended operating/thermal limits. A higher-capacity power-path design is the alternative if that cannot be demonstrated. Do not bypass the charger power path by simply moving the load onto the cell; that changes charge termination and protection behavior.

## Preliminary converter sizing envelope

These are deliberately labeled **engineering screening allowances**, not measured consumption, final guaranteed rail ratings, or a statement that all loads draw this current continuously.

| Output | Screening allowance | Power | Loads |
|---|---:|---:|---|
| 5.0 V | 0.60 A | 3.00 W | SuperMini including its onboard regulator; RGB common anode |
| 3.3 V | 0.40 A | 1.32 W | Display, SD, expander, IR and RGB-driver logic |
| 3.2 V | 0.50 A | 1.60 W | Audio and motor, including transient allowance |
| Simultaneous screening total | — | 5.92 W | Not a measured operating point |

At a hypothetical 3.0 V converter input and 85% efficiency, this envelope requires 5.92/(3.0*0.85) = **2.32 A**, before other losses. It therefore cannot be claimed compatible with the old charger path. Even a 3 W actual load would require about 1.18 A under those assumptions. Build a realistic simultaneous load model before deciding how much of the screening allowance must be supported.

The selected motor document specifies 80 mA maximum rated current and 120 mA maximum starting current under its stated conditions. Display-module current, SD-card write peaks, delivered SuperMini behavior and usable audio volume remain sample-dependent. Converter current-limit numbers must not be substituted for guaranteed output-current capability.

## Proposed changes, in order

1. **Close the load budget and source path first.** Check simultaneous operation, startup/inrush, low-battery current, charger loss and battery supplementation. Determine whether the existing charger can be retained or needs a higher-capacity replacement. Do not assume charging continues at full rate during gameplay.
2. **Add regulated outputs.** Use converters that regulate across both battery-powered SYS and USB-powered SYS. A plain boost cannot regulate downward; a plain LDO/buck cannot maintain a rail when SYS falls below the necessary headroom. Compare direct per-rail buck-boost against a shared intermediate rail for cost, efficiency, fault behavior and noise.
3. **Replace the load-current role of SW1.** Prefer retaining its physical control function while switching converter enables or a properly rated electronic disconnect. Off must stop the toy while leaving charging available. Account for quiescent drain and unintended power through signal/status paths.
4. **Add the four-pin regulated output and defined harness.** Match the main-board JST-XH pin numbering; include mating housings, contacts, wire gauge, labels and a continuity test. Keep any reusable raw SYS output distinctly labeled and mechanically incompatible where practical. No USB data pins are needed.
5. **Coordinate startup, brownout and shutdown.** Common enable alone does not prove safe sequencing. The MCU's internal 3.3 V regulator and external logic supply can rise/fall differently. Verify I/O injection limits, discharge paths, rail faults and reset behavior without assuming an unavailable MCU reset connection on this four-wire interface.
6. **Review cell protection and temperature sensing.** Check DW01A/FS8205 current/thermal behavior, connector limits and pack polarity. Preserve BAT_NEG versus protected GND separation. Set normal low-battery shutdown above emergency protection cutoff, with hysteresis to avoid restart cycling. Final thresholds/charge current must agree with the approved cell.
7. **Keep USB power rules explicit.** Leaving data disconnected does not authorize drawing arbitrary current from a computer or USB-C supply. Retain conservative operation or add appropriate source-current detection/control if more input power is required. No USB-PD voltage negotiation is assumed.
8. **Add filtering and accessible test points.** Include VBUS, battery positive, protected ground, raw SYS, all regulated rails, enable/power-good and temperature-sense points. Clearly distinguish raw battery-negative probes. Size bulk capacitance and soft start together; do not rely on capacitors to sustain an undersized source indefinitely.
9. **Rework layout only after the above circuit choices.** Keep switcher loops short, provide charger/converter thermal copper, keep feedback away from switching nodes and protect connector access. The old approximately 30 x 40 mm board size is not yet guaranteed for the revised assembly.
10. **Verify and qualify.** Repeat ERC/DRC/parity, then test with a current-limited source and battery simulator before a cell. Cover no battery, depleted battery, source removal, charging plus gameplay, motor startup, audio noise, SD writes, shutdown, reverse feeding and temperature.

## Regulator shortlist — not yet a selected BOM

- **TI TPS63070**, adjustable buck-boost: candidate for 5 V, with broad input range. Its advertised 2 A boost output is conditional on 4 V input/5 V output; verify low-input current and layout/thermal performance for this design.
- **TI TPS63802**, adjustable buck-boost: candidate for separate 3.3 V and 3.2 V outputs. Its 5.5 V maximum recommended input needs review against the complete SYS and transient envelope. Evaluate PWM/PFM behavior, ripple and possible reverse-current operation. Datasheet protections do not make external-source backfeeding safe by assumption.

A 3.2 V output must have a defined total tolerance/ripple/overshoot budget: the motor document specifies a 3.3 V maximum operating voltage. Shared nominal enables and nominal resistor values do not close these issues. No exact inductors, compensation/support passives or final footprints are selected yet.

## Unchanged-design evidence

At assessment time, native KiCad checks reported zero ERC violations, zero DRC violations, zero open connections and zero schematic/PCB parity issues under the existing project settings. These checks do not validate the new power requirements.

SHA-256 of unchanged source files:

- Power schematic: `8a544722583fc994f665f53255b7053021f6a8add73af85a513a50f3e8a08506`
- Power PCB: `36233b1973132dd5006cd06d59c546c395f8d20f4acbd6d0e8d46eba6b151277`
- C.5 main PCB: `b840262c37afad89ec5307568ace5b6acb4406f89c44c91f1579771642a89003`

## References

- [Microchip MCP73871 datasheet, particularly section 6.1.1.7](https://ww1.microchip.com/downloads/aemDocuments/documents/APID/ProductDocuments/DataSheets/MCP73871-Data-Sheet-DS20002090F.pdf)
- [C&K JS switch datasheet](https://www.ckswitches.com/media/1422/js.pdf)
- [TI TPS63070 datasheet](https://www.ti.com/lit/ds/symlink/tps63070.pdf)
- [TI TPS63802 datasheet](https://www.ti.com/lit/ds/symlink/tps63802.pdf)
- [Selected motor manufacturer specification](../KK_main_module/component_review/datasheets/motor.pdf)
- [Current main-board circuit review](../KK_main_module/C5_relayout/CIRCUIT_REVIEW.md)

No revised manufacturing files, new circuit performance claims, hardware tests or battery approval are issued by this assessment.

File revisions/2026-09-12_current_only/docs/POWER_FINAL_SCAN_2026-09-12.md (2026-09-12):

# Power module P.2 — final artwork and manufacturer review

**Historical P.2 scan.** Current C.6/P.3 source hashes and packages are in [the release index](C6_P3_RELEASE_INDEX.json). Use [P.3 assembly/bench instructions](../KK_power_module/P3_matching_stack/assembly/P3_REVIEW_AND_TEST.md); old package links and coordinates below describe the archived revision.

## Result

Fresh KiCad checks after adding the logos: **0 DRC violations, 0 unconnected items, 0 schematic/PCB mismatches, 0 reported ERC violations.** The native audit confirms 108 fitted parts, 28 rear test pads, 3,515 track segments and 260 vias. The main board was not modified.

Pad numbers, nets, component values, footprint identities, the four-pin main-board power interface and battery-return isolation were checked. An exact comparison of pad/track/via geometry and filled copper before and after the artwork change confirms that the electrical layout is unchanged. This preserves the earlier supply-path review; it does not replace measured testing.

The KiCad and standard open-source-hardware logos are now on the **rear silkscreen**, in the open area above the test pads. They are board-only artwork, excluded from the BOM and placement file. They are not certification marks. The stock OSHW artwork needed the same no-courtyard metadata used by the KiCad logo because it is not a physical component; no electrical/clearance rule was disabled and no DRC finding was excluded.

## Test pads are present

There are **28 labeled, 1.5 mm rear copper test pads**, exposed through soldermask. The package includes their signal names and coordinates in `TEST_POINTS.csv`, a test-pad guide, and a rear assembly drawing. They are bare probe pads, not fitted pins. Ground reference is **TP4 (GND)**. **TP3 (BAT_NEG) is the unprotected cell return, not an interchangeable scope ground.** Use suitable isolated/differential measurements where needed; ordinary grounded equipment can accidentally bypass the protection return.

The pads cover battery/USB input, both sides of the protection/power path, all regulated and switched output rails, charger and thermistor signals, USB-current selection, regulator enables, power-good and fault signals. Do not short adjacent pads with a probe; never conduct fault testing by shorting a real battery.

## What to send

Use the new dated review ZIP, not the previous unmarked-artwork ZIP. It includes four-layer Gerbers, mask/silkscreen/paste/outline layers, separate plated/non-plated drills and maps, IPC-D-356 electrical-test netlist, grouped five-board BOM, native placement CSV, schematic PDF, assembly/copper drawings, test-pad documentation, source CAD/local libraries, datasheets, native checks and file hashes.

This is a **five-unit engineering/DFM review request**. Ask the manufacturer to confirm the mandatory items below before accepting a fabrication/assembly quote. No order has been placed.

## Still open — do not mistake CAD checks for qualification

- Fine-pitch assembly acceptance, including the 0.4 mm-pitch TPS22950 YBH WCSP, and exact BOM availability/substitution approval.
- **Filled, capped and planarized via-in-pad processing.** The CAD has tenting defaults; tenting alone is not an acceptable substitute for the required component-pad via process. The written fabrication requirements must be acknowledged, not inferred from a default upload form.
- Confirmation of the fabricator's four-layer stackup, copper weights, drill plating and stencil/hidden-joint inspection process.
- Actual battery choice, charge/discharge ratings, thermistor attachment, harness crimping/polarity and physical fit.
- Current-limited first-power-up, charging/thermal/fault testing, rail rise/fall sequencing and GPIO back-power checks with the actual main board. Output load targets are not measured ratings.
- Universal USB-host behavior is not established: default USB-A charging is deliberately slow, with no USB enumeration/suspend or BC1.2 implementation. ESP32 USB and external main-board power must not be used simultaneously until qualified.

The detailed electrical review and first-power-up procedure are included as `READ_FIRST_REVIEW_AND_TEST.md`. These are test samples, not finished consumer or student-distribution units.

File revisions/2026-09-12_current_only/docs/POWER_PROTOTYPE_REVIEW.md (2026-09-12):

# P.2 power module — five-sample engineering review

**Historical P.2 report.** For the current 96 × 105 mm P.3 stack, coordinates, assembly and first-power-up, use [P.3 review](../KK_power_module/P3_matching_stack/assembly/P3_REVIEW_AND_TEST.md). The original P.2 findings below are preserved, not current build instructions.

This report covers the 50 × 50 mm, four-layer power board, not a new revision of the main board. **Final native results: zero DRC violations, zero unconnected items, zero schematic/PCB mismatches, and zero reported ERC violations.** The checked board has 3,515 track segments and 260 vias. It is an engineering prototype, not a proven consumer-product or battery-safety release. The accompanying verification files record the exact reports and CAD hashes. An assembler must approve the fabrication process and exact component supply before ordering populated samples.

## What this pass changed

- Completed and repaired the unfinished signal routing in an isolated working copy; retained the manually placed converter hot loops and wide output paths.
- Removed shorted/redundant signal routes, added local IC pin escapes and ground stitching, and refilled all planes.
- Added a locked **1.5 mm SYS_SW bridge on In1.Cu**, connecting the eFuse source via bank to the left converter input bank. This avoids depending on a thin signal trace across a split supply pour. In1 remains predominantly ground, but is not an uninterrupted ground-only plane.
- Added a 0.6 mm local supply connection to C8. An independent filled-plane check confirms the eFuse output, all converter input banks and C8 remain connected when long thin supply traces are excluded. Low-current monitor/test-point branches are intentionally excluded from that width screen; it is not a thermal simulation.
- Moved rear debug pads clear of component escapes: TP10 EF_FAULT_N to (44,40), TP19 NTC to (22,41), and TP18 ACT_3V2 to (29,47) mm. Coordinates are native KiCad board coordinates, viewed from the front.
- Preserved all 108 fitted components, 28 bare debug pads, four mounting holes, rounded outline, connector pin assignments, and the current main-board files.

No protection, supervision or USB-current control was removed simply to reduce the IC count. The three independently regulated rails and existing main-board interface remain. A materially simpler architecture would require another design revision and renewed electrical review.

## Electrical review and limits

| Function | Reviewed design | Qualification still needed |
|---|---|---|
| Battery charging | BQ24075**T**RGTR; about 0.303 A nominal charge current, screened 0.271–0.332 A | Selected cell's charge limit, thermal rise, charge termination, source/load interaction |
| Temperature interlock | Semitec 103AT-2, 10 kΩ, with R74/R75 bias network; nominal thresholds about 4.8°C and 40.0°C; open/short inhibits charging | Bonded thermistor thermal lag and actual pack limits; screened corners extend roughly 2.9–42.2°C |
| USB-C input | TUSB320LAI GPIO sink detects advertised current; dedicated 3.3 V CC supply; high-current mode only for adequate advertisement | Attach/unplug transients, weak chargers, cable behavior, total input current |
| USB-A/default input | TPS22950**YBHR**, base variant, nominal 50 mA limiter; datasheet range approximately 34–66 mA, plus upstream loads | Startup and host behavior. No USB enumeration, suspend detection or BC1.2; not a claim of universal USB compliance |
| USB-C charge-path limit | BQ24075T programmed around 1.23 A, screened maximum about 1.32 A | Full toy load plus charging may exceed input budget; the battery may supplement |
| Battery protection | DW01A, three parallel FS8205 dual-FET banks, 4 A fuse; separate protected return | Pack, fuse and protection-trip coordination; short-circuit recovery and FET heating |
| System cutoff | TPS259530, nominal approximately 3.27 A limit; SYS_RAW UVLO about 3.38 V rising / 3.10 V falling | Threshold tolerance, loaded battery sag, startup and hysteresis |
| Rails | TPS63060 converters: MCU_5V, LOGIC_3V3 and ACT_3V2; output gates and independent voltage supervision | Regulation, ripple, startup/stop sequencing, transients and thermal margin into the actual toy |

The calculation sheet is a screening exercise, not a simulation or measurement. Working load targets are 5 V at 0.6 A, 3.3 V at 0.4 A and 3.2 V at 0.5 A (5.92 W combined). These are **not validated output ratings**. At low battery voltage the combined load can require roughly 2.5 A; test the complete current path, not just each converter separately. Confirm effective ceramic capacitance under DC bias and the board house's actual copper stackup.

The independent voltage monitor is retained: a converter's power-good behavior is not a substitute for verifying all three output voltages. Equal output-gate timing capacitors do not prove safe sequencing between the ESP32 module's onboard regulator and the external logic rail. Scope startup/shutdown and measure GPIO back-powering before attaching a populated main board. Exact SuperMini module revisions may differ.

Manufacturer references: [BQ24075T](https://www.ti.com/lit/ds/symlink/bq24075t.pdf), [TUSB320LAI](https://www.ti.com/lit/ds/symlink/tusb320lai.pdf), [TPS22950](https://www.ti.com/lit/ds/symlink/tps22950.pdf), [TPS63060](https://www.ti.com/lit/ds/symlink/tps63060.pdf). Other selected manufacturer datasheets are retained with the CAD project and linked in the BOM. Availability, permitted substitutions and assembler inventory are not yet approved.

## Connector and assembly instructions

| Connector | Pin assignments | Important restriction |
|---|---|---|
| J1 USB-C | Charging input only; data/SBU pins deliberately NC | Does not communicate with the ESP32 |
| J2 battery, JST VH 2-pin | 1 CELL_PLUS; 2 BAT_NEG | **BAT_NEG is not system GND. Never bypass the low-side protection by bonding them externally.** |
| J3 to main-board J1, JST XH 4-pin | 1 MCU_5V; 2 GND; 3 LOGIC_3V3; 4 ACT_3V2 | Wire pin-for-pin. Front view left-to-right is 3V2, 3V3, GND, 5V because the header is rotated |
| J4 thermistor, JST PH 2-pin | 1 NTC; 2 GND | Bond and electrically insulate the thermistor against the cell; do not substitute a fixed resistor for normal use |

Use the native assembly drawings, reference designators and pad-1 marks. The placement CSV explicitly uses board coordinates with Y increasing downward; it is a reference table, **not an unreviewed machine-ready centroid conversion**. Have the assembler verify rotation and polarity for every IC, FET, diode, connector and switch against its actual reel/part drawing. Bare TP pads and mounting holes are not fitted parts. All fitted electrical components are on the front; test pads are on the rear. The power board is factory SMT assembled, not a student through-hole soldering exercise.

`BOM_AND_PLACEMENT.csv` uses the down-positive CAD coordinates described above. `POSITIONS_NATIVE.csv` is KiCad's native mm placement export (Y values are negative for this board origin); do not mix these coordinate conventions. Both include all 108 fitted parts. THT/mixed connector and switch operations need separate assembler handling. Drawings separate silkscreen labels from component-body/fab references to avoid double-printed text; bottom assembly views are mirrored for viewing from the back. Copper-layer drawings are viewed from the front.

Suggested mating hardware for each power-to-main harness: two JST XHP-4 housings and eight SXH-001T-P0.6 contacts with 22 AWG wire. Battery mating housing VHR-2N with two SVH-21T-P1.1 contacts and 20 AWG wire, subject to the selected battery's connector/polarity and insulation diameter. Thermistor mating housing PHR-2 with two SPH-002T-P0.5S contacts and suitable 28 AWG insulated leads. Check the current JST terminal drawing, crimp tooling, wire and insulation ranges before assembly. Matching pitch alone is not sufficient; do not mate unrelated connector families.

Battery selection is still open: conventional **1S, 4.2 V maximum** Li-ion/LiPo, provisionally at least 4 A continuous discharge capability and at least 0.34 A permitted charging, with documented temperature limits. Capacity, physical fit and protection coordination must be finalized before testing a real cell. The board does not establish safe reverse-battery behavior; verify the harness polarity before connecting it. Shell, mounting screw lengths and standoffs require physical fit checks. A 3D rendering is not dimensional certification; some stock models remain unavailable.

## Fabrication/assembly acceptance gate

Request **five engineering samples**, four copper layers, 50 × 50 mm, 1.6 mm nominal thickness, R3 corners and four 2.2 mm M2 clearance holes. Confirm layer order F.Cu / In1.Cu / In2.Cu / B.Cu, finished copper weights, drill plating and soldermask registration with the manufacturer. The CAD rules permit 0.15 mm traces and 0.20 mm drilled vias; some package clearances are fine-pitch exceptions to wider routing clearances.

The TPS22950 YBH footprint is a 0.4 mm-pitch six-ball WCSP with approximately 0.2 mm pads. Other small packages include 0.4/0.5 mm-pitch QFNs. **Do not substitute TPS22950C/L or another package without reviewing both behavior and footprint.** The selected base device supports the low USB-A current-limit setting.

The board has vias in surface-mount pads, including small parts and thermal pads. The accompanying CAD audit lists them. Ask for **filled, capped, planarized via-in-pad construction**, appropriate fine-pitch finish/stencil processing and assembler approval of the WCSP. Simple via tenting is not equivalent. Confirm whether X-ray inspection is available for hidden joints. If these processes exceed the five-board budget, stop before ordering: relocating vias or changing the current-limiter package is a layout/circuit revision, not a fabrication checkbox.

Ask the assembler to approve the BOM, substitutions, stencil apertures, centroid conversion, polarity and THT secondary operations. Do not send an old FACTORY.zip or a two-layer stackup. The current package is a DFM/engineering review package, not authorization for unreviewed substitutions or mass production.

## Current-limited first-power-up

1. Inspect under magnification before power. Verify IC orientation, hidden-joint inspection results, polarity, solder bridges and connector pin numbering. Check rail-to-ground resistance and confirm BAT_NEG is not accidentally hard-bonded to GND. Investigate unexpected readings rather than assuming a universal resistance threshold.
2. Keep the real cell and main board disconnected. Use a current-limited battery simulator at J2, positive to pin 1 and negative to pin 2. Begin at 3.7 V with the toy switched off and a low current limit (about 50 mA); verify expected idle behavior before increasing the limit. Protection may need its documented recovery sequence; do not bypass it.
3. Switch on with an appropriate bounded current limit. Measure all three J3 outputs before attaching loads. Target nominal 5.0/3.3/3.2 V; investigate deviations beyond ±5%, and reject actuator transients above the attached components' maximum (3.3 V target ceiling for this design). Measure ripple and overshoot with short probe grounds. A current limit that is too low can itself cause startup cycling.
4. Increase dummy loads gradually, first separately and then together toward the screening targets. Record input current, rail voltage, ripple and converter/charger/FET/fuse temperatures at high and low battery voltage. Test UVLO and recovery using the simulator; never deliberately overdischarge a real cell.
5. For charging tests with USB attached, use a **sink-capable/bidirectional battery emulator** or a qualified cell with its bonded NTC. An ordinary bench supply usually cannot absorb charging current and must not be used as a battery substitute while the charger is active.
6. Check USB-A/default input limit, USB-C default/1.5 A/3 A advertisements, attach/unplug, weak-source behavior and absence of damaging reverse feed. Confirm the default path does not request high current. Measure upstream CC/LED current as well as the limiter current. This does not establish USB certification.
7. Verify charging current, termination, NTC open/short inhibition and measured temperature thresholds using controlled test equipment. Check low-battery cutoff, current-limit behavior and recovery with a current-limited simulator, not uncontrolled shorting of a cell.
8. Scope rail rise/fall ordering and GPIO leakage/back-power behavior using the actual ESP32 module and main-board load model before full connection. Then test Wi-Fi bursts, SD writes, motor starts, IR, RGB and audio together. Stop for overheating, oscillation, unexpected current or out-of-range voltages.
9. Do **not** connect the ESP32's USB power and external SYS_IN simultaneously until reverse-feed paths are qualified. Charging USB on the power board is separate and has no data path. Update firmware over Wi-Fi, or program the removable ESP32 with the main-board supply disconnected.

Record results for all five serial-numbered boards. Retain one as the comparison unit. Successful ERC/DRC and routing do not replace these measurements or toy/product safety and EMC review. Do not distribute the samples as finished student products.

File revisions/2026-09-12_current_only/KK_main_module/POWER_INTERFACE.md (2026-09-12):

# Main module connection to the existing power board

**Current revision B:** the user has reauthorized the separate power board and a future revision adding suitable regulation, with possible USB data. Focus now is the SuperMini main PCB with SYS_IN. See the [proposed electrical contract](component_review/REVISION_B.md). The old board has not been modified or requalified; its SYS_OUT must not be assumed to equal regulated SYS_IN. The extracted facts below describe the existing board, not a released new interface. Older paragraphs requiring an unchanged power architecture or a main-board USB connector are superseded.

Extracted from the current PCB pad/net assignments on 2026-09-09. Connector pin numbers are authoritative; wire colors are not.

| Existing power-board connector | Pin | Net | Main-board treatment |
|---|---|---|---|
| J3 SYS OUT | 1 | /SYS_OUT | Main input to local 3.3 V regulator |
| J3 SYS OUT | 2 | GND | Main ground |
| J5 STATUS | 1 | /PG | Conditioned active-low power-good input |
| J5 STATUS | 2 | /STAT1{slash}LBO | Conditioned status input |
| J5 STATUS | 3 | /STAT2 | Conditioned status input |
| J5 STATUS | 4 | GND | Signal reference |
| J5 STATUS | 5 | /VBAT | Battery sense only through a reviewed sensing circuit |
| J4 BAT_TEMP | 1 | /THERM | Battery thermistor; keep with battery/power assembly |
| J4 BAT_TEMP | 2 | GND | Thermistor return |
| J2 BATTERY | 1 | /VBAT | Remains connected to battery positive |
| J2 BATTERY | 2 | /BAT_NEG | Remains connected to battery negative |

Do not bridge BAT_NEG to main-board GND: they are separated by the battery-protection circuit. The main board must receive power from J3, not directly from J2.

SW1 on the power board connects /SYS to /SYS_OUT. It already performs the system power disconnect. A main-board wake/sleep button has a different role from this hard switch.

The notes' older switch arrangement is superseded by their updated ODT arrangement and the actual PCB. The ODT's generic 3.0–4.2 V charger-output estimate does not cover the MCP73871 system output when USB supplies the load.

The PCB ties U1 SEL low and PROG2 to VBUS, selecting 500 mA USB mode. R5 is 3.3 kOhm on PROG1, corresponding to a nominal 303 mA programmed fast-charge setting, subject to available supply and thermal conditions. The system load takes priority and charging is reduced as needed; the battery can supplement system demand. These are circuit-derived expectations, not measured ratings. See [MCP73871 datasheet, sections 3 and 5](https://ww1.microchip.com/downloads/aemDocuments/documents/APID/ProductDocuments/DataSheets/MCP73871-Data-Sheet-DS20002090F.pdf).

The three status signals have VBUS-fed LED/resistor branches on the power board. Their open-drain designation does not by itself make these populated nets safe for direct ESP32 connection. Select a buffer/level interface with appropriate input-voltage and powered-off tolerance, and verify both USB-on/main-off and battery-only states. Never rely on the MCU's protection diodes to absorb current.

Battery measurement must also be safe with the main switch off. A permanent resistor divider may inject current into an unpowered ADC or drain the cell through the sensing path. Prefer a switched divider with default-off isolation or a properly reviewed fuel-gauge interface. Voltage-only battery percentage is an estimate under load, not a fuel-gauge measurement.
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

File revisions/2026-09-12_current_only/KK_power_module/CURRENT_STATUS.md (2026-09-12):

# Power board — current P.3 matching stack

Open [P3_matching_stack/KK_power_module.kicad_pro](P3_matching_stack/KK_power_module.kicad_pro). P2_compact is historical baseline evidence.

P.3 is **96 × 105 × 1.6 mm, four layers, R4 corners**, matching C.6 mounting holes. The routed power core was rigidly moved without changing electrical pad/net or trace/via geometry. It has 14 ICs, 108 fitted positions, 28 bare rear debug pads, 3,515 segments and 260 vias. All fitted model links resolve; real connector/stack fit remains unqualified.
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

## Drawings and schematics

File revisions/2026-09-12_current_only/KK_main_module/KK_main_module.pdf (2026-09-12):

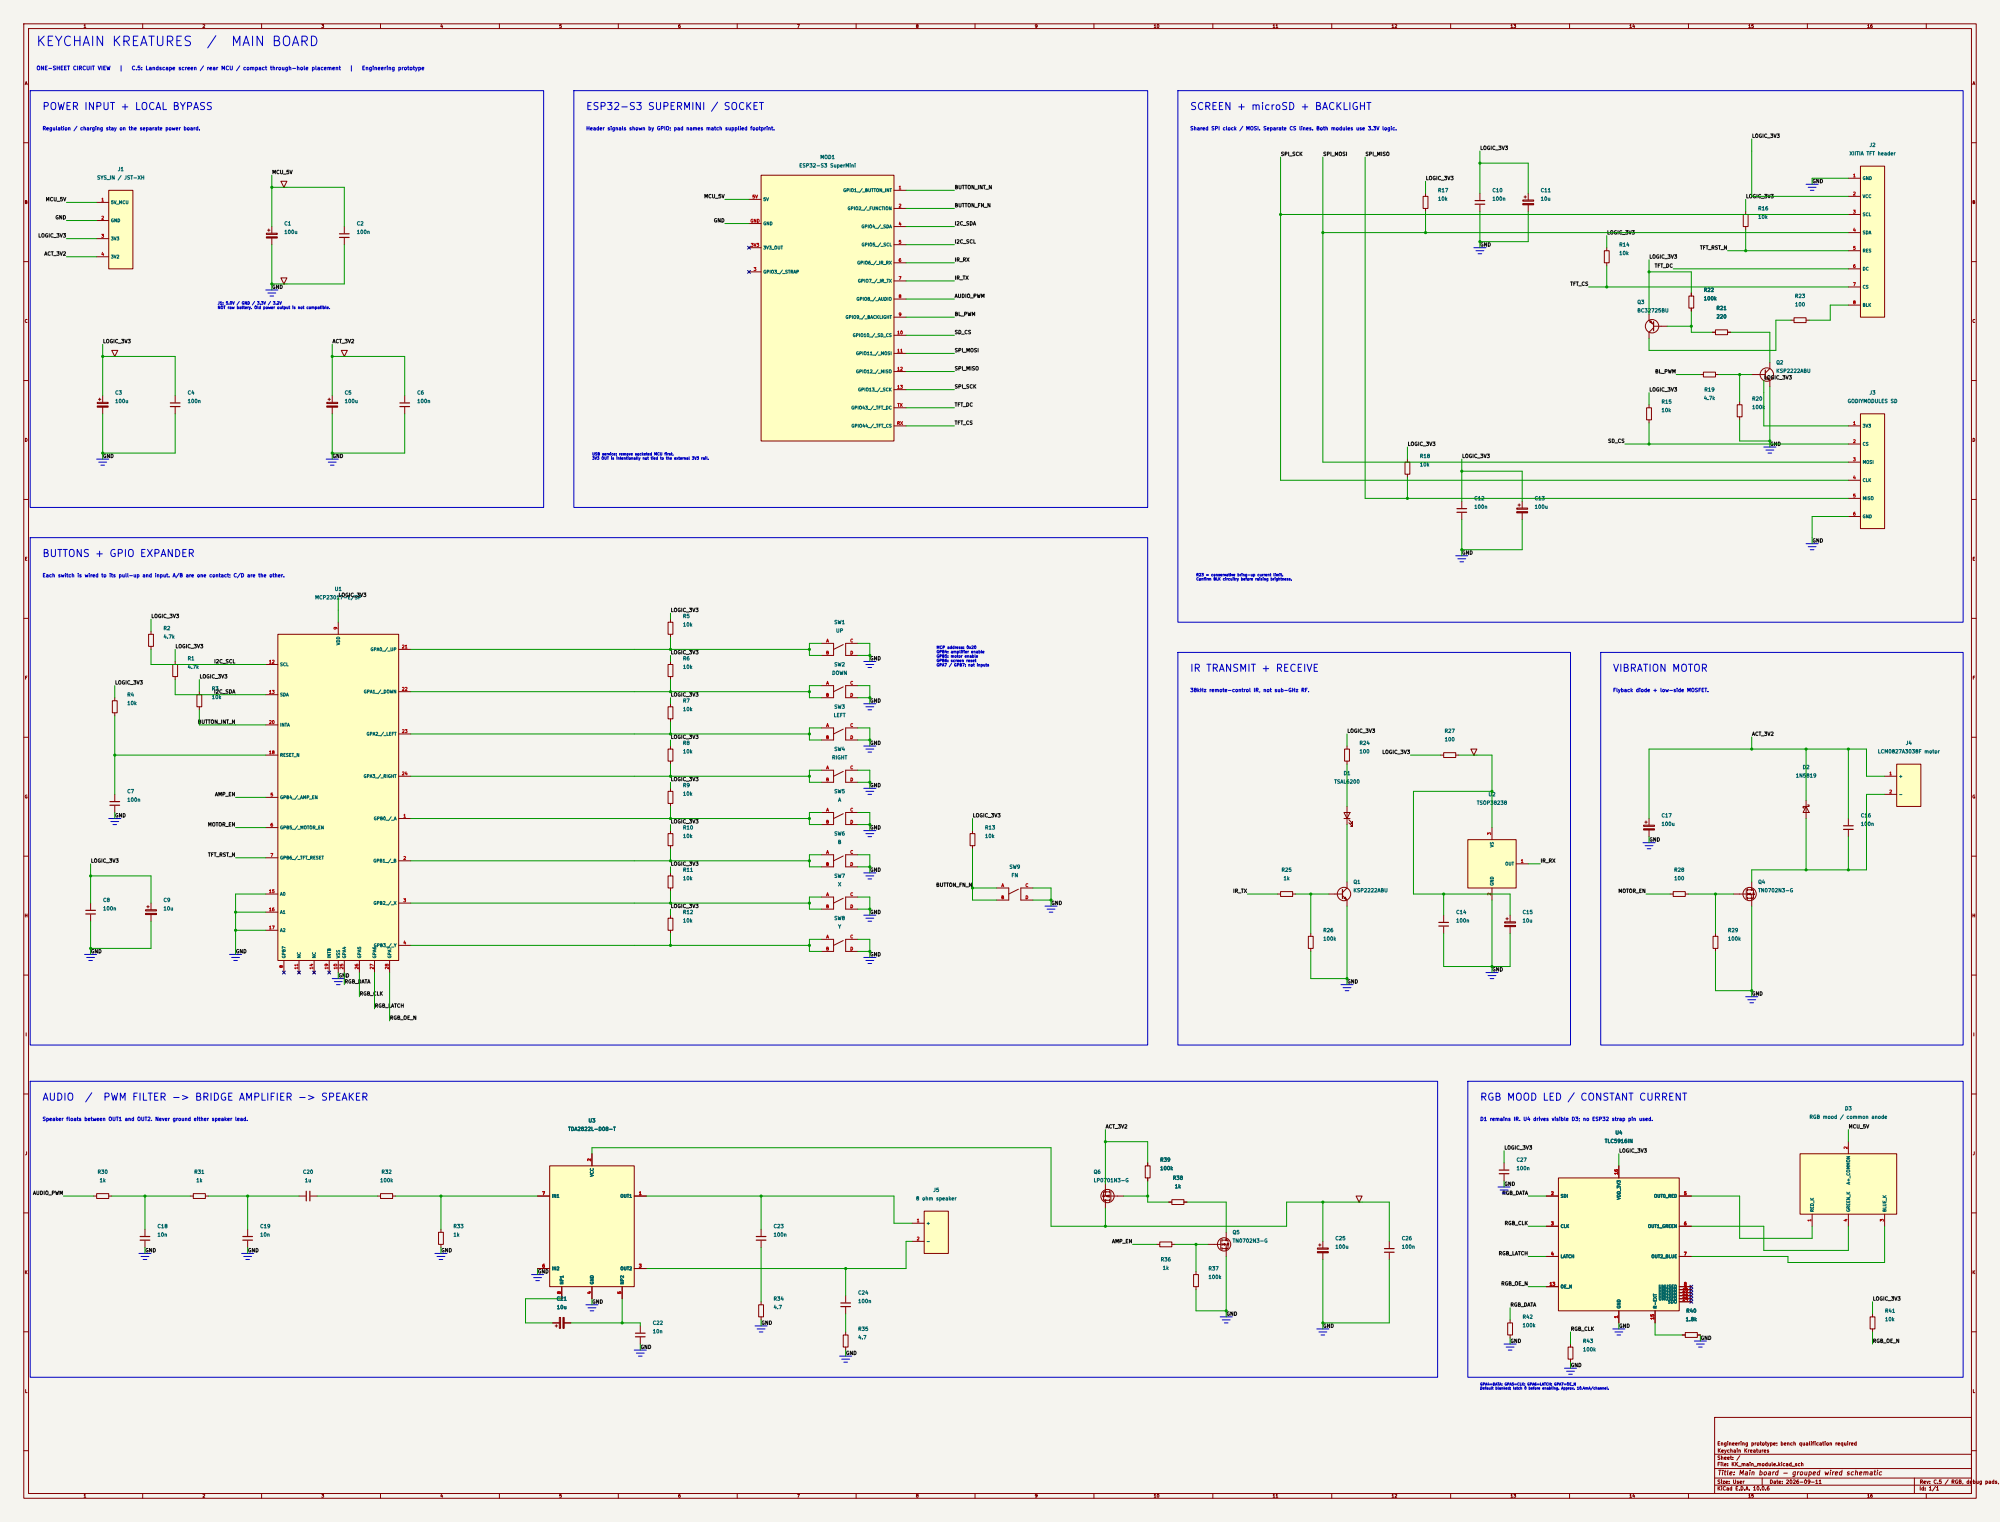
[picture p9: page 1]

KEYCHAIN KREATURES / MAIN BOARD

POWER INPUT + LOCAL BYPASS

Regulation / charging stay on the separate power board.

Shared SPI clock / MOSI. Separate CS lines. Both modules use 3.3V logic. J1: 5.0V / GND / 3.3V / 3.2V NOT raw battery. Old power output is not compatible.

Header signals shown by GPIO; pad names match supplied footprint.

Each switch is wired to its pull-up and input. A/B are one contact; C/D are the other.

Flyback diode + low-side MOSFET.

Speaker floats between OUT1 and OUT2. Never ground either speaker lead.

D1 remains IR. U4 drives visible D3; no ESP32 strap pin used.
14 R-EXT 15 VDD_3V3 16

RGB mood / common anode

GPA4=DATA; GPA5=CLK; GPA6=LATCH; GPA7=OE_N
Default blanked; latch 0 before enabling. Approx. 10.4mA/channel.

Engineering prototype; bench qualification required
Keychain Kreatures
Sheet: /
File: KK_main_module.kicad_sch
Title: Main board - grouped wired schematic
KiCad E.D.A. 10.0.6

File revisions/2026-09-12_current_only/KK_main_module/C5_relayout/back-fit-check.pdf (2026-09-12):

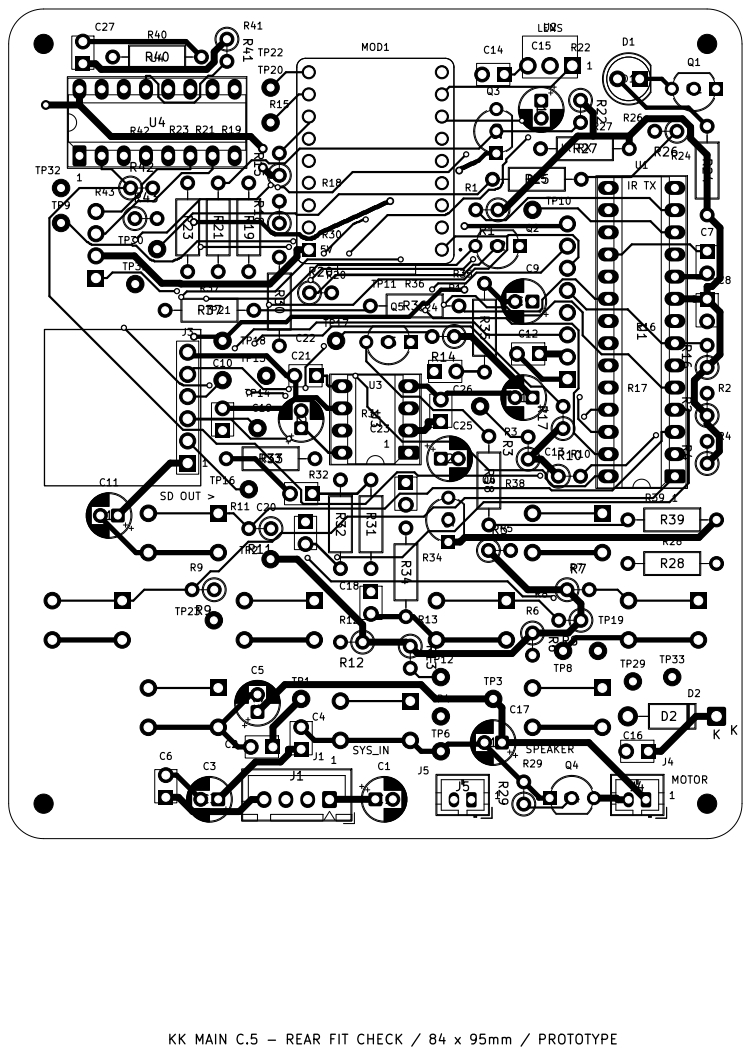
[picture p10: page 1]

K KK MAIN C.5 - REAR FIT CHECK / 84 x 95mm / PROTOTYPE

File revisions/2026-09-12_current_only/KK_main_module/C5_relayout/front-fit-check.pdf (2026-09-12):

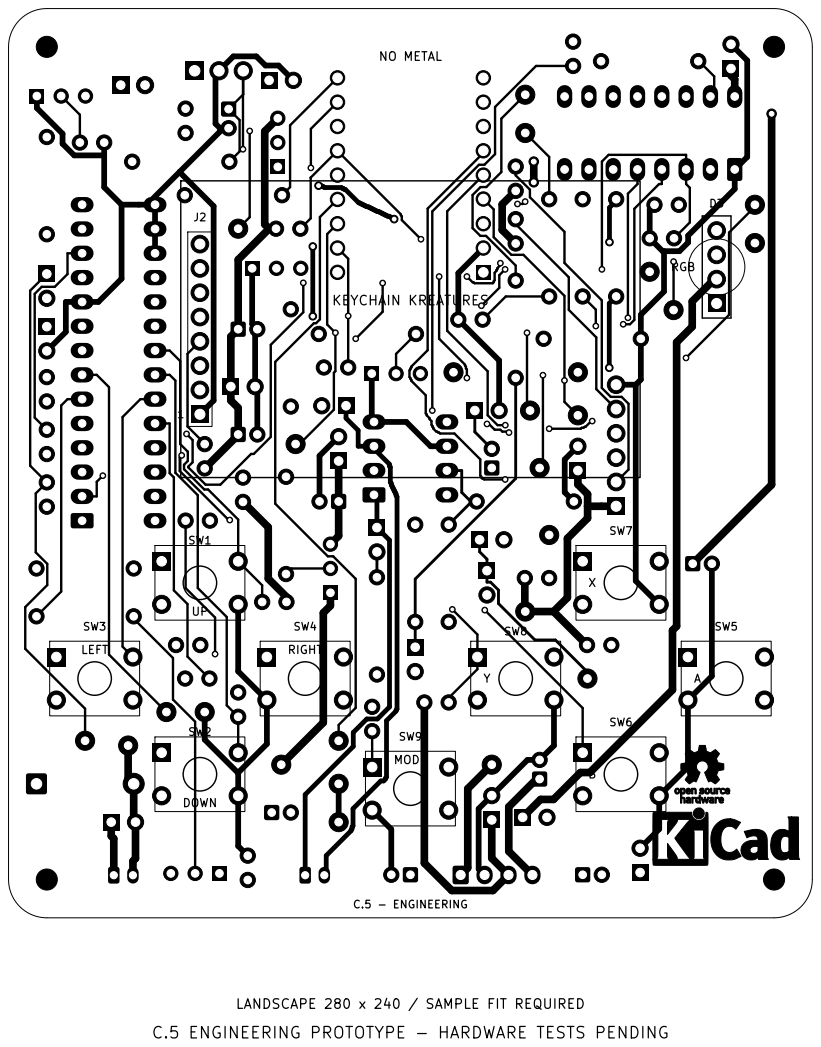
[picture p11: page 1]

A NO METAL KEYCHAIN KREATURES

LANDSCAPE 280 x 240 / SAMPLE FIT REQUIRED C.5 ENGINEERING PROTOTYPE - HARDWARE TESTS PENDING

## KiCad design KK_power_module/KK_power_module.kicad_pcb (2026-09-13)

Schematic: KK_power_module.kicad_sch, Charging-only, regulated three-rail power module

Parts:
C1, C71, C72: 1u; C_0603_1608Metric; MPN GRM188R71C105KA12D
C2, C6, C9, C25, C35, C45, C51, C60, C70: 100n; C_0603_1608Metric; MPN GRM188R71C104KA01D
C3: 4.7u; C_0805_2012Metric; MPN GRM21BR71C475KA73L
C4, C20, C21, C30, C31, C40, C41: 10u; C_0805_2012Metric; MPN GRM21BR61C106KE15L
C5, C8, C22, C23, C24, C32, C33, C34, C42, C43, C44: 22u; C_0805_2012Metric; MPN GRM21BR61C226ME44L
C7, C52, C53, C54: 10n; C_0603_1608Metric; MPN GRM188R71H103KA01D
C28, C38, C48: 10p; C_0603_1608Metric; MPN GRM1885C1H100JA01D
D1: SMAJ5.0A; D_SMA; MPN SMAJ5.0A
F1: 4A FAST; Fuse_1206_3216Metric; MPN 0451004.MRL
J1: USB-C CHARGE ONLY; USB_C_HCTL; MPN HC-TYPE-C-16P-01A
J2: 1S CELL / VH; JST_VH_B2P-VH_1x02_P3.96mm_Vertical; MPN B2P-VH(LF)(SN)
J3: C.5 SYS_IN / XH; JST_XH_B4B-XH-A_1x04_P2.50mm_Vertical; MPN B4B-XH-A(LF)(SN)
J4: BATTERY NTC; JST_PH_B2B-PH-K_1x02_P2.00mm_Vertical; MPN B2B-PH-K-S(LF)(SN)
L1, L2, L3: 1uH; L_Coilcraft_XxL4020; MPN XFL4020-102MEC
LED1: POWER GOOD; LED_1206_3216Metric; MPN APT3216LZGCK
LED2: CHARGING; LED_1206_3216Metric; MPN APT3216SURCK
Q1, Q2, Q3: FS8205; MPN FS8205
Q4, Q5: AO3400A; SOT-23; MPN AO3400A
R1: 887k; R_0603_1608Metric; MPN RC0603FR07887KL
R2, R6, R7: 4.7k; R_0603_1608Metric; MPN RC0603FR074K7L
R3, R14, R60: 10k; R_0603_1608Metric; MPN RC0603FR0710KL
R4: 2.94k; R_0603_1608Metric; MPN RT0603BRD072K94L
R5: 1.3k; R_0603_1608Metric; MPN RC0603FR071K3L
R8: 470; R_0603_1608Metric; MPN RC0603FR07470RL
R9: 1k; R_0603_1608Metric; MPN RC0603FR071KL
R10: 182k; R_0603_1608Metric; MPN RT0603BRD07182KL
R11, R31, R41, R62, R64, R66: 100k; R_0603_1608Metric; MPN RT0603BRD07100KL
R12: 620; R_0603_1608Metric; MPN RC0603FR07620RL
R13, R51, R72, R73: 100k; R_0603_1608Metric; MPN RC0603FR07100KL
R20: 909k; R_0603_1608Metric; MPN RT0603BRD07909KL
R21: 101k; R_0603_1608Metric; MPN RT0603BRD07101KL
R30: 560k; R_0603_1608Metric; MPN RT0603BRD07560KL
R40, R43: 270k; R_0603_1608Metric; MPN RT0603BRD07270KL
R50: 470k; R_0603_1608Metric; MPN RC0603FR07470KL
R52, R53, R54: 100; R_0603_1608Metric; MPN RC0603FR07100RL
R61: 1060k; R_0603_1608Metric; MPN RT0603BRD071M06L
R63: 665k; R_0603_1608Metric; MPN RT0603BRD07665KL
R65: 649k; R_0603_1608Metric; MPN RT0603BRD07649KL
R70: 19.2k; R_0603_1608Metric; MPN RT0603BRD0719K2L
R71: 634; R_0603_1608Metric; MPN RT0603BRD07634RL
R74: 31.6k; R_0603_1608Metric; MPN RT0603BRD0731K6L
R75: 20k; R_0603_1608Metric; MPN RT0603BRD0720KL
SW1: OFF / ON; SW_SPDT_CK_JS102011SAQN; MPN JS102011SAQN
TP1: VBUS; TestPoint_Pad_D1.5mm; MPN BARE PCB PAD
TP2: VBAT; TestPoint_Pad_D1.5mm; MPN BARE PCB PAD
TP3: BAT_NEG; TestPoint_Pad_D1.5mm; MPN BARE PCB PAD
TP4: GND; TestPoint_Pad_D1.5mm; MPN BARE PCB PAD
TP5: SYS_RAW; TestPoint_Pad_D1.5mm; MPN BARE PCB PAD
TP6: SYS_SW; TestPoint_Pad_D1.5mm; MPN BARE PCB PAD
TP7: RUN_CTL; TestPoint_Pad_D1.5mm; MPN BARE PCB PAD
TP8: EF_UVLO; TestPoint_Pad_D1.5mm; MPN BARE PCB PAD
TP9: EF_ILIM; TestPoint_Pad_D1.5mm; MPN BARE PCB PAD
TP10: EF_FAULT_N; TestPoint_Pad_D1.5mm; MPN BARE PCB PAD
TP11: PG_ALL; TestPoint_Pad_D1.5mm; MPN BARE PCB PAD
TP12: RAILS_EN; TestPoint_Pad_D1.5mm; MPN BARE PCB PAD
TP13: REG_5V; TestPoint_Pad_D1.5mm; MPN BARE PCB PAD
TP14: REG_3V3; TestPoint_Pad_D1.5mm; MPN BARE PCB PAD
TP15: REG_3V2; TestPoint_Pad_D1.5mm; MPN BARE PCB PAD
TP16: MCU_5V; TestPoint_Pad_D1.5mm; MPN BARE PCB PAD
TP17: LOGIC_3V3; TestPoint_Pad_D1.5mm; MPN BARE PCB PAD
TP18: ACT_3V2; TestPoint_Pad_D1.5mm; MPN BARE PCB PAD
TP19: NTC; TestPoint_Pad_D1.5mm; MPN BARE PCB PAD
TP20: CC_DEFAULT_N; TestPoint_Pad_D1.5mm; MPN BARE PCB PAD
TP21: USB_HIGH_CURRENT; TestPoint_Pad_D1.5mm; MPN BARE PCB PAD
TP22: USB_CHG; TestPoint_Pad_D1.5mm; MPN BARE PCB PAD
TP23: USB_PORT_ILIM; TestPoint_Pad_D1.5mm; MPN BARE PCB PAD
TP24: USB_LIMIT_FAULT_N; TestPoint_Pad_D1.5mm; MPN BARE PCB PAD
TP25: CC_3V3; TestPoint_Pad_D1.5mm; MPN BARE PCB PAD
TP26: PGOOD_N; TestPoint_Pad_D1.5mm; MPN BARE PCB PAD
TP27: CHARGE_N; TestPoint_Pad_D1.5mm; MPN BARE PCB PAD
TP28: VOLTAGES_OK; TestPoint_Pad_D1.5mm; MPN BARE PCB PAD
U1: BQ24075TRGTR; VQFN-16-1EP_3x3mm_P0.5mm_EP1.6x1.6mm; MPN BQ24075TRGTR
U2: DW01A / H&M; SOT-23-6; MPN DW01A
U3: TUSB320LAIRWBR; Texas_X2QFN-12_1.6x1.6mm_P0.4mm; MPN TUSB320LAIRWBR
U4: TPS259530DSGR; Texas_DSG0008A_WSON-8-1EP_2x2mm_P0.5mm_EP0.9x1.6mm; MPN TPS259530DSGR
U5, U6, U7: TPS63060DSCR; Texas_S-PWSON-N10; MPN TPS63060DSCR
U8, U9, U10: TPS22918DBVR; SOT-23-6; MPN TPS22918DBVR
U11: SN74AUP1G17DBVR; SOT-23-5; MPN SN74AUP1G17DBVR
U12: TPS386000RGPR; Texas_RGP0020D_VQFN-20-1EP_4x4mm_P0.5mm_EP2.7x2.7mm; MPN TPS386000RGPR
U13: TPS22950YBHR; TPS22950_YBH; MPN TPS22950YBHR
U14: TLV75533PDBVR; SOT-23-5; MPN TLV75533PDBVR

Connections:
/ACT_3V2: J3.4 (3V2), R54.1, TP18.1, U10.6 (VOUT)
/BAT_NEG: C6.2, J2.2 (CELL-), Q1.1 (S1), Q2.1 (S1), Q3.1 (S1), TP3.1, U2.6 (GND)
/CC1: J1.A5 (CC1), U3.1 (CC1)
/CC2: J1.B5 (CC2), U3.2 (CC2)
/CC_3V3: C2.1, C72.1, R2.1, R3.1, TP25.1, U3.12 (VDD), U14.5 (OUT)
/CC_DEFAULT_N: Q4.1 (G), R2.2, TP20.1, U3.7 (OUT1)
/CELL_PLUS: F1.1, J2.1 (CELL+)
/CHARGE_N: R7.2, TP27.1, U1.9 (~CHG)
/CHG_ILIM: R5.1, U1.12 (ILIM)
/CHG_ISET: R4.1, U1.16 (ISET)
/DRAIN_COMMON: Q1.2 (D1), Q1.5 (D2), Q2.2 (D1), Q2.5 (D2), Q3.2 (D1), Q3.5 (D2)
/EF_FAULT_N: R13.2, TP10.1, U4.6 (FAULT_N)
/EF_ILIM: R12.1, TP9.1, U4.7 (ILM)
/EF_SLEW: C7.1, U4.1 (dVdt)
/EF_UVLO: R10.2, R11.1, TP8.1, U4.2 (EN / UVLO)
/GND: C1.2, C2.2, C3.2, C4.2, C5.2, C7.2, C8.2, C9.2, C20.2, C21.2, C22.2, C23.2, C24.2, C25.2, C28.2, C30.2, C31.2, C32.2, C33.2, C34.2, C35.2, C38.2, C40.2, C41.2, C42.2, C43.2, C44.2, C45.2, C48.2, C51.2, C52.2, C53.2, C54.2, C60.2, C70.2, C71.2, C72.2, D1.2 (A), J1.A1 (GND), J1.A12 (GND), J1.B1 (GND), J1.B12 (GND), J1.S1 (SHIELD), J3.2 (GND), J4.2 (GND), Q1.3 (S2), Q2.3 (S2), Q3.3 (S2), Q4.2 (S), Q5.2 (S), R4.2, R5.2, R9.1, R11.2, R12.2, R21.2, R31.2, R41.2, R51.2, R62.2, R64.2, R66.2, R70.2, R72.2, R75.2, SW1.1 (A), TP4.1, U1.4 (~CE), U1.6 (EN1), U1.8 (VSS), U1.15 (SYSOFF), U1.17 (VSS), U3.3 (PORT = SINK), U3.10 (GND), U3.11 (EN_N), U4.8 (GND), U4.9 (EP / GND), U5.7 (GND), U5.11 (PGND), U6.7 (GND), U6.11 (PGND), U7.7 (GND), U7.11 (PGND), U8.2 (GND), U9.2 (GND), U10.2 (GND), U11.3 (GND), U12.6 (SENSE4H), U12.11 (NC / GND), U12.12 (GND), U12.20 (WDI), U12.21 (EP / GND), U13.C1 (GND), U14.2 (GND)
/LED1_K: LED1.1 (K), R6.1
/LED2_K: LED2.1 (K), R7.1
/LOGIC_3V3: J3.3 (3V3), R53.1, TP17.1, U9.6 (VOUT)
/MCU_5V: J3.1 (5V), R52.1, TP16.1, U8.6 (VOUT)
/NTC: J4.1 (NTC), R74.2, R75.1, TP19.1, U1.1 (TS)
/OC: Q1.4 (G2 / OC), Q2.4 (G2 / OC), Q3.4 (G2 / OC), U2.3 (OC)
/OD: Q1.6 (G1 / OD), Q2.6 (G1 / OD), Q3.6 (G1 / OD), U2.1 (OD)
/PGOOD_N: R6.2, TP26.1, U1.7 (~PGOOD)
/PG_ALL: R50.2, TP11.1, U5.5 (PG), U6.5 (PG), U7.5 (PG)
/PROTECT_CS: R9.2, U2.2 (CS)
/PROTECT_VCC: C6.1, R8.2, U2.5 (VCC)
/RAILS_EN: R51.1, TP12.1, U8.3 (ON), U9.3 (ON), U10.3 (ON), U11.4 (Y)
/REG_3V2: C42.1, C43.1, C44.1, R40.1, R65.1, TP15.1, U7.9 (VOUT), U10.1 (VIN)
/REG_3V3: C32.1, C33.1, C34.1, C51.1, R30.1, R50.1, R60.1, R63.1, TP14.1, U6.9 (VOUT), U9.1 (VIN), U11.5 (VCC)
/REG_5V: C22.1, C23.1, C24.1, R20.1, R61.1, TP13.1, U5.9 (VOUT), U8.1 (VIN)
/REG_ENABLE: R14.2, U5.3 (EN), U5.4 (PS/SYNC), U6.3 (EN), U6.4 (PS/SYNC), U7.3 (EN), U7.4 (PS/SYNC)
/RUN_CTL: R10.1, R14.1, SW1.2 (B), TP7.1, U12.1 (MR_N)
/SENSE_3V2: R65.2, R66.1, U12.8 (SENSE3)
/SENSE_3V3: R63.2, R64.1, U12.9 (SENSE2)
/SENSE_5V: R61.2, R62.1, U12.10 (SENSE1)
/SYS_RAW: C5.1, C9.1, C60.1, R13.1, SW1.3 (C), TP5.1, U1.10 (OUT), U1.11 (OUT), U4.3 (IN), U4.4 (IN), U12.14 (VDD)
/SYS_SW: C8.1, C20.1, C21.1, C30.1, C31.1, C40.1, C41.1, TP6.1, U4.5 (OUT), U5.2 (VIN), U6.2 (VIN), U7.2 (VIN), U12.7 (SENSE4L)
/U5_AUX: C25.1, U5.6 (VAUX)
/U5_FB: C28.1, R20.2, R21.1, U5.8 (FB)
/U5_L1: L1.1, U5.1 (L1)
/U5_L2: L1.2, U5.10 (L2)
/U6_AUX: C35.1, U6.6 (VAUX)
/U6_FB: C38.1, R30.2, R31.1, U6.8 (FB)
/U6_L1: L2.1, U6.1 (L1)
/U6_L2: L2.2, U6.10 (L2)
/U7_AUX: C45.1, U7.6 (VAUX)
/U7_FB: C48.1, R41.1, R43.2, U7.8 (FB)
/U7_FB_MID: R40.2, R43.1
/U7_L1: L3.1, U7.1 (L1)
/U7_L2: L3.2, U7.10 (L2)
/U8_CT: C52.1, U8.4 (CT)
/U8_QOD: R52.2, U8.5 (QOD)
/U9_CT: C53.1, U9.4 (CT)
/U9_QOD: R53.2, U9.5 (QOD)
/U10_CT: C54.1, U10.4 (CT)
/U10_QOD: R54.2, U10.5 (QOD)
/USB_CHG: C3.1, C71.1, R74.1, TP22.1, U1.13 (IN), U13.B2 (VOUT)
/USB_HIGH_CURRENT: Q4.3 (D), Q5.1 (G), R3.2, R72.1, TP21.1, U1.5 (EN2)
/USB_LIMIT_FAULT_N: R73.2, TP24.1, U13.A2 (FLT_N)
/USB_PORT_ILIM: R70.1, R71.1, TP23.1, U13.C2 (ILIM)
/USB_PORT_ILIM_FAST: Q5.3 (D), R71.2
/VBAT: C4.1, F1.2, R8.1, TP2.1, U1.2 (BAT), U1.3 (BAT)
/VBUS: C1.1, C70.1, D1.1 (K), J1.A4 (VBUS), J1.A9 (VBUS), J1.B4 (VBUS), J1.B9 (VBUS), LED1.2 (A), LED2.2 (A), R1.1, R73.1, TP1.1, U13.A1 (ON), U13.B1 (VIN), U14.1 (IN), U14.3 (EN)
/VBUS_DET: R1.2, U3.4 (VBUS_DET)
/VOLTAGES_OK: R60.2, TP28.1, U11.2 (A), U12.15 (RESET1_N), U12.16 (RESET2_N), U12.17 (RESET3_N)

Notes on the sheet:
USB-C CHARGING ONLY
CELL CHARGER / POWER PATH
CELL PROTECTION / FUSE
SYSTEM SWITCH / INRUSH / UVLO
5 V BUCK-BOOST
3.3 V BUCK-BOOST
3.2 V BUCK-BOOST
ALL-RAIL READY / SOFT OUTPUTS
VOLTAGE SUPERVISION / STARTUP
USB-A / USB-C INPUT CURRENT
MAIN BOARD HARNESS / DEBUG
KEYCHAIN KREATURES / POWER P.2 - ENGINEERING, NOT RELEASED

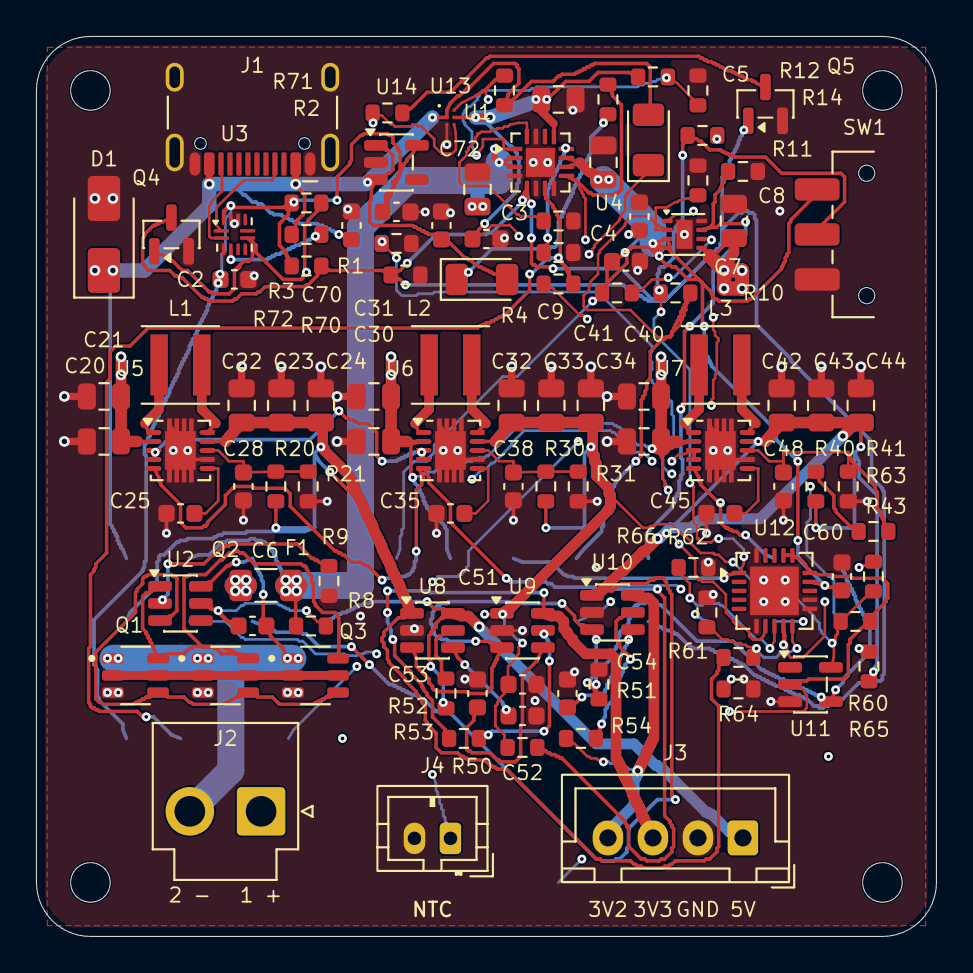
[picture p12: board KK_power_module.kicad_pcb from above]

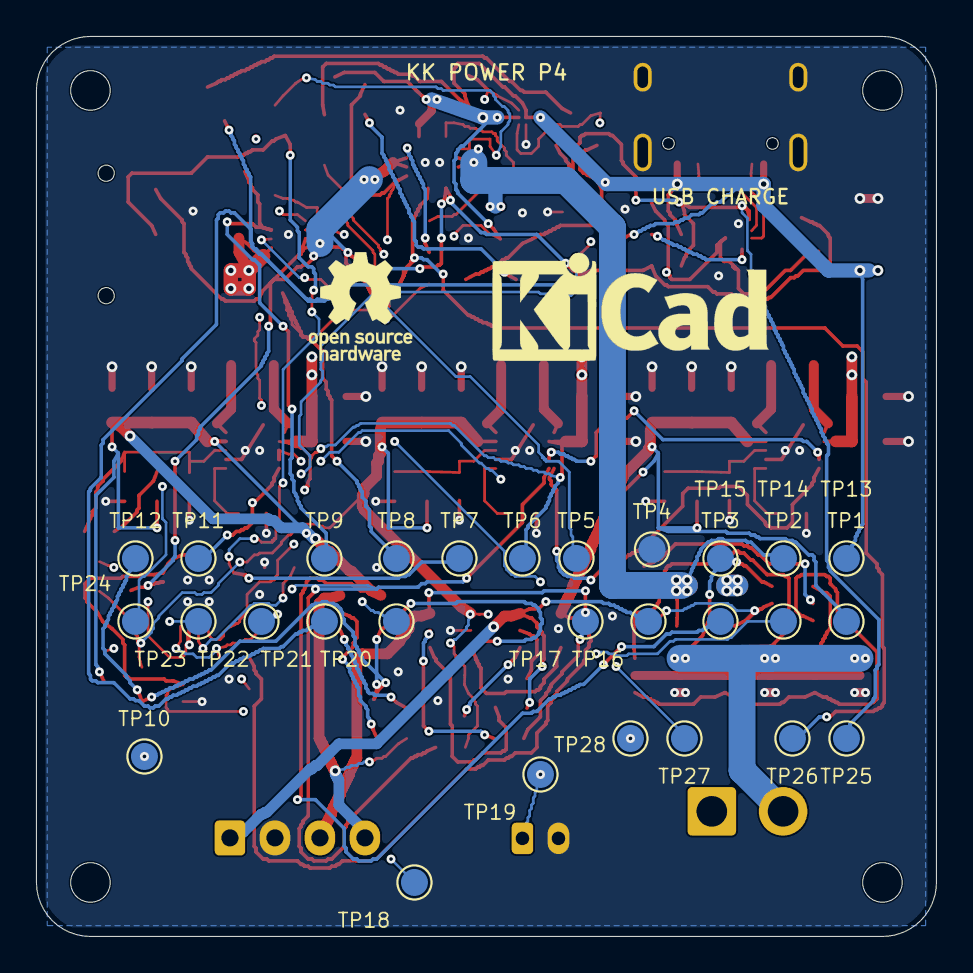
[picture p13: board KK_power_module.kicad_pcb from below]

Board: 4 copper layers, 50.0 x 50.0 mm, 142 parts (30 on the bottom side), 66 nets.

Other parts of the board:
H1, H2, H3, H4: MountingHole_2.2mm_M2
LOGO1: KiCad-Logo_6mm_SilkScreen
LOGO2: OSHW-Logo_5.7x6mm_SilkScreen

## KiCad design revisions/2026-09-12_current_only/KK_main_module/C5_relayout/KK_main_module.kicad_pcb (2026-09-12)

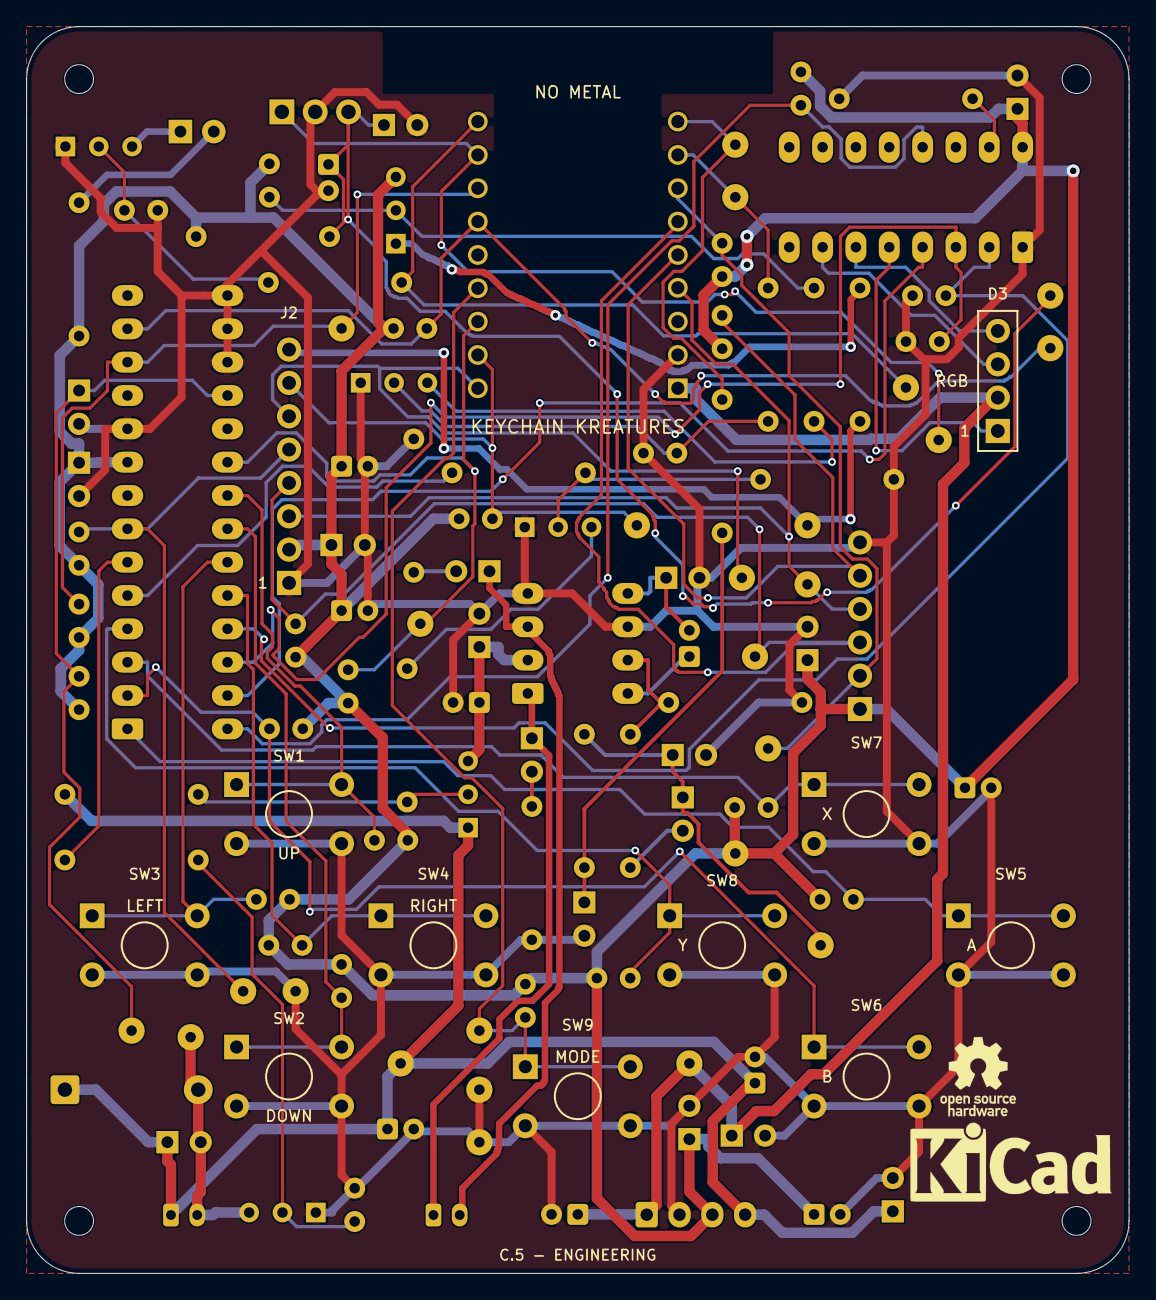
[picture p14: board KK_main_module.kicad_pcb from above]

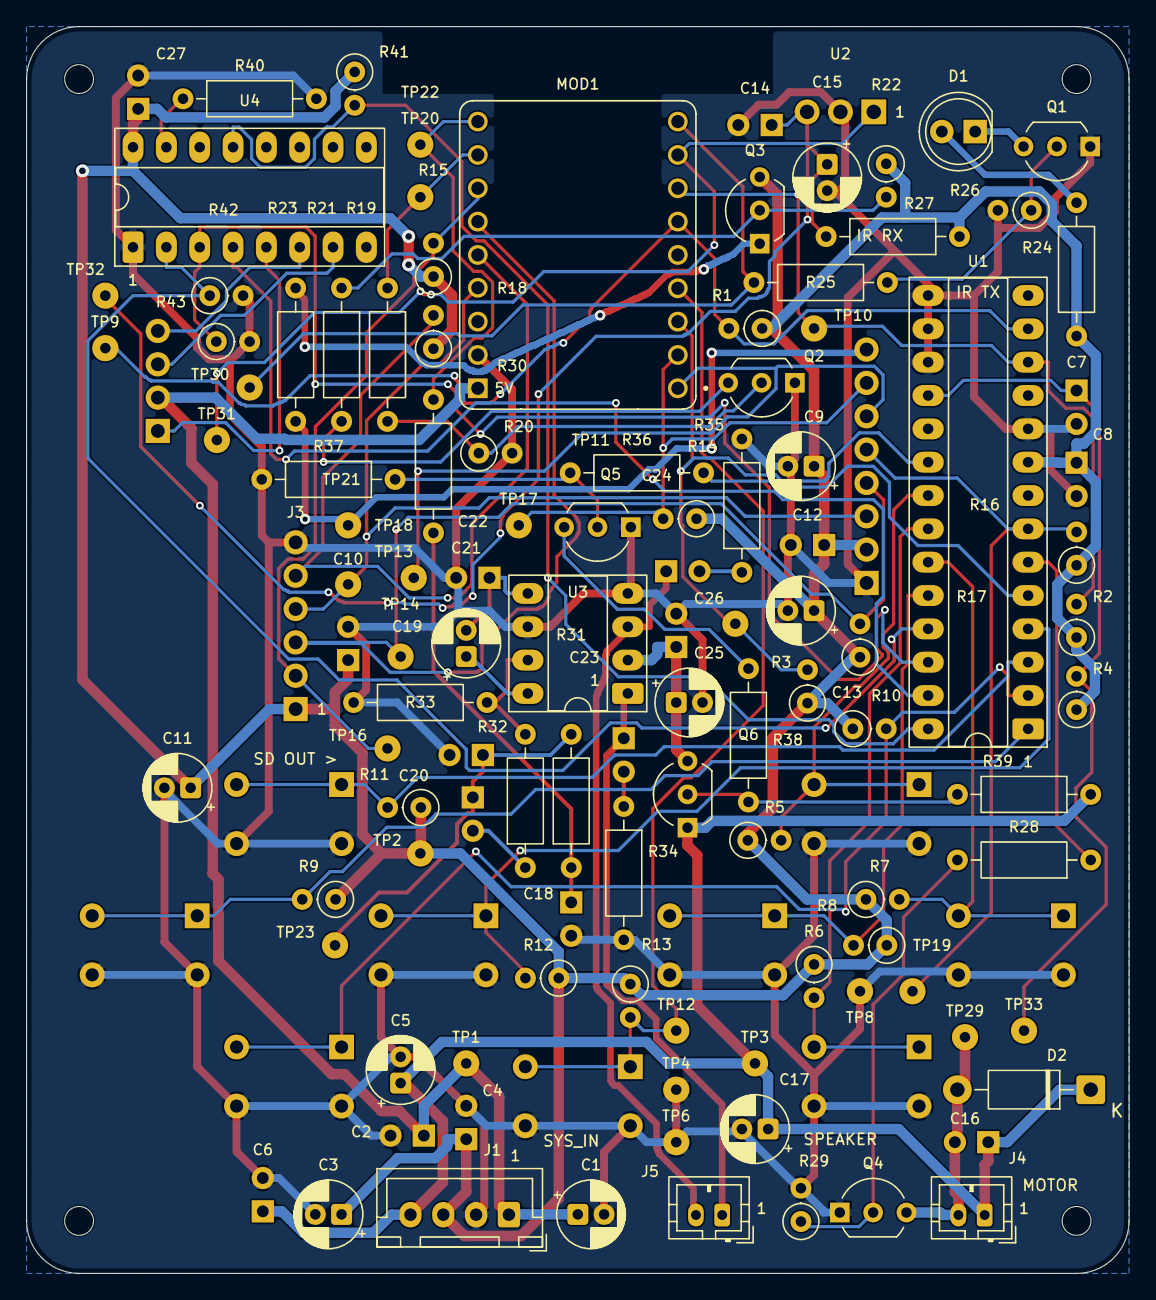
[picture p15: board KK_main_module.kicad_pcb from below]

Board: 2 copper layers, 84.0 x 95.0 mm, 129 parts (116 on the bottom side), 63 nets.

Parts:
C1, C3, C5, C13, C17, C25: 100u; Nichicon_UVR_D5_P2
C2, C4, C6, C7, C8, C10, C12, C14, C16, C23, C24, C26, C27: 100n; KEMET_C315_P2p54
C9, C11, C15, C21: 10u; Nichicon_UVR_D5_P2
C18, C19, C22: 10n; KEMET_C315_P2p54
C20: 1u; KEMET_C315_P2p54
D1: TSAL6200; TSAL6200_C5_EdgeFormed
D2: 1N5819; 1N5819_DO41
D3: RGB mood / common anode; RGB_CA_5mm_Socketed
H1, H2, H3, H4: M2 2.2mm NPTH
J1: SYS_IN / JST-XH; JST_XH_B4B_4
J2: XIITIA TFT header; Sullins_PPTC081_LFB
J3: GODIYMODULES SD; Sullins_PPTC061_LFB
J4: LCM0827A3038F motor; JST_PH_B2B_2
J5: 8 ohm speaker; JST_PH_B2B_2
LOGO1: KiCad-Logo_6mm_SilkScreen
LOGO2: OSHW-Logo_5.7x6mm_SilkScreen
MOD1: ESP32-S3 SuperMini; ESP32-S3-SuperMini
Q1, Q2: KSP2222ABU; TO92_LeadFormed_P2p54
Q3: BC32725BU; TO92_LeadFormed_P2p54
Q4, Q5: TN0702N3-G; TO92_LeadFormed_P2p54
Q6: LP0701N3-G; TO92_LeadFormed_P2p54
R1, R2: 4.7k; MFR25_Upright_P2p54
R3, R4, R5, R6, R7, R8, R9, R10, R11, R12, R13, R14, R15, R16, R17, R18, R41: 10k; MFR25_Upright_P2p54
R19: 4.7k; MFR25_10p16
R20, R22, R26, R29, R42, R43: 100k; MFR25_Upright_P2p54
R21: 220; MFR25_10p16
R23, R24, R27, R28: 100; MFR25_10p16
R25, R30, R31, R33, R36, R38: 1k; MFR25_10p16
R32, R37, R39: 100k; MFR25_10p16
R34, R35: 4.7; MFR25_10p16
R40: 1.8k; MFR25_10p16
SW1: UP; Adafruit3101_ABCD
SW2: DOWN; Adafruit3101_ABCD
SW3: LEFT; Adafruit3101_ABCD
SW4: RIGHT; Adafruit3101_ABCD
SW5: A; Adafruit3101_ABCD
SW6: B; Adafruit3101_ABCD
SW7: X; Adafruit3101_ABCD
SW8: Y; Adafruit3101_ABCD
SW9: FN; Adafruit3101_ABCD
TP1: 5V; Debug_PTH_2mm
TP2: 3V3; Debug_PTH_2mm
TP3: 3V2; Debug_PTH_2mm
TP4: GND-P; Debug_PTH_2mm
TP6: GND-A; Debug_PTH_2mm
TP8: GND-M; Debug_PTH_2mm
TP9: SDA; Debug_PTH_2mm
TP10: SCL; Debug_PTH_2mm
TP11: KEY-IRQ; Debug_PTH_2mm
TP12: FN; Debug_PTH_2mm
TP13: SCK; Debug_PTH_2mm
TP14: MOSI; Debug_PTH_2mm
TP16: SD-CS; Debug_PTH_2mm
TP17: TFT-CS; Debug_PTH_2mm
TP18: TFT-DC; Debug_PTH_2mm
TP19: TFT-RST; Debug_PTH_2mm
TP20: BL-PWM; Debug_PTH_2mm
TP21: BLK; Debug_PTH_2mm
TP22: AUD-PWM; Debug_PTH_2mm
TP23: AUD-LP2; Debug_PTH_2mm
TP29: MOT-RET; Debug_PTH_2mm
TP30: IR-TX; Debug_PTH_2mm
TP31: IR-RX; Debug_PTH_2mm
TP32: IR-V; Debug_PTH_2mm
TP33: IO-RST; Debug_PTH_2mm
U1: MCP23017-E/SP; ED281DT_DIP28_Socket
U2: TSOP38238; TSOP38238_Vertical
U3: TDA2822L-D08-T; ED08DT_DIP8_Socket
U4: TLC5916IN; ED16DT_DIP16_Socket

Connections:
/ACT_3V2: C5.1, C6.1, C16.1, C17.1, D2.1, J1.4, J4.1, Q6.1, R39.1, TP3.1
/AMP_EN: R36.1, U1.5
/AUDIO_PWM: MOD1.8, R30.1, TP22.1
/BL_PWM: MOD1.9, R19.1, TP20.1
/BUTTON_FN_N: MOD1.2, R13.2, SW9.A, SW9.B, TP12.1
/BUTTON_INT_N: MOD1.1, R3.2, TP11.1, U1.20
/GND: C1.2, C2.2, C3.2, C4.2, C5.2, C6.2, C7.2, C8.2, C9.2, C10.2, C11.2, C12.2, C13.2, C14.2, C15.2, C17.2, C18.2, C19.2, C22.2, C25.2, C26.2, C27.2, J1.2, J2.1, J3.6, MOD1.GND, Q1.1, Q2.1, Q4.1, Q5.1, R20.2, R26.2, R29.2, R33.2, R34.2, R35.2, R37.2, R40.2, R42.2, R43.2, SW1.C, SW1.D, SW2.C, SW2.D, SW3.C, SW3.D, SW4.C, SW4.D, SW5.C, SW5.D, SW6.C, SW6.D, SW7.C, SW7.D, SW8.C, SW8.D, SW9.C, SW9.D, TP4.1, TP6.1, TP8.1, U1.10, U1.15, U1.16, U1.17, U2.2, U3.4, U3.6, U4.1
/I2C_SCL: MOD1.5, R2.2, TP10.1, U1.12
/I2C_SDA: MOD1.4, R1.2, TP9.1, U1.13
/IR_RX: MOD1.6, TP31.1, U2.1
/IR_TX: MOD1.7, R25.1, TP30.1
/LOGIC_3V3: C3.1, C4.1, C8.1, C9.1, C10.1, C11.1, C12.1, C13.1, C27.1, J1.3, J2.2, J3.1, Q3.3, R1.1, R2.1, R3.1, R4.1, R5.1, R6.1, R7.1, R8.1, R9.1, R10.1, R11.1, R12.1, R13.1, R14.1, R15.1, R16.1, R17.1, R18.1, R22.1, R24.1, R27.1, R41.1, TP2.1, U1.9, U4.16
/MCU_5V: C1.1, C2.1, D3.2, J1.1, MOD1.5V, TP1.1
/MOTOR_EN: R28.1, U1.6
/RGB_CLK: R43.1, U1.26, U4.3
/RGB_DATA: R42.1, U1.25, U4.2
/RGB_LATCH: U1.27, U4.4
/RGB_OE_N: R41.2, U1.28, U4.13
/SD_CS: J3.2, MOD1.10, R15.2, TP16.1
/SPI_MISO: J3.5, MOD1.12, R18.2
/SPI_MOSI: J2.4, J3.3, MOD1.11, R17.2, TP14.1
/SPI_SCK: J2.3, J3.4, MOD1.13, TP13.1
/TFT_CS: J2.7, MOD1.RX, R14.2, TP17.1
/TFT_DC: J2.6, MOD1.TX, TP18.1
/TFT_RST_N: J2.5, R16.2, TP19.1, U1.7
unnamed: C18.1, R30.2, R31.1
unnamed: C19.1, C20.1, R31.2, TP23.1
unnamed: C20.2, R32.1
unnamed: C23.2, R34.1
unnamed: C24.2, R35.1
unnamed: D1.2, R24.2
unnamed: D1.1, Q1.3
unnamed: C16.2, D2.2, J4.2, Q4.3, TP29.1
unnamed: D3.3, U4.7
unnamed: D3.4, U4.6
unnamed: D3.1, U4.5
unnamed: J2.8, R23.2, TP21.1
unnamed: C23.1, J5.1, U3.1
unnamed: C24.1, J5.2, U3.3
unnamed: Q1.2, R25.2, R26.1
unnamed: Q2.2, R19.2, R20.1
unnamed: Q2.3, R21.2
unnamed: Q3.2, R21.1, R22.2
unnamed: Q3.1, R23.1
unnamed: Q4.2, R28.2, R29.1
unnamed: Q5.3, R38.2
unnamed: Q5.2, R36.2, R37.1
unnamed: C25.1, C26.1, Q6.3, U3.2
unnamed: Q6.2, R38.1, R39.2
unnamed: R5.2, SW1.A, SW1.B, U1.21
unnamed: R6.2, SW2.A, SW2.B, U1.22
unnamed: R7.2, SW3.A, SW3.B, U1.23
unnamed: R8.2, SW4.A, SW4.B, U1.24
unnamed: R9.2, SW5.A, SW5.B, U1.1
unnamed: R10.2, SW6.A, SW6.B, U1.2
unnamed: R11.2, SW7.A, SW7.B, U1.3
unnamed: R12.2, SW8.A, SW8.B, U1.4
unnamed: C7.1, R4.2, TP33.1, U1.18
unnamed: C14.1, C15.1, R27.2, TP32.1, U2.3
unnamed: R32.2, R33.1, U3.7
unnamed: C21.1, U3.8
unnamed: C21.2, C22.1, U3.5
unnamed: R40.1, U4.15

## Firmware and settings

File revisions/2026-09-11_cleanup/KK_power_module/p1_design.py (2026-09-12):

"""Generate the P.1 engineering schematic from an explicit pin/net manifest.

Never overwrites the released root project. Run on the host, then export the
netlist/ERC with native KiCad. All CAD edits are reproducible from this file.
"""
from pathlib import Path
import json,re,copy,uuid,csv
ROOT=Path(__file__).resolve().parent; OUT=ROOT/'P1_revision'
META=json.loads((OUT/'stage.json').read_text()); LIB=Path(META['libraries']['Symbols'])
def uid(s): return str(uuid.uuid5(uuid.NAMESPACE_URL,'kk-power-p1:'+s))
def parse(s):
    t=re.findall(r'"(?:\\.|[^"\\])*"|[()]|[^\s()]+',s); i=0
    def p():
        nonlocal i
        assert t[i]=='('; i+=1; a=[]
        while t[i]!=')':
            if t[i]=='(': a.append(p())
            else: a.append(t[i]); i+=1
        i+=1; return a
    return p()
def dump(a): return '('+' '.join(map(dump,a))+')' if isinstance(a,list) else str(a)
def val(s): return json.loads(s) if str(s).startswith('"') else s
def kids(a,k):return [x for x in a if isinstance(x,list) and x[0]==k]
def child(a,k):return next((x for x in a if isinstance(x,list) and x[0]==k),None)
q=json.dumps
defs={}; cache={}
DATASHEETS={
 'BQ24074RGTR':'https://www.ti.com/lit/ds/symlink/bq24074.pdf',
 'TUSB320LAIRWBR':'https://www.ti.com/lit/ds/symlink/tusb320lai.pdf',
 'TPS259530DSGR':'https://www.ti.com/lit/ds/symlink/tps2595.pdf',
 'TPS63060DSCR':'https://www.ti.com/lit/ds/symlink/tps63060.pdf',
 'TPS22918DBVR':'https://www.ti.com/lit/ds/symlink/tps22918.pdf',
 'SN74AUP1G17DBVR':'https://www.ti.com/lit/ds/symlink/sn74aup1g17.pdf',
 'TPS386000RGPR':'https://www.ti.com/lit/ds/symlink/tps386000.pdf',
 'TPS22950YBHR':'https://www.ti.com/lit/ds/symlink/tps22950.pdf',
 'TLV75533PDBVR':'https://www.ti.com/lit/ds/symlink/tlv755p.pdf',
 'AO3400A':'https://www.aosmd.com/sites/default/files/res/datasheets/AO3400A.pdf',
 'DW01A':'https://hmsemi.com/downfile/DW01A.PDF',
 'FS8205':'https://www.ic-fortune.com/upload/Download/FS8205-DS-19_EN.pdf',
 'XFL4020-102MEC':'https://www.coilcraft.com/getmedia/50632d43-da1b-4cdb-8ab4-3029cab51df3/xfl4020.pdf',
 'JS102011SAQN':'https://www.ckswitches.com/media/1422/js.pdf',
 'HC-TYPE-C-16P-01A':'https://datasheet.lcsc.com/lcsc/2211161000_HCTL-HC-TYPE-C-16P-01A_C2894897.pdf',
}
def stock(lib,name,alias=None):
    if lib not in cache:cache[lib]={val(a[1]):a for a in kids(parse((LIB/(lib+'.kicad_sym')).read_text()),'symbol')}
    def resolve(n):
        d=copy.deepcopy(cache[lib][n]); e=child(d,'extends')
        if e:
            base=resolve(val(e[1])); props={val(x[1]) for x in kids(d,'property')}
            d=[x for x in d if x is not e]
            d.extend(copy.deepcopy(x) for x in base[2:] if isinstance(x,list) and (x[0]!='property' or val(x[1]) not in props))
        return d
    d=resolve(name); alias=alias or name; d[1]=q(alias)
    for j,u in enumerate(kids(d,'symbol')):
        suffix=re.search(r'(_\d+_\d+)$',val(u[1])).group(1)
        u[1]=q(alias+suffix)
    defs[alias]=d;return alias
def box(name,pins):
    # Pins specified explicitly from manufacturer numbering, not physical sides.
    left=[p for p in pins if p[2] not in ('output','power_out','open_collector')]
    right=[p for p in pins if p not in left]
    h=max(10.16,(max(len(left),len(right))+1)*2.54); w=25.4
    s=f'(symbol {q(name)} (pin_names(offset 0.6))(in_bom yes)(on_board yes)(property "Reference" "U"(at 0 0 0)(effects(font(size 1.27 1.27))))(property "Value" {q(name)}(at 0 0 0)(effects(font(size 1.27 1.27))))(symbol {q(name+"_0_1")}(rectangle(start {-w/2} {h/2})(end {w/2} {-h/2})(stroke(width 0.254)(type default))(fill(type background))))(symbol {q(name+"_1_1")}'
    for side,ps in [(-1,left),(1,right)]:
        for i,(n,label,typ) in enumerate(ps):
            y=(len(ps)-1)/2*2.54-i*2.54
            s+=f'(pin {typ} line(at {side*(w/2+5.08)} {y} {0 if side<0 else 180})(length 5.08)(name {q(label)}(effects(font(size 1.1 1.1))))(number {q(str(n))}(effects(font(size 1.1 1.1)))))'
    defs[name]=parse(s+'))');return name
def fpof(sym):return val(next(p for p in kids(defs[sym],'property') if val(p[1])=='Footprint')[2])
for lib,n in [('Device','R'),('Device','C'),('Device','L'),('Device','LED'),('Device','D_Schottky'),('Device','D'),('Device','Fuse'),('Transistor_FET','2N7002'),('Switch','SW_SPDT'),('Battery_Management','BQ24074RGT'),('Battery_Management','DW01A'),('Regulator_Switching','TPS63060')]:stock(lib,n)
stock('Connector','USB_C_Receptacle_USB2.0_16P','USB_C_Receptacle_USB2.0')
stock('Regulator_Linear','TLV75533PDBV')
stock('Transistor_FET','AO3400A')
for unit in kids(defs['USB_C_Receptacle_USB2.0'],'symbol'):
    for pin in kids(unit,'pin'):
        if val(child(pin,'number')[1])=='SH':child(pin,'number')[1]='"S1"'
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

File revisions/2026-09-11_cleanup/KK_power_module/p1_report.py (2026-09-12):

"""Publish an explicitly non-release review from current native check artifacts."""
from pathlib import Path
import json, hashlib
ROOT = Path(__file__).resolve().parent
OUT = ROOT / 'P1_revision'
d = json.loads((OUT / 'design.json').read_text())
v = json.loads((OUT / 'VERIFICATION.json').read_text())
drc = json.loads((OUT / 'placement_drc.json').read_text())
for name, expected in v['checked_artifact_sha256'].items():
    assert hashlib.sha256((OUT / name).read_bytes()).hexdigest() == expected, 'Stale verification: ' + name
parts = d['components']
errors = [x for x in drc['violations'] if x['severity'] == 'error']
warnings = [x for x in drc['violations'] if x['severity'] == 'warning']
opens = drc.get('unconnected_items', [])
parity = drc.get('schematic_parity', [])
erc = (OUT / 'erc.rpt').read_text()
assert 'Errors 0  Warnings 0' in erc, 'ERC not clear'
assert not parity, 'Schematic/PCB mismatch: regenerate checks before publishing'
report = f'''# Keychain Kreatures power module P.1 — engineering review

2026-09-11. **NOT FOR FABRICATION. Not a tested or finished power module.**

## What is saved

The native [KiCad project](KK_power_module.kicad_pro), [schematic PDF](SCHEMATIC_DRAFT.pdf), [candidate BOM](BOM_DRAFT.csv), [native ERC report](erc.rpt), [native PCB DRC report](placement_drc.json), and [independent connectivity/calculation audit](VERIFICATION.json) are in this folder. Manufacturer datasheet links are in the BOM and [source index](datasheets/sources.json); this is not a complete set of locally downloaded PDFs.

The root legacy power project and the C.5 main PCB remain unchanged. The legacy manufacturing ZIP is **not compatible with C.5** and must not be ordered for this assembly.

## USB-A and USB-C decision implemented in the draft

| Source | Intended behavior | Important limitation |
|---|---|---|
| Powered computer USB-A, A-to-C cable | Approximately 50 mA nominal charger-input limit; slow charge with toy off | Playing may consume more than the port supplies; no host enumeration or suspend detection |
| USB-C advertising default current | Same conservative input mode | A USB-C connector alone does not authorize higher current |
| USB-C advertising 1.5 A or 3 A | Approximately 1 A nominal input limiter; about 297 mA nominal cell-charge setting | Available charging decreases with system demand and thermal/input regulation |
| Sleeping, switched-off or disabled computer port | Not guaranteed to charge | No promise that VBUS remains present or that this is universally host-compliant |

D+/D− and SBU are deliberately unconnected. No ESP32 data cable, USB-PD voltage request, or BC1.2 charger detection is implemented. This is not USB certification or universal compatibility approval.

U3 TUSB320LAI decodes the USB-C current advertisement. U13 **TPS22950YBHR** provides a separate low-current input limit; the TPS22950C/L variants are not interchangeable at this setting. Its 0.4 mm-pitch WCSP requires factory SMT assembly. U14 TLV75533PDBVR powers the CC circuitry at 3.3 V: raw USB must not feed a detector whose recommended VDD maximum is 5 V. CC pullups use that same rail. Q4/Q5 AO3400A have specified 2.5 V gate-drive operation.

The TPS22950 datasheet gives 34–66 mA at the exact 19.2 kΩ setting under its stated test conditions. The resistor-tolerance screening maximum is about 66.1 mA. A **10 mA overhead allocation** leaves a screening total of about 76.1 mA; that allocation is not a validated bound on CC, LED, TVS and LDO current. Plug-in inrush and current-mode transitions still require measurement.

## Output connection — unchanged main-board interface

Connect power-module J3 to main-board J1 by **pin number**, not wire color or a visual left-to-right guess.

| J3 pin | Main J1 pin | Net | Purpose |
|---|---|---|---|
| 1 | 1 | MCU_5V | Regulated nominal 5.0 V |
| 2 | 2 | GND | Protected common ground |
| 3 | 3 | LOGIC_3V3 | Regulated nominal 3.3 V |
| 4 | 4 | ACT_3V2 | Regulated nominal 3.2 V |

The output connector is JST-XH four-pin. J2 is a **different, higher-current JST-VH two-pin battery connector**; it does not reuse the old PH/XH battery harness. J4 is the two-pin PH thermistor connector. J5 carries service signals at USB/battery-related levels and is **not a direct ESP32 GPIO header**.

BAT_NEG is the cell-side negative connection, not protected GND. Do not bridge these with wiring, a scope ground or a thermistor return: that can bypass low-side cell protection. Use isolated/differential measurements where required. Do not power the ESP32 USB socket and the main supply together until reverse-feed behavior is qualified.

## Circuit changes represented

- BQ24074 charger/power path replaces the legacy part for the screened load envelope; temperature sensing is retained.
- SW1 now carries control current, not the whole toy's current. Charging is intended to remain available with the toy off.
- TPS259530 provides electronic switching, controlled turn-on, current limiting and normal undervoltage shutdown.
- Three TPS63060 buck-boost channels generate the required rails. Forced PWM is selected to avoid relying on a wider power-save voltage tolerance.
- TPS386000 independently monitors raw rail voltages and is powered before the eFuse, keeping normal MR switching within its supply range. Converter PG outputs are diagnostics, **not** substituted for voltage supervision.
- Three TPS22918 output gates provide controlled rises and resistor-limited output discharge. Their common enable does not prove that ESP32/peripheral I/O sequencing is safe.
- DW01A is restricted to the linked H&M Semiconductor part. Three parallel Fortune FS8205 pairs and a 4 A fuse are candidates; current sharing, trip thresholds and fuse coordination are not yet qualified.
- {v['test_pad_count']} labeled test pads expose rails, protected/cell grounds, controls and fault signals. USB-C now faces the top edge; the side switch actuator faces outward.

## Checks completed — and their limits

| Check | Current result |
|---|---|
| Native schematic ERC | 0 errors, 0 warnings under project settings |
| ERC checks not evaluated | Single-use global labels, four-way joins, SPICE models, footprint filters; see ERC report |
| Native netlist vs design manifest | {'PASS' if v['static_connectivity_pass'] else 'FAIL'} |
| Independent four-wire mapping to C.5 | PASS |
| Symbol pin sets vs footprint pad numbers | PASS; not a dimensional or solderability approval |
| Native schematic/PCB parity | {len(parity)} issues |
| Placement DRC | {len(errors)} errors, {len(warnings)} warnings |
| Independent USB copper-to-NPTH check | {len(v['independent_USB_hole_clearance_issues'])} pad/hole pairs below the current 0.25 mm rule; manual hold |
| Unconnected PCB items | {len(opens)} — expected because the PCB is unrouted, not waived |
| Hardware measurements / switching simulation | Not performed |
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

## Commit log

2026-07-10 Keychain Kreatures Boiler plate
    [3006.step, ESP32-C3_SUPERMINI_SMD.step, ESP32-C3_SUPERMINI_TH.step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]
2026-09-10 recovered power module
    [KK_power_module.dsn, KK_power_module.kicad_pcb, KK_power_module.kicad_sch]
2026-09-12 Release C6 main and P3 power prototype projects and refresh documentation
    [3006.step, Adafruit3101_soft.step, BOM_AND_PLACEMENT.csv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]
2026-09-13 Release compact P4 power with C6 pairing files and organized project roots
    [Adafruit3101_soft.step, BOM_AND_PLACEMENT.csv, BOM_DRAFT.csv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]
2026-09-13 Add student troubleshooting guides and factory fault reporting packet
    [TROUBLESHOOTING_C6_CHECKLIST.csv, TROUBLESHOOTING_C6_MEASUREMENTS.csv, TROUBLESHOOTING_P4_CHECKLIST.csv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]
2026-09-14 updates to full project
    [ATTACH_THT_MIXED_OPERATIONS_MM.csv, CONNECTOR_PIN_MAP.csv, DFM_RESPONSE_CHECKLIST.csv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]
